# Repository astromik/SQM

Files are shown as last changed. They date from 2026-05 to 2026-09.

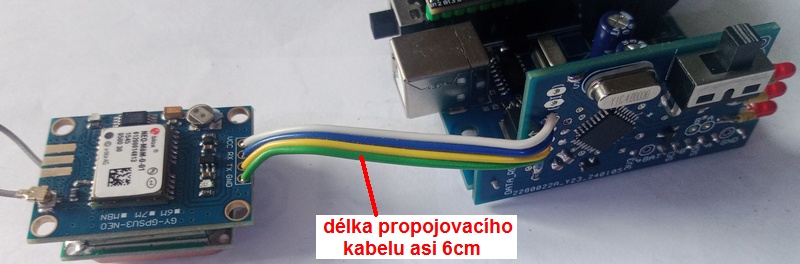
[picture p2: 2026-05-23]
SQM_verze411/webconfig/fot_gps_propoj.jpg

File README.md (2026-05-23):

<B>Amatérské SQM - Sky Quality Meter</B><br><br>Levnější a funkčně více vybavená náhrada za profesionální měřič kvality oblohy od Unihedronu postavená na procesoru STM32F411CEU s využitím modulu pro měření jasu TSL2591.

- Záznamy se ukládají na SD kartu (čitelný CSV formát) a do vnitřní EEPROM, ze které je možné záznamy exporovat.<br>
- Měření teploty, tlaku a vlhkosti.<br>
- K záznamům se přidávají GPS souřadnice a směr měření (azimut a  elevace).<br>
- Astronomické výpočty (poloha Slunce, Měsíce, planet, vybrané DSO).<br>
- Komunikace přes RS485 (modbus), nebo přes USB.<br>
- Možnost automatického měření v nastavených intervalech.<br>
- Další drobné funkce (stopky, budík, časová značka, červená lampička, GPX trasovací soubor).<br>
- Kalibrace pomocí porovnání s originálním (přesným) SQM přes editovatelné kalibrační tabulky.

Web: http://sqm.astromik.org/<br><br>

sqm411

sqm411-vnitrek

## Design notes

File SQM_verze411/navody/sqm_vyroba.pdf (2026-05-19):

# Měřič kvality oblohy

# (amatérské SQM)

# Popis HW a výroba

http://sqm.AstroMiK.org

## STM32F411CEU

SW: | STM32 | 2026-05-18 (STM32F4x1)
| ATmega328 | 2026-05-17..INT
PCB: | základní deska | SQM-BAS-7
| deska vnitřního GPS | SQM-GPS-6
| deska displeje | SQM-DIS-3
3D tisk: | krabička + podstavec | SQM-96

19.5.2026

Strana 1/61

## OBSAH

## Úvod

Tato část návodu popisuje výrobu SQM včetně mechaniky a nahrání programu, testování jednotlivých částí a případné opravy, když něco nebude fungovat.

## Rozšiřující bloky

V prvním plánu bylo vytvoření pouze dvou variant SQM:
- Ruční přístroj s displejem, tlačítky a možností osazení GPS, který bude používán v terénu.
- Pevně nainstalovaný přístroj s minimálním vybavením, který bude komunikovat dálkově přes RS485.

Později bylo toto rozdělení přepracováno tak, aby si uživatel mohl zvolit rozsah požadovaných funkcí. Zvolené funkce mají samozřejmě vliv na celkovou cenu, i když v některých případech jsou to spíše desetikorunové částky.

V té nejořezanější verzi je možné jen po stisknutí tlačítka (nebo v automatických intervalech) změřit jas, uložit hodnotu do paměti
a přes USB sériovou linku pak uložené záznamy z paměti stáhnout do počítače.
Není k dispozici ani displej, který by hodnotu ukazoval a jedinou signalizací je (nepovinná) RGB LED, která barvami signalizuje základní stavy (probíhající měření, chyby).

V maximální verzi se změřené záznamy zobrazují na displeji, ukládají se kromě paměti i na SD kartu a zároveň se měří teplota, tlak a vlhkost.
K záznamům se přidávají i GPS souřadnice, směr namíření čidla (azimut a elevace).
Data je možné stahovat dálkově přes průmyslovou sběrnici RS485 (protokol modbus RTU).
Přes modbus je možné nastavovat i některé systémové parametry (čas, úrovně ukládání hodnot, změnu časové zóny ...).
Když je osazený displej, je možné zobrazit i astronomické výpočty (polohy Slunce a Měsíce, časy soumraků pro zvolenou polohu, polohy a časy východů a západů planet), nebo listovat ve starších záznamech (záznamy se v tom případě zobrazují na displeji ve zjednodušeném formátu).
Osazená akustická signalizace může hned při měření upozornit na nestabilní měřené hodnoty nebo na vybitou baterii.
Rozšíření o alarmové funkce z SQM vytvoří budík, který se v nastavený čas spustí i při vypnutém hlavním vypínači.

Protože možných kombinací rozšíření je strašně moc (2^13 = 8192 různých kombinací), připravil jsem webovou stránku,
na které se pomocí zaškrtávacích políček zvolí požadovaná rozšíření a podle zvolené verze se automaticky připraví balík výkresové dokumentace pro osazení desek včetně seznamu součástek pro konkrétní zvolenou variantu.
Součástí balíku jsou také náčrtky připojení vnějších spojů (tlačítka, napájení, svorkovnice ...) a fotografie některých detailů osazení.

Dále jsou v balíku i podklady pro výrobu plošných spojů ve formátu pro Eagle a výstupní gerberovské soubory pro výrobu například tady: https://jlcpcb.com

Webový formulář pro konfiguraci rozšiřujících funkcí je zde: http://astromik.org/raspi/sqm/verze411/webconfig/

## Výroba

Webový konfigurátor

Výroba začíná volbou požadovaných funkcí na stránce:

http://astromik.org/raspi/sqm/verze411/webconfig/

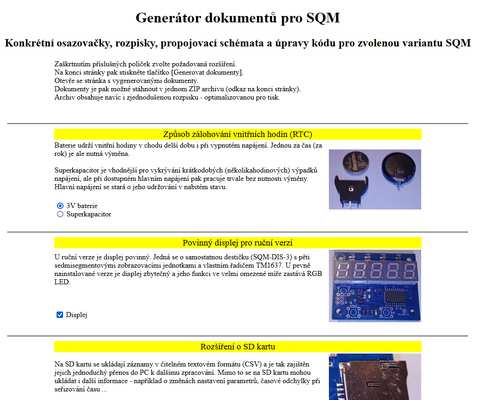
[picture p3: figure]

Po stisku tlačítka "Generovat dokumenty" na konci stránky se připraví rozpisky a osazovačky pro zvolenou variantu.

POZOR

Mechanika je v rozpiskách zpracována pouze pro ruční verzi.
V případě pevně nainstalovaného přístroje si musí uživatel s mechanikou poradit sám.

Tuto pevnou variantu jsem zatím mechanicky neřešil.

Pravděpodobně to bude nějaká vodotěsná krabička, do které budou přes průchodky přivedena čidla a napájení s komunikací. Samotná čidla také musí být nějakým způsobem ochráněna před počasím.

Protože se u pevně nainstalované varianty nepočítá s displejem, měla by být zvenku vidět alespoň signalizační RGB LED.

Tlačítka nejsou v této verzi důležitá, ale pro případný servis (testování čidel, spuštění zkušebního měření, test nastaveného času,...) by uvnitř krabičky mohla být nějaká miniaturní tlačítka (nebo alespoň rozumně zkratovatelné kontakty) umístěná.

Čidla světla a teploty komunikují na společné I²C sběrnici a mohly by být vyvedeny přes jednu průchodku (připojeno místo konektoru EXT). Délka kabelu k čidlům by neměla být moc dlouhá. I²C sběrnice se používá obvykle jen pro komunikaci uvnitř krabice, takže délka by neměla přesáhnout několik desítek centimetrů.

Komunikační (RS485) a napájecí kabel (například UTP kabel SXKD-5E-UTP-PE) by byl přiveden do krabičky přes druhou průchodku (připojeno ke svorkovnicím K1+K2).

schématické uspořádání v pevně nainstalované verzi (bez GPS)

## Osazení desek

Osazení desky SQM-BAS

Před osazením desek si projděte poznámky před osazením. Je tam upozornění na některé detaily, které by mohly být problematické.

Osadit desku SQM-BAS-7 podle požadovaných funkcí.
Přídavné moduly čidel ale zatím neosazovat.
Nepřipojovat ani další přídavné desky (SQM-GPS-6 ani SQM-DIS-3). Nevkládat do patice procesorovou desku BlackPill.
Nepřipojovat žádná tlačítka ani konektory (DC-JACK, 9V klip). Nevkládat SD kartu.
Pokud je osazena verze s 3V zálohovací baterií, tak ji také nevkádat do držáku.

V tomto stavu se později budou provádět základní testy zdrojové a komunikační části desky SQM-BAS-7.
Popsáno v odstavci "Samostatná deska SQM-BAS"

Osazení desky SQM-DIS

Pokud bude použita deska displeje, osadit ji podle dokumentace. Nepájet propojovací piny JP1-M a JP2-M.
Jejich délka se nastaví až na závěr při sestavení s deskou SQM-BAS-7 přes distanční sloupky.

Osazení desky SQM-GPS

Pokud bude použita deska zpracování GPS dat (SQM-GPS-6), osadit ji podle dokumentace. Pozor hlavně na propojovací lištu JPx-M a vdálenost LED od desky.
Detaily v poznámkách před osazením.

Naprogramovat procesor Atmega328 v desce SQM-GPS-6. Popsáno v kapitole "Nahrání programu do desky SQM-GPS"

Vypájet provizorní programovací piny.

Pomocí 4-žilového plochého kablíku (délka asi 6cm) propojit desku SQM-GPS-6 s modulem NEO6-M

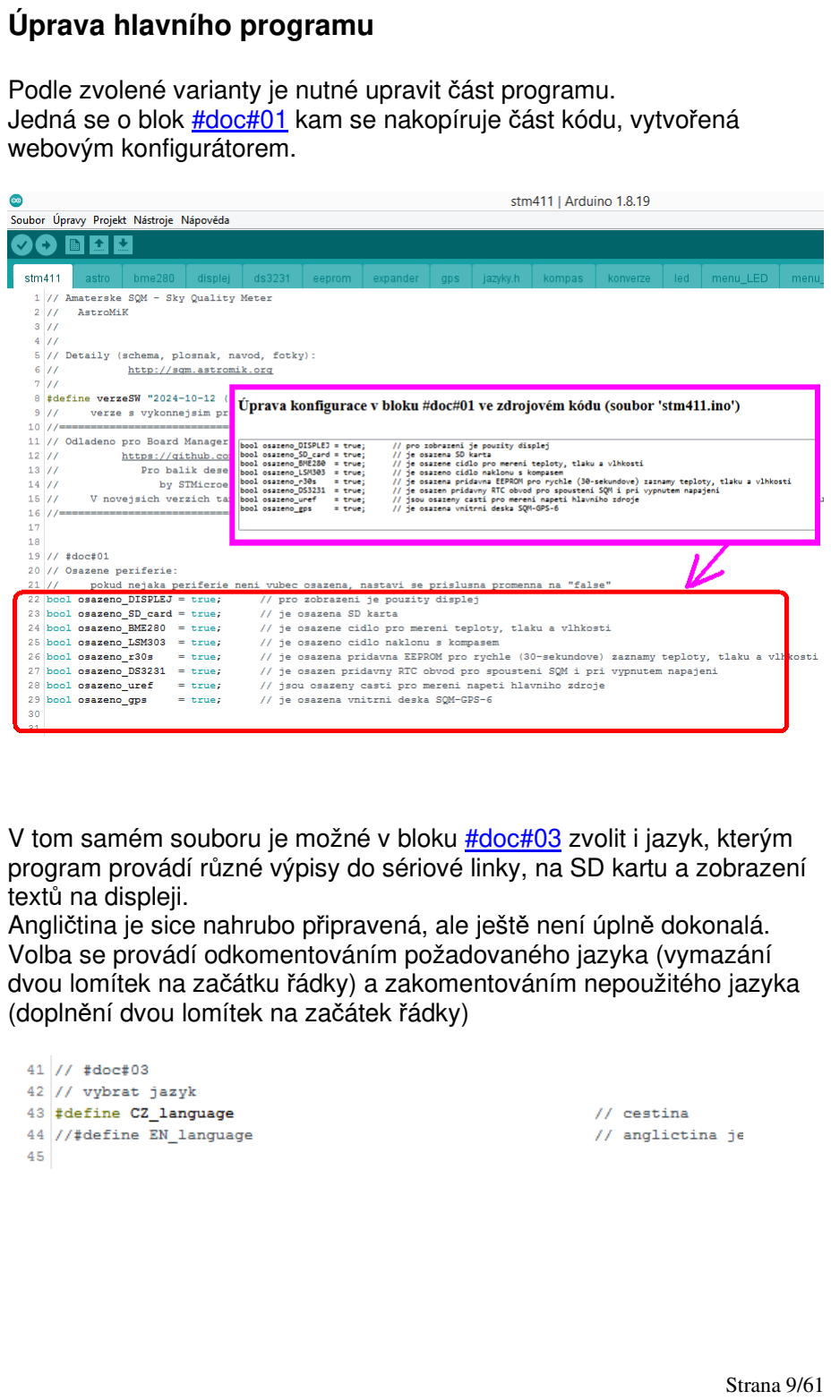
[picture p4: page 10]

Úprava hlavního programu

Podle zvolené varianty je nutné upravit část programu.
Jedná se o blok #doc#01 kam se nakopíruje část kódu, vytvořená webovým konfigurátorem.

V tom samém souboru je možné v bloku #doc#03 zvolit i jazyk, kterým program provádí různé výpisy do sériové linky, na SD kartu a zobrazení textů na displeji.
Angličtina je sice nahrubo připravená, ale ještě není úplně dokonalá. Volba se provádí odkomentováním požadovaného jazyka (vymazání dvou lomítek na začátku řádky) a zakomentováním nepoužitého jazyka (doplnění dvou lomítek na začátek řádky)

Program je přednastavený pro ukládání hodnot všech (i nepoužitých) čidel do EEPROM. V bloku #doc#05 je možné pro nepoužitá čidla ukládání omezit.

Detailní postupy pro úpravy konfigurace programu jsou uvedeny
v samostatném programovacím návodu
(soubor "sqm_program.doc").

Úprava desky BlackPill

Procesorová deska BlackPill musí mít boční piny (GND, SWSCK, SWDIO a 3V3) osazené směrem dolů (stejně jako ostatní piny).

Pro správné měření napětí 3V zálohovací baterie je nutné uříznout na desce BlackPill nohu na diodě D3 (na některých schématech označovaná jako D1) - BAT54C. Tato dioda slučuje napájení procesoru a 3V zálohovací baterii do měřícího vstupu. Bez této operace by se místo napětí baterie měřilo napájecí napětí procesoru.

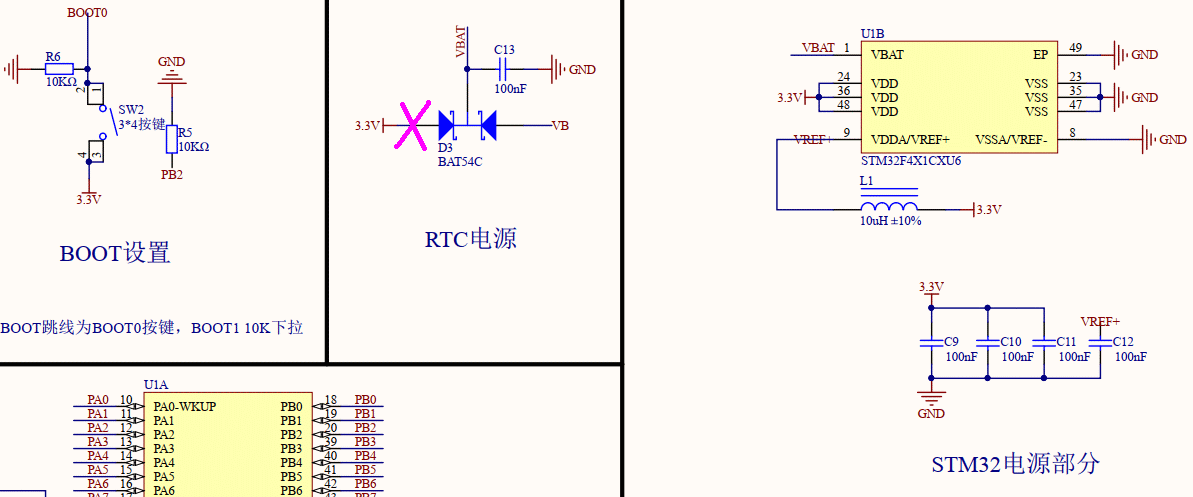
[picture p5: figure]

Část schématu s naznačeným přerušením napájecí sběrnice 3,3V a vstupem pro měření napětí baterie VBAT

Detail přerušení anody u dvojdiody D3 (někde označovaná jako D1)

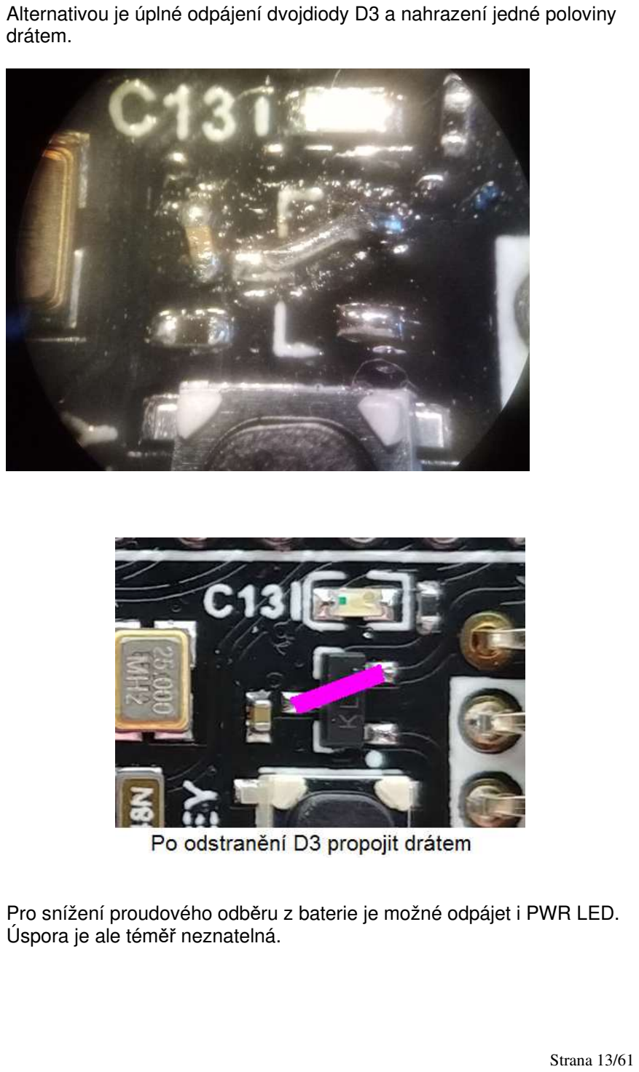
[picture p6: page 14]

Alternativou je úplné odpájení dvojdiody D3 a nahrazení jedné poloviny drátem.

Pro snížení proudového odběru z baterie je možné odpájet i PWR LED. Úspora je ale téměř neznatelná.

## Nahrání a případná aktualizace programů

Nahrání programu do desky BlackPill

V první řadě je nutné připravit Arduino IDE na práci s procesory STM. Na internetu je možné najít množství přesných návodů s různými verzemi knihoven na rozšíření IDE pro práci s procesory STM.
Já jsem jako základ použil tenhle: https://www.sgbotic.com/index.php?dispatch=pages.view&page_id=49

Je ale už trochu zastaralý, takže je třeba nastavit jinou URL správce desek.

Postup je následující (odzkoušeno na Arduino IDE verze 1.8.19; Windows 8.1 - 64-bit):

1) V menu "Soubor" -> "Vlastnosti" nastavit URL správce dalších desek:
https://github.com/stm32duino/BoardManagerFiles/raw/main/package_stmicroelectronics_index.json
2) v menu "Nástroje" -> "Vývojová deska" -> zvolit "Manažer desek" Do vyhledávacího políčka zadat: STM
Měla by se zobrazit knihovna STM32MCU based boards. Nainstalovat STARŠÍ verzi 2.6.0! V nových verzích pořád něco upravují a já už nemám sílu neustále program přizpůsobovat.)

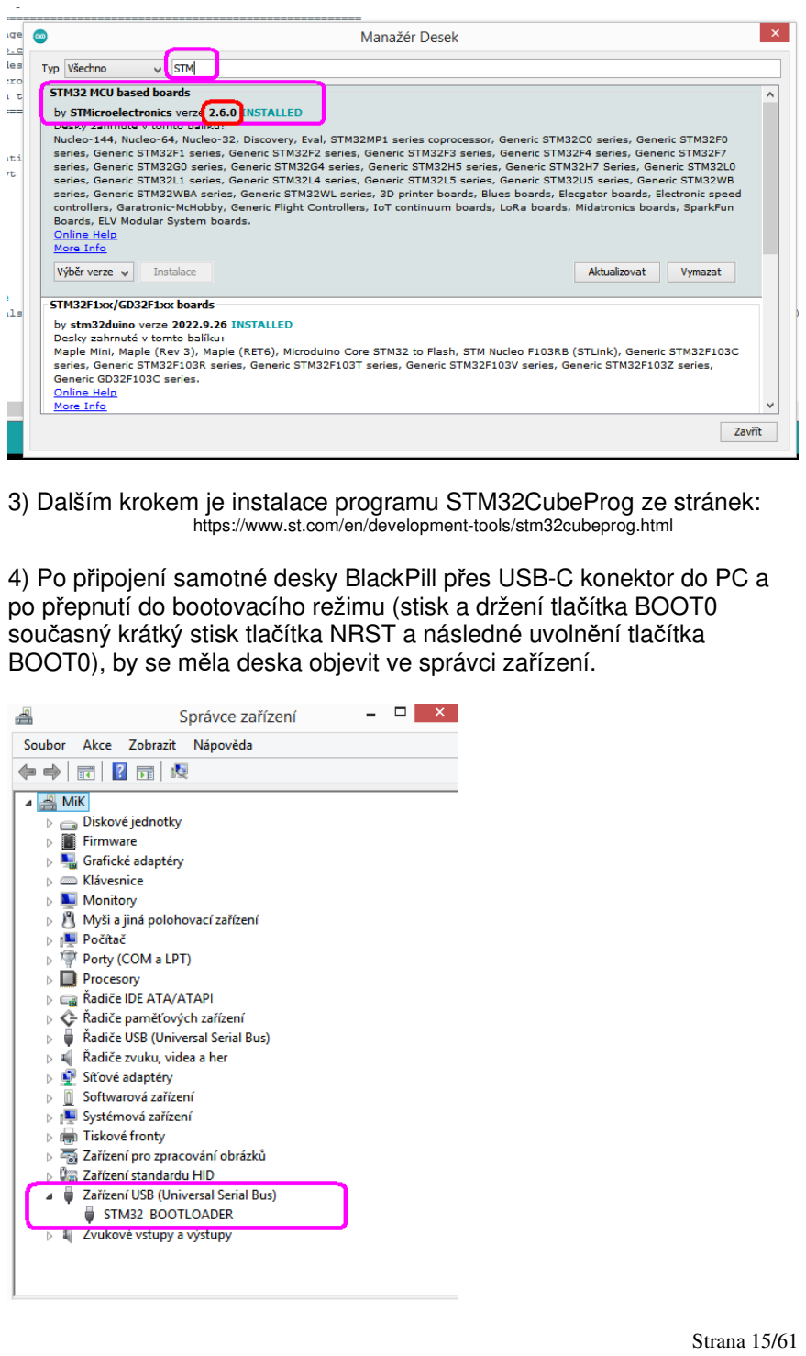
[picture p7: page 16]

3) Dalším krokem je instalace programu STM32CubeProg ze stránek:
https://www.st.com/en/development-tools/stm32cubeprog.html
4) Po připojení samotné desky BlackPill přes USB-C konektor do PC a po přepnutí do bootovacího režimu (stisk a držení tlačítka BOOT0 současný krátký stisk tlačítka NRST a následné uvolnění tlačítka BOOT0), by se měla deska objevit ve správci zařízení.

5) Do složky "Dokumenty\Arduino\Libraries\" nakopírovat potřebné knihovny:
6) Pak už stačí v menu Arduino IDE nastavit správný typ procesoru na desce BlackPill (STM32F411CEU, nebo STM32F401CEU) a parametry.
7) V menu "Projekt" zvolit položku "Nahrát". Proběhne kompilace následovaná nahráním programu do procesoru.

Takto by mělo vypadat hlášení po úspěšném nahrání programu
do procesoru STM32F401 (pro verzi "2024-10-12"):

Projekt zabírá 228920 bytů (43%) úložného místa pro program. Maximum je 524288 bytů.
Globální proměnné zabírají 8816 bytů (8%) dynamické paměti, 89488 bytů zůstává pro lokální proměnné. Maximum je 98304 bytů. -------------------------------------------------------------------STM32CubeProgrammer v2.14.0 -------------------------------------------------------------------
USB speed | : Full Speed (12MBit/s)
Manuf. ID | : STMicroelectronics
Product ID | : STM32 | BOOTLOADER
SN | : 3395364B3334
DFU protocol: 1.1
Board | : --
Device ID | : 0x0433
Device name : STM32F401xD/E Flash size : 8 MBytes (default) Device type : MCU
Revision ID : --
Device CPU : Cortex-M4

Memory Programming ...
Opening and parsing file: stm411.ino.bin
File | : stm411.ino.bin
Size | : 224.01 KB
Address | : 0x08000000

Erasing memory corresponding to segment 0: Erasing internal memory sectors [0 5] erasing sector 0000 @: 0x08000000 done erasing sector 0001 @: 0x08004000 done erasing sector 0002 @: 0x08008000 done erasing sector 0003 @: 0x0800c000 done erasing sector 0004 @: 0x08010000 done erasing sector 0005 @: 0x08020000 done Download in Progress:

File download complete
Time elapsed during download operation: 00:00:22.209

RUNNING Program ...
Address: | : 0x8000000
Start operation achieved successfully
Kdyby bylo nutné v budoucnu aktualizovat program v zasunuté procesorové desce BlackPill, je třeba vypnout vypínač na GPS desce. Zapnutá GPS blokuje nahrávání programu přes USB-C.

Vyzkoušel jsem také použití novějšího Arduino IDE (2.3.7) a instalace rozšíření o desky STM32F4xx probíhá podobně.

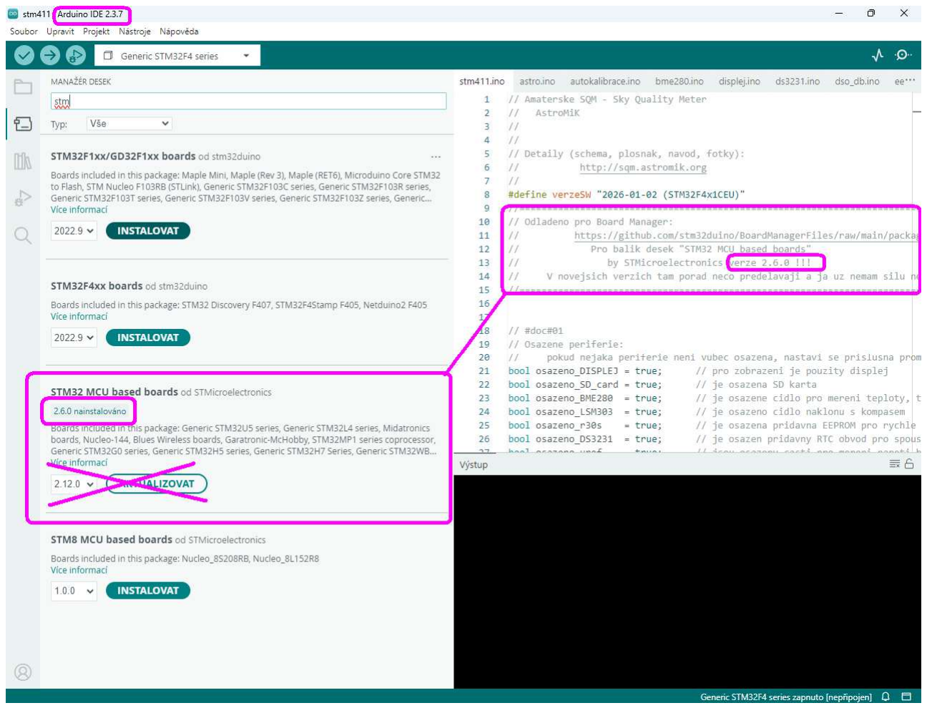
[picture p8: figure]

Osobně ale raději pracuji ve starém Arduino IDE 1.8.xx.

Nahrání programu do desky SQM-GPS

Dočasně přenastavit konfigurační soubor pro Arduino UNO tak, aby pracoval na 4MHz.
Ve Windows se to provede úpravou souboru:
C:\Program Files (x86)\Arduino\hardware\arduino\avr\boards.txt

V sekci "Arduino Uno" se upraví hodnota
"uno.build.f_cpu" z 16000000L na 4000000L

POZOR:
Umístění souboru boards.txt může být i jiné.
Po nějakém čase jsem chtěl aktualizovat program a umístění souboru se změnilo:
C:\Users\astromik\AppData\Local\Arduino15\packages\arduino\hardware\avr\1.8.4\boards.txt

Přes ISP piny (MISO,MOSI,SCK,RST) nahrát do ATmega328 program "gps_int.ino" (v nastavení desky zvolit "Arduino UNO")

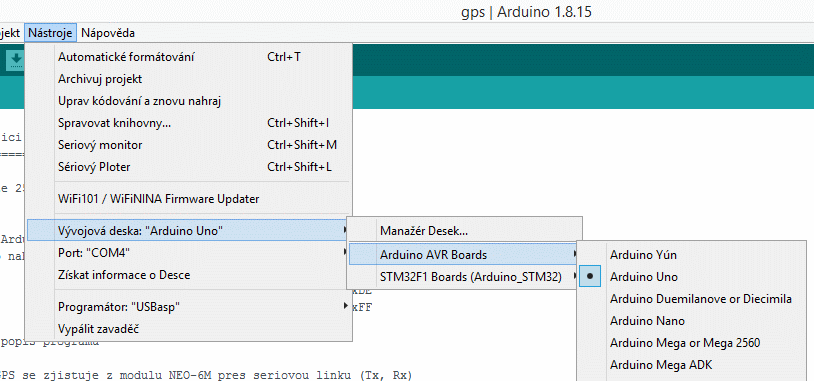
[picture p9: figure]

Vrátit zpět úpravu konfiguračního souboru "boards.txt".

Program pro ATmega328 je připraven ke stažení i v HEX formátu, který je možné nahrát do procesoru přes AVRDUDE. V tom případě není nutné používat Arduino IDE.

Potom přes AVRDUDESS změnit FUSE:
z původních -->> | na nové
L: 0xF7 | L: 0xDC
H: 0xD9 | H: 0xDE
E: 0xFC | E: 0xFF

Po nahrání programu do desky SQM-GPS a úpravě FUSE bajtů vypnout napájení programátoru.

POZOR:
Pokud by bylo třeba přeprogramovat desku SQM-GPS až po připájení k SQM-BAS, je nutné, aby byl vypínač na desce SQM-GPS v poloze VYPNUTO!
Programátory mohou používat napájecí napětí 5V. Procesoru ATmega328 na desce SQM-GPS toto napětí nevadí, ale při sepnutém vypínači by se těch 5V přeneslo i na ostatní čidla a procesor STM32F411, které jsou dimenzovány pouze na 3,3V. Tím by pravděpodobně došlo k jejich zničení.

Nastavení konfigurace GPS

Při vypnutém napájení propojit pinzetou servisní pin na horní straně desky SQM-GPS a následně napájení programátoru opět zapnout.

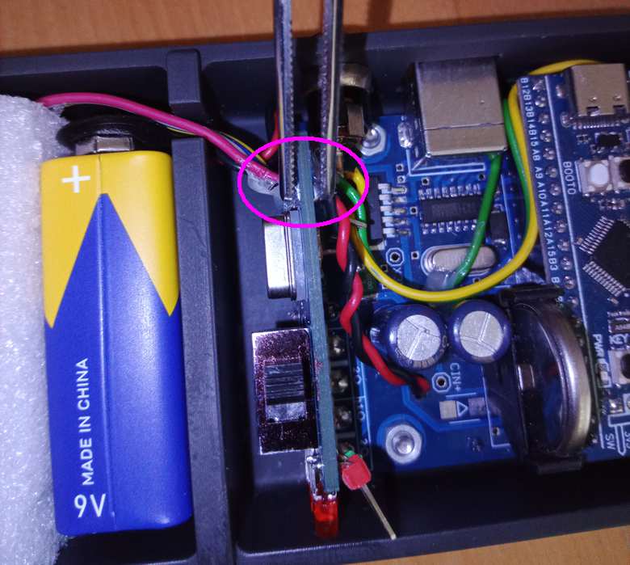
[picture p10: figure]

Operace se provádí na samotné desce GPS, která ještě není připojena do BAS. Tato fotografie byla pořízena až po propojení desek BAS a GPS.

Po zapnutí napájení se sepnutým servisním kontaktem by měly nejdřív 5x bliknout všechny LED frekvencí 1Hz (střída 50%).
Pak se začnou pomalu postupně rozsvěcet a zhasínat.
Při tom je možné propojovací pinzetu odstranit.
Asi po 30 sekundách se znovu rozblikají všechny LED (střída 10%).

Tím je provedena základní konfigurace GPS modulu (zablokování nechtěných NMEA zpráv a povolení zpráv GxGGA a GxRMC).

Vypnout napájení programátoru.

Odpojit ISP vodiče a případně i vypájet ISP piny.

Plochý kablík z modulu NEO-6 připájet k desce SQM-GPS-6

Při dalším zapnutí napájení bez zkratované servisní propojky už bude GPS deska pracovat normálně. První LED zdola bliká frekvencí 1Hz, ostatní LED nejdřív svítí a po zafixování družic postupně zhasnou. Zafixování může trvat i delší dobu v závislosti na počasí a výhledu na oblohu.

Kvůli novějším GPS modulům NEO, které nemají EEPROM, do které by se ukládala konfigurace, se v posledních verzích FW při každém zapnutí napájení nastavuje konfigurace znovu. Je to ale ve zrychleném režimu který je signalizován postupným rozsvěcením bočních LED.

Ukázkové video:
https://youtu.be/Dz852uCeeco

## Testy samostatných desek

Samostatná deska SQM-BAS

POZOR!
V této fázi:
- nevkládat modul s procesorem
- nevkládat SD kartu
- nepřipojovat čidlo světla ani čidlo teploty / vlhkosti / tlaku
- nepřipojovat čidlo náklonu / kompas
- nepřipojovat desku SQM-DIS
- nepřipojovat desku SQM-GPS

Na následujících fotografiích mohou být vidět některé z těchto věcí připojené, ale je to z toho důvodu, že návod vznikal dodatečně -
až s hotovým zařízením.
1) Kontrola zkratu na napájení. Stačí ohmmetrem vyzkoušet, že není zkrat mezi body "XG" a "X3V". Přesnou hodnotu odporu tu uvádět nebudu, asi se bude hýbat podle toho, jak se budou nabíjet napájecí kondenzátory. V žádném případě to ale nesmí být zkrat. Rizikové oblasti, kde se napájecí cesta přibližuje ke GND, jsou hlavně kolem držáku SD karty a RGB LED. Stalo se mi, že k nechtěnému zkratu došlo později, při pájení modulu s čidlem světla.

Tento test je proto vhodné provádět i po připojení každého dalšího čidla. Zkrat na napájení se hledá dost těžko a obvykle je nutné hledat ho pomocí odřezávání částí cestiček na DPS.

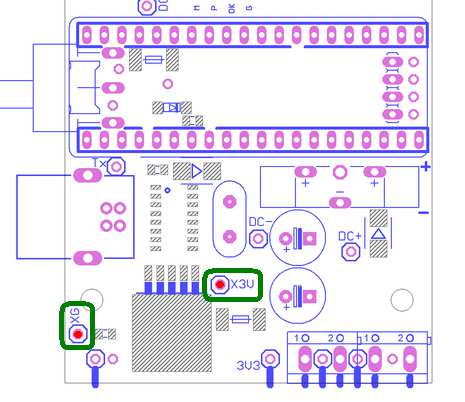
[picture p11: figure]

poloha měřících bodů XG a X3V

2) Kontrola DC-DC převodníku:
- Připojit voltmetr mezi body "XG" a "X3V".
- Připojit 9V baterii nebo zdroj do svorek "V" a "G" na svorkovnicích K1 a K2 (pokud svorky nejsou osazeny, připájet napájecí vodiče zdroje do dírek "V" a "G").
- Hlavní boční přepínač přepnout do polohy "zapnuto".
- Voltmetr musí ukazovat 3,3V s minimální tolerancí.
- Místo baterie připojit regulovatelný zdroj napětí 3 až 30V.
- Když vstupní napětí překročí 4,5V, musí být napětí
na voltmetru (v bodě "X3V") stále 3,3V.
Pod 4,5V může napětí na voltmetru začít klesat.
3) Kontrola reference a děliče R7/R8:

Od vstupního napětí alespoň 4V by mělo být na pinu PB0 proti GND vždycky 1,8V.
Na pinu PA0 by mělo být proti GND napětí, které je asi 8% ze vstupního napětí (teoreticky je dělící poměr: 8,2 / 108,2 ).
Ani při 30V na vstupu nesmí toto napětí překročit 3,3V.

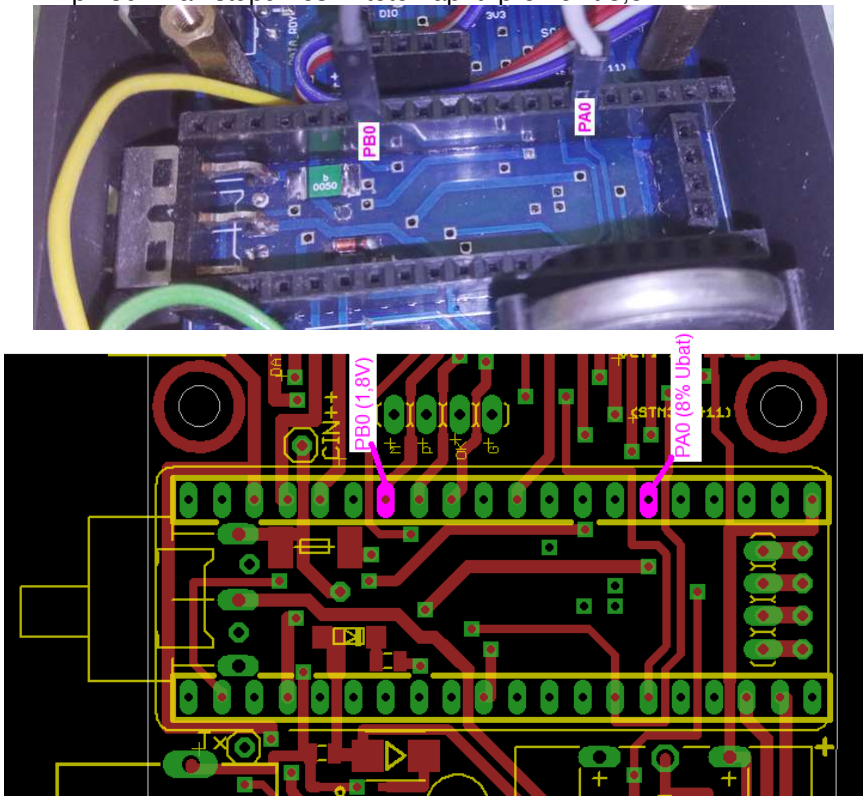
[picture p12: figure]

3) Kontrola ochrany přepólování:
Na svorky baterie připojit 30V v opačném směru.
Voltmetr nesmí mezi body "XG" a "X3V" ukazovat žádné napětí a odběr ze zdroje 30V musí být také nulový.
4) Kontrola USB komunikace:
Odpojit 9V baterii (nebo zdroj).
Stále bez zasunuté procesorové desky připojit USB konektor k počítači Měly by se nainstalovat ovladače pro převodník CH340.
Pokud se nenainstalují, postupovat podle:
https://havel.mojeservery.cz/ovladace-usb-serioveho-portu-s-cipsetem-ch340ch341-a-arduino-klony/

nebo:
https://blog.laskarduino.cz/instalace-ovladace-prevodniku-usb-na-uart-ch340/

Když instalace proběhne správně, propojit dírky v patici pro modul BlackPill na pozicích PA9 a PA10.

V počítači spustit sériový terminál, zvolit správné číslo právě vytvořeného sériového portu, nastavit rychlost na 9600.
Znaky, které se přes terminál odešlou do linky, se musí okamžitě vracet zpátky.

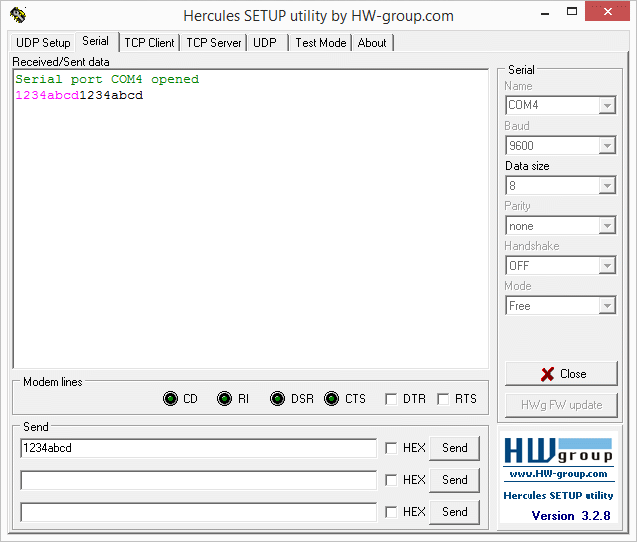
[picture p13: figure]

Vyzkoušet i vyšší rychlosti (až do 115200).

Zrušit propojku mezi PA9 a PA10.

Při připojeném USB kabelu ještě zkontrolovat voltmetrem napájecí napětí 5V pro procesorovou desku.

Na těchto pinech by mělo být po připojení USB kabelu napětí asi 5V

pohled opačným směrem (od čidla světla)

Samostatná deska SQM-DIS

V této fázi by neměly být ještě osazené kolíkové lišty.
Na samotné desce je možné zkontrolovat, že nemá zkratované napájecí cesty. Ostatní testy se provádí až později při spojení s SQM-BAS.

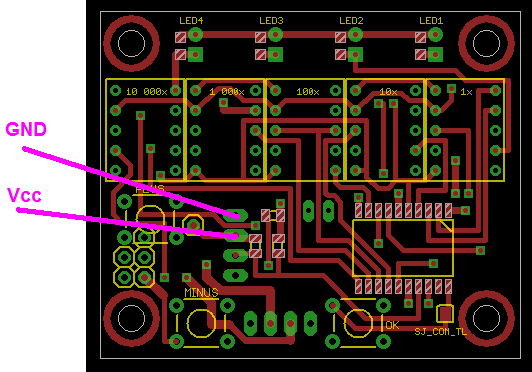
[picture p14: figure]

kontrola zkratu na napájecích pinech

Samostatná deska SQM-GPS

Deska SQM-GPS už by měla být otestována tím, že se podařilo nahrát program do procesoru ATmega328.
Okamžitě po zapnutí napájení mělo proběhnout postupné probliknutí všech LED.
Dalším testem je blikání spodní LED (pokud je připojený GPS modul NEO).

## Sestavení desek

V této kapitole předpokládám, že se jedná o plně vybavenou ruční verzi přístroje (displej, GPS, čidlo BME280, kompas + náklonoměr).
Pokud něco z toho není použito, tak není třeba se tím zabývat.

Pokud je použita deska displeje (SQM-DIS-3), provést sestavení desek SQM-BAS-7 + SQM-DIS-3 přes 15mm dlouhé sloupky.
Nepřipájené propojovací kolíky JP1-M a JP2-M, se při sešroubování desek vytlačí nad horní okraj desky SQM-DIS-3.
Přečnívající kolíky zastřihnout a připájet do SQM-DIS-3.
Tím je zajištěna správná délka propojovacích kolíků mezi deskami SQM-BAS a SQM-DIS

Displejovou desku s připájenými spojovacími piny odebrat aby byl prostor pro instalaci čidel.

K deskám začít připojovat použitá čidla
Pokud je k dispozici krabička, připájet čidlo světla (TSL2591) a v případě, že je použito, tak i čidlo teploty (BME 280).
U čidla světla věnovat zvýšenou pozornost správnému zamíření senzoru proti čočce, která je vlepená do krabičky.

Nejlepší postup je vlepit do krabičky čočku, přišroubovat základní desku bez čidel do krabičky, nastavit správný směr a vzdálenost čidla světla od čočky a připájet jeden vývod.

Podobně provést umístění i čidla teploty.
Když budou čidla správně umístěna, je možné vyndat základní desku z krabičky a dopájet zbylé vývody čidel.

Průběžně kontrolovat zkrat na napájecích vodičích mezi body "XG" a "X3V".

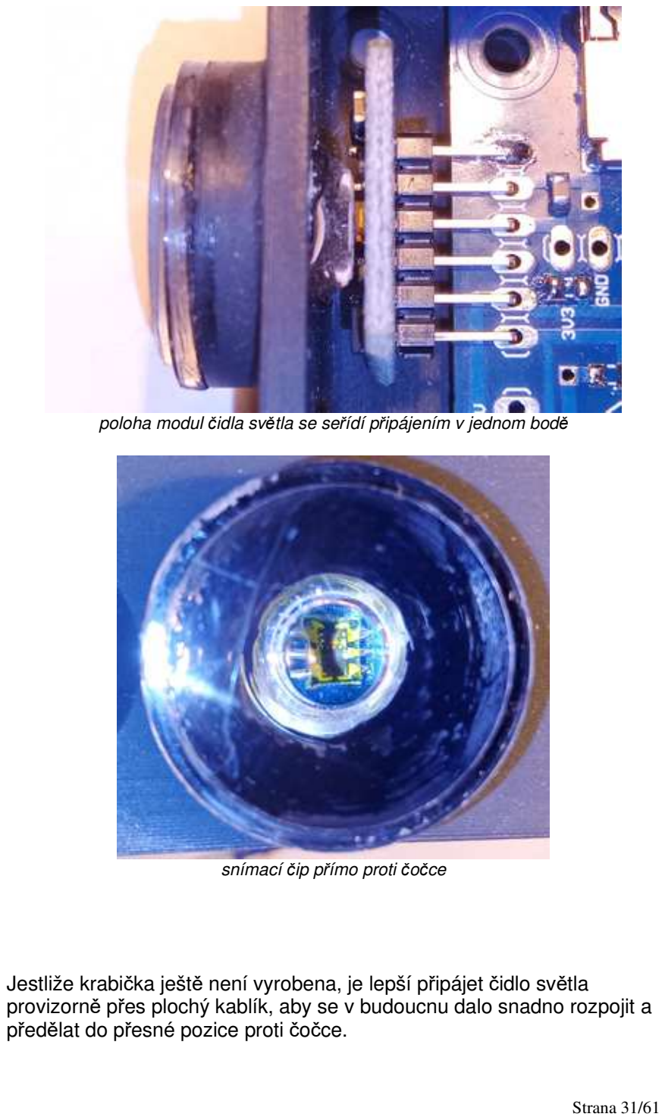
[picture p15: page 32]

poloha modul čidla světla se seřídí připájením v jednom bodě

snímací čip přímo proti čočce

Jestliže krabička ještě není vyrobena, je lepší připájet čidlo světla provizorně přes plochý kablík, aby se v budoucnu dalo snadno rozpojit a předělat do přesné pozice proti čočce.

Podobně postupovat i s čidlem BME - tam ale na přesnosti až tak moc nezáleží.

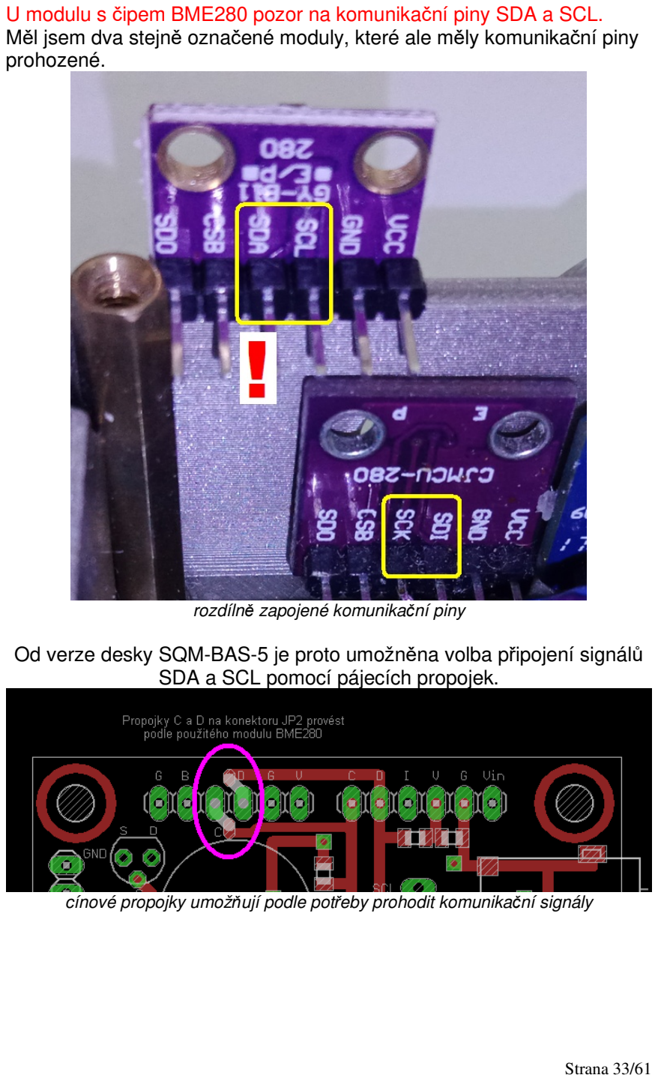
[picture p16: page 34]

U modulu s čipem BME280 pozor na komunikační piny SDA a SCL. Měl jsem dva stejně označené moduly, které ale měly komunikační piny prohozené.

rozdílně zapojené komunikační piny
Od verze desky SQM-BAS-5 je proto umožněna volba připojení signálů SDA a SCL pomocí pájecích propojek.

cínové propojky umožňují podle potřeby prohodit komunikační signály

pájecí propojky C a D propojené na správné piny

Když bude použit kompas s čidlem náklonu, připojit ho k desce SQM-BAS-7 přes 6cm dlouhý, 4-žilový plochý kablík.

Kablík nepájet skrz dírky do modulu, ale naplocho ze strany součástek, aby spodní strana zůstala rovná.

Modul LSM303 se ve finále přilepí (tavným lepidlem) na desku SQM-DIS (přímo na obvod pro řízení displeje TM1637).
Šroubek pro připevnění desky displeje pod modulem LSM303 nepoužívat. Mohl by ovlivňovat magnetické pole kompasu.

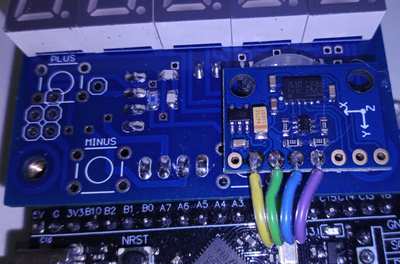
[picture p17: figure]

modul kompasu nalepený na displejové desce (na obvodu TM1637)

Sestavit všechny použité desky dohromady (SQM-BAS-7 + SQM-GPS-6 + SQM-DIS-3). Při sestavování SQM-GPS-6 a SQM-BAS-7 dbát na dokonalou kolmost obou desek, aby přepínač pasoval do otvoru v horním víku krabičky.

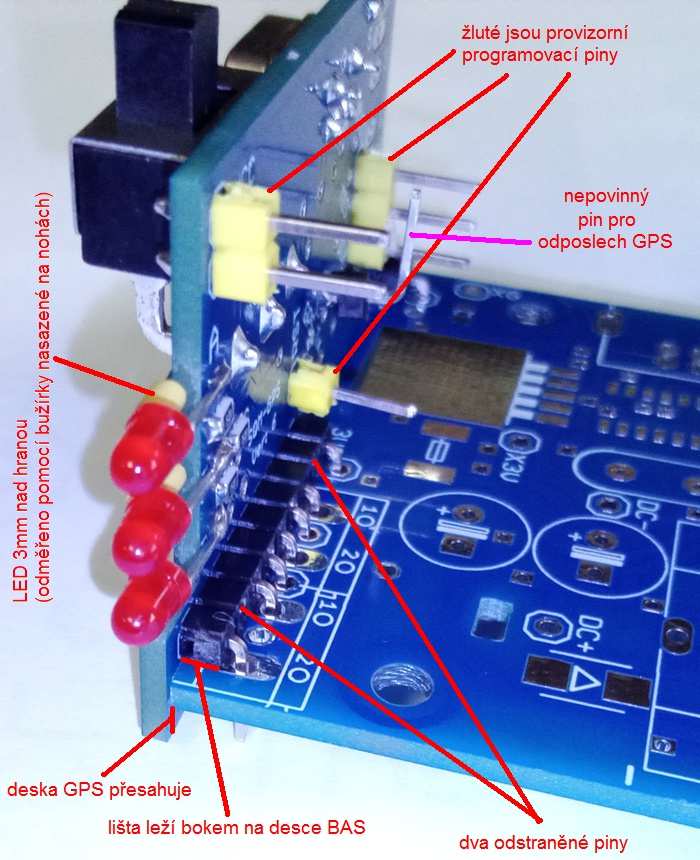
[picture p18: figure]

Zasunout naprogramovanou procesorovou desku BlackPill do patice. POZOR, ABY SE NEZASUNULA O PIN VEDLE!

Pro verzi s SD kartou si připravit zformátovanou kartu a nakopírovat na ni složku /HELP/, která obsahuje detailní popisy příkazů. Tyto popisy se pak mohou zobrazovat v sériovém terminálu.

Složka "HELP" je uložena na webu v adresáři s návody: http://astromik.org/raspi/sqm/verze411/download/navody/

Je tam i ZIP archiv celé složky pro jednodušší přenos. Tento ZIP je pak ale nutné na kartu ručně rozbalit.

Pak kartu zasunout do držáku na desce SQM-BAS.

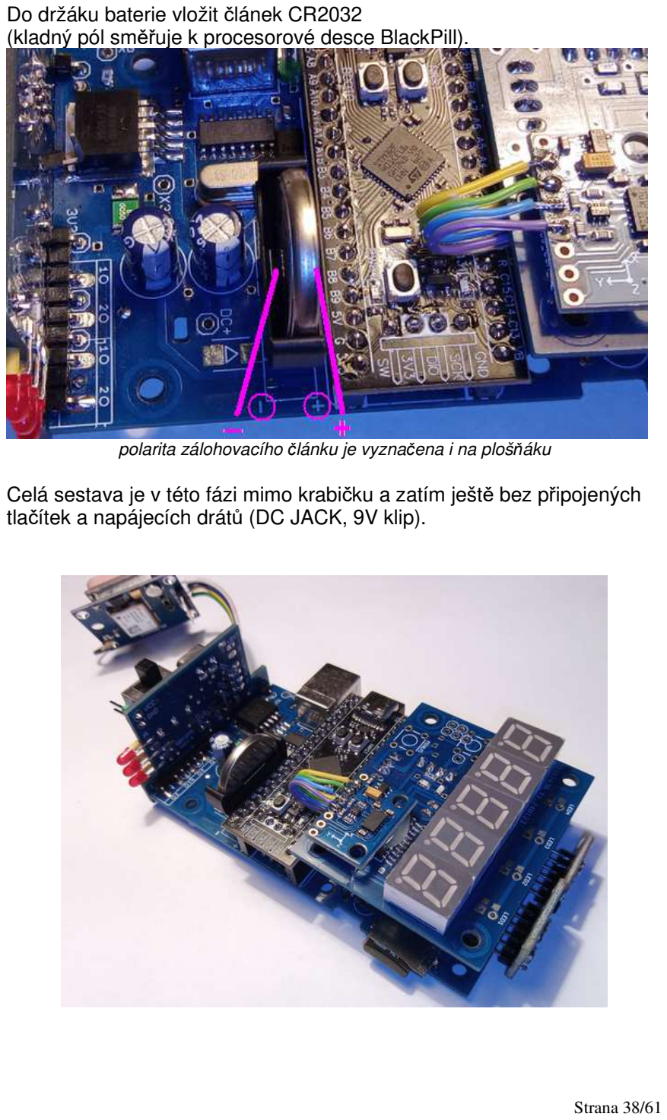
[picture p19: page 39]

Do držáku baterie vložit článek CR2032
(kladný pól směřuje k procesorové desce BlackPill).

polarita zálohovacího článku je vyznačena i na plošňáku
Celá sestava je v této fázi mimo krabičku a zatím ještě bez připojených tlačítek a napájecích drátů (DC JACK, 9V klip).

První spuštění

Provést první připojení sestavy desek a čidel přes USB konektor na desce SQM-BAS-7 do PC.

Při prvním zapnutí napájení se automaticky provede nastavení základních parametrů a kalibračních konstant. Při tomto nastavování, které trvá asi 30 sekund, se na prostřední segmentovce displeje (pokud je použitý) zobrazí rotující obdélník.
Zároveň s tím bliká RGB LED (pokud je osazena) a pípák (pokud je osazený) bzuká různě vysokými tóny.
Ukázkové video na YouTube
https://youtu.be/DSOx0NLRg6o

Když je něco špatně, zobrazí se na displeji chybové hlášení
- "noSd" = není zasunuta SD karta
(není to chyba, jen upozornění, program bude pokračovat dál)
- "Err-i" = chyba I²C komunikace
(zkrat na signálech SDA, SCL, vadná paměť, problém na čidlech)

Ve variantě bez displeje bliká při chybě I²C komunikace modrá LED a pískák v sekundových intervalech pípá vysokým tónem.

Pokud není vůbec žádná reakce (displej je zhasnutý, LED nebliká, pípák nepípá) odpojit USB kabel a hledat problém.
- zkrat na napájení
- vadná, nebo špatně naprogramovaná deska BlackPill
- deska BlackPill zasunutá o pin vedle
(v tom případě už je pravděpodobně na vyhození)

Když je všechno v pořádku, program se po nastavení defaultních parametrů restartuje a přejde automaticky do testovacího režimu (na displeji svítí nápis "tESt ", LED 5x rychle zeleně zabliká, pípák 5x bzukne hlubokým tónem).

Na PC spustit sériový terminál (číslo COM portu podle nově vytvořeného portu ve správci zařízení, rychlost 9600 ).

V terminálu by se mělo zobrazit menu s ovládacími znaky.
Pokud se nezobrazí (terminál nebyl v době výpisu textu ještě spuštěný), odeslat do sériového terminálu nějaký nepoužitý znak (například '0') a menu se zobrazí znova:

=============== M E N U =================== a .... sken I2C
b .... test A/D
c .... test EEPROM 128k
d .... test extra EEPROM (r30s) e .... test piskak
f .... test BME280
g .... test TSL2591
h .... test displej
i .... test EXT kontaktu a zasunute karty j .... test tlacitek
k .... test LED
l .... test SD karty
m .... test linky RS485
n .... test GPS
- .... test kompasu a naklonomeru LSM303
p .... odposlech GPS
r .... test RTC v STM32F411
s .... nastaveni nejakeho casu do RTC v STM32F411 t .... bocni vystup na LOW
T .... bocni vystup na HIGH
u .... test casu v RTC DS3231
U .... test probuzeni za 30s
- .... Automenu OFF/ON
x .... navrat z testu HW do normalniho rezimu ===========================================

Provést základní testy osazených periférií.

Detailní popisy testů jsou uvedeny v kapitole HW testovací funkce v návodu k obsluze (soubor "sqm_obsluha.doc").

Odesláním znaku 'x' se testovací režim ukončí.
Kdykoliv později je možné ho znova spustit příkazem @T odeslaným do USB sériové linky.

V této fázi už by měly být v SQM nastaveny defaultní parametry, jako je počet průměrování, domácí souřadnice (50°sš / 15°vd), časové zóny, ...)

Paměť pro data je ale stále zaplněna nesmyslnými hodnotami (pravděpodobně je zaplněna hodnotami 0xFF).

Je nutné paměť přeformátovat. Pro první formátování slouží příkaz #FH. Paměť se tím rozdělí na bloky, jejichž délka odpovídá počtu ukládaných parametrů.
Tato operace trvá asi 20 minut. Během činnosti běží na displeji odpočet a v sériovém terminálu je vidět postupně se zaplňující bargraf.

Další operací je formát přídavné EEPROM pro režim "R30s" (pokud je použita) příkazem %F.
Tento formát je - vzhledem k menší velikosti paměti - výrazně rychlejší. Dokud formát neproběhne, není možné režim "R30s" používat.

Dál se musí nastavit čas. Nejdřív se zvolí časová zóna (pokud se jedná o střední Evropu, tak stačí jen příkaz z0 pro "zimní" čas, nebo z1 pro letní čas.)

Pokud by se jednalo o jiné zóny, je nutné je nejdřív nadefinovat
(popsáno v návodu pro obsluhu (soubor "sqm_obsluha.doc",
kapitola "Popis komunikace přes USB").

Když je nastavena správná časová zóna, nastaví se alespoň nahrubo aktuální místní čas příkazem #Tyyyymmddhhnnss (detaily opět v návodu k použití).

Tím je provedeno základní nastavení a je možné připojit tlačítka a napájecí konektory (bateriový 9V klip a DC Jack).

Když není použita deska SQM-GPS, připájí se klip 9V baterie na desku SQM-BAS do místa svorkovnice (svorky "+BAT" a "GND").
Když je použita deska SQM-GPS, připájí se klip 9V baterie na ní (svorky "BAT" a "G" vedle servisního kontaktu).

Vývody od bateriového klipu se mohou pro zvýšení mechanické odolnosti protáhnout přes obdélníkovou díru v plošném spoji SQM-BAS, která tam byla pro tento účel připravena.

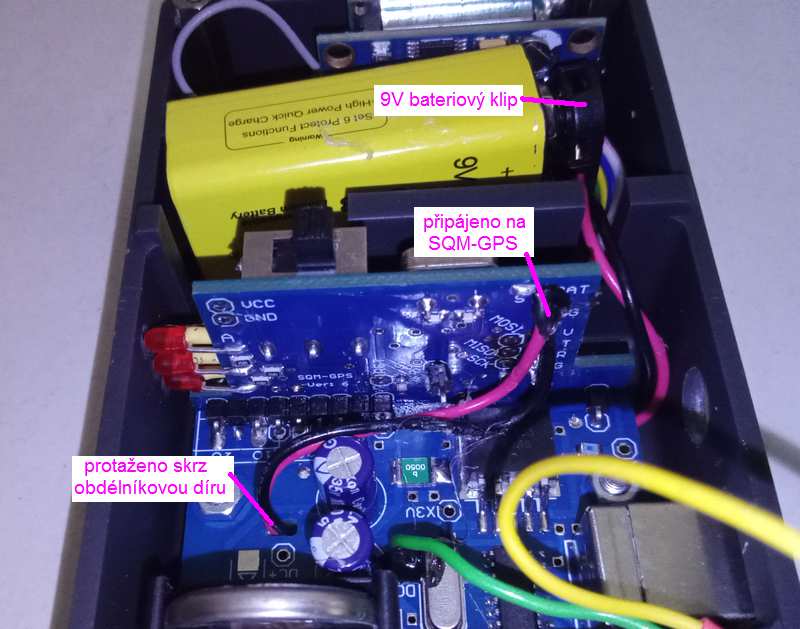
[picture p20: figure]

připojení bateriového klipu na desku SQM-GPS

Na plošném spoji SQM-BAS jsou připraveny i připojovací body pro volitelné externí napájení (5V až 30V).

Používám je pro připojení 12V akumulátoru od dalekohledu přes napájecí DC Jack.
Na plošném spoji jsou body pro připojení tohoto napětí označeny jako DC-, DC+ a DC++.

Na bod DC- se připojí záporný pól napájecího konektoru.
DC+ nebo DC++ slouží k připojení kladného pólu napájecího konektoru. Rozdíl v těchto bodech je v tom, že pin DC+ je vypínatelný bočním přepínačem. Pin DC++ je na poloze bočního přepínače nezávislý (SQM je zapnuté vždycky, když je na napájecím konektoru napětí).

připojení vodičů na DC JACK
V podkladech pro 3D tisk je otvor pro napájecí konektor jen naznačen a v případě, že se použije, se musí ručně dovrtat na průměr 8mm (obrázek níže v kapitole "Mechanika - krabička").

Před zašroubováním tlačítek do horní části krabičky je dobré provést vybarvení předlisovaných nápisů. S těmito věcmi nemám moc zkušeností, ale osvědčilo se mi zaplnit prolisy obyčejnou plastelínou a přeleštit pak celý povrch hadříkem.
Po čase plastelína vyschne a stane se odolnější proti otěru.

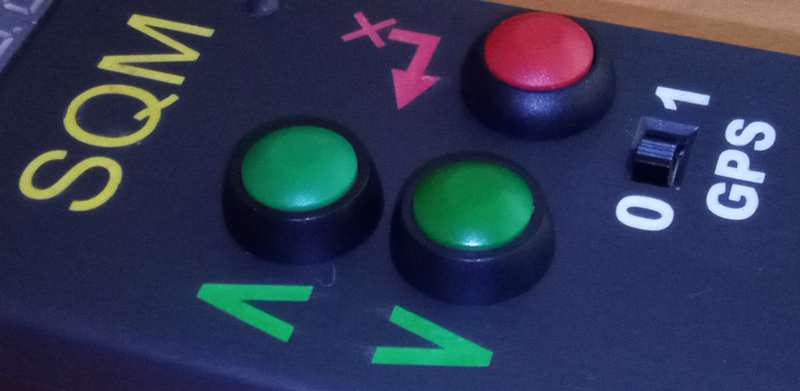
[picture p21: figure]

plastelína v prolisech víčka krabičky
Tlačítka se pak zašroubují do připravených otvorů. Propojení tlačítek s deskou SQM-DIS-3 může být provedeno pomocí 6-žilového, nebo 4-žilového plochého kablíku. Kablík by neměl být moc dlouhý, protože v krabičce není dostatek místa. Doporučuji asi tak 10cm.
V případě použití 4-žilového se musí společný pól (GND) propojit přímo na tlačítkách.
Při použití 6-žilového kablíku jsou na desce SQM-DIS-3 připraveny samostatné otvory pro každou žílu.

Schéma připojení tlačítek je obsažené v dokumentech z webového konfigurátoru

Připojení 4-žilovým plochým kablíkem. (Společné GND je propojené na tlačítkách - červený drát.)

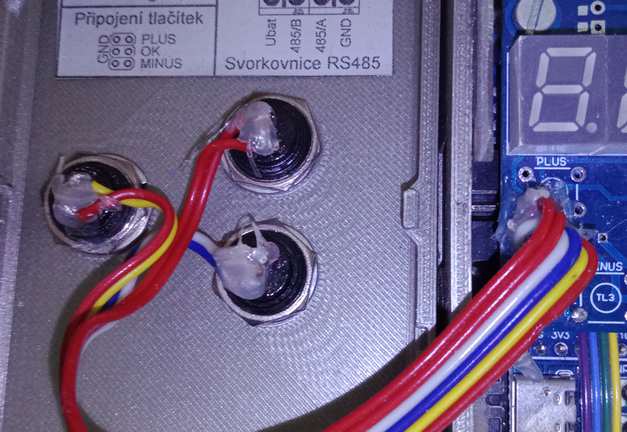
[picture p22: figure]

Propojeni 6-žilovým plochým kablíkem. Každé tlačítko má 2 samostatné dráty, spojení GND je až na desce DIS. (fotografie starší verze krabičky)

V této fázi by tedy sestava měla vypadat nějak takto:

připojená tlačítka, napájecí DC JACK, bateriový klip, GPS modul NEO s anténou, modul náklonoměru přilepený na SQM-DIS, boční dvojtlačítko
Kabely je vhodné mechanicky zafixovat (osobně používám tavné lepidlo do míst, kde jsou kabely připájeny k desce).

Nejnamáhanější bude asi připojení tlačítek na víku krabičky.
Při každém otevření krabičky (výměny baterií) bude docházet k ohýbání vodičů a namáhání spojů. Proto je nutné tyto spoje zafixovat pečlivěji na obou stranách.

## Mechanika - krabička

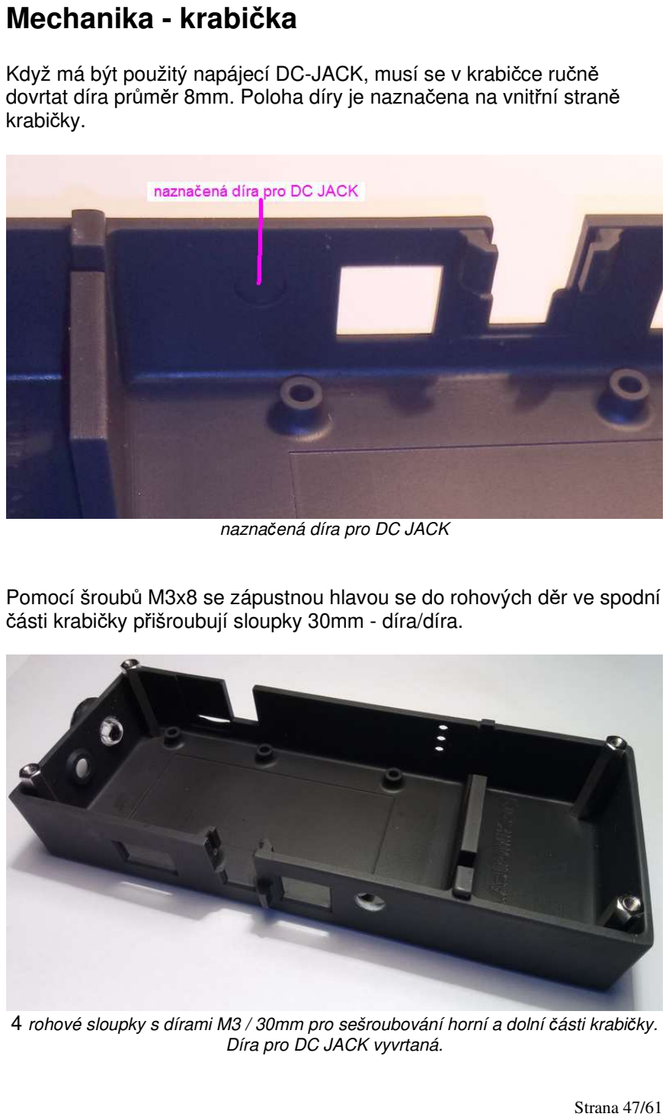
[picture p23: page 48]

Když má být použitý napájecí DC-JACK, musí se v krabičce ručně dovrtat díra průměr 8mm. Poloha díry je naznačena na vnitřní straně krabičky.

naznačená díra pro DC JACK

Pomocí šroubů M3x8 se zápustnou hlavou se do rohových děr ve spodní části krabičky přišroubují sloupky 30mm - díra/díra.

4 rohové sloupky s dírami M3 / 30mm pro sešroubování horní a dolní části krabičky. Díra pro DC JACK vyvrtaná.

Deska SQM-DIS je v této fázi rozpojená v konektorech a visí na kablíku s čidlem náklonu. Zároveň je deska SQM-DIS připojena k tlačítkům v horním dílu krabičky.

SD kartu před vložením desek do krabičky vyndat - je tam málo místa a mohla by se vzpříčit.

Sestava desek se pak vloží do krabičky.

Pomocí šroubů M3x12 se zápustnou hlavou se deska SQM-BAS přišroubuje ke spodnímu dílu krabičky. V místech, kde je displej se pro přišroubování použijí sloupky délky 15mm - díra/díra.

Přes zbylé 2 díry se deska SQM-BAS přišroubuje obyčejnými maticemi M3.

Deska SQM-DIS se zasune do konektorů a přišroubuje se třemi nebo čtyřmi šrouby M3x10 s válcovou hlavou.
Když je použitý modul kompasu, šroub se pod něj nedává, protože by mohl ovlivňovat měření magnetického pole.

Přepážka ve spodní části krabičky slouží k oddělení 9V baterie.
Vedle baterie je uložen GPS modul NEO-6M.
Baterie a GPS modul jsou pak proti pohybu zajištěny ještě kouskem nějakého pěnového materiálu. Tento materiál slouží zároveň jako izolace mezi kovovým pouzdrem baterie a součástkami na modulu NEO-6M

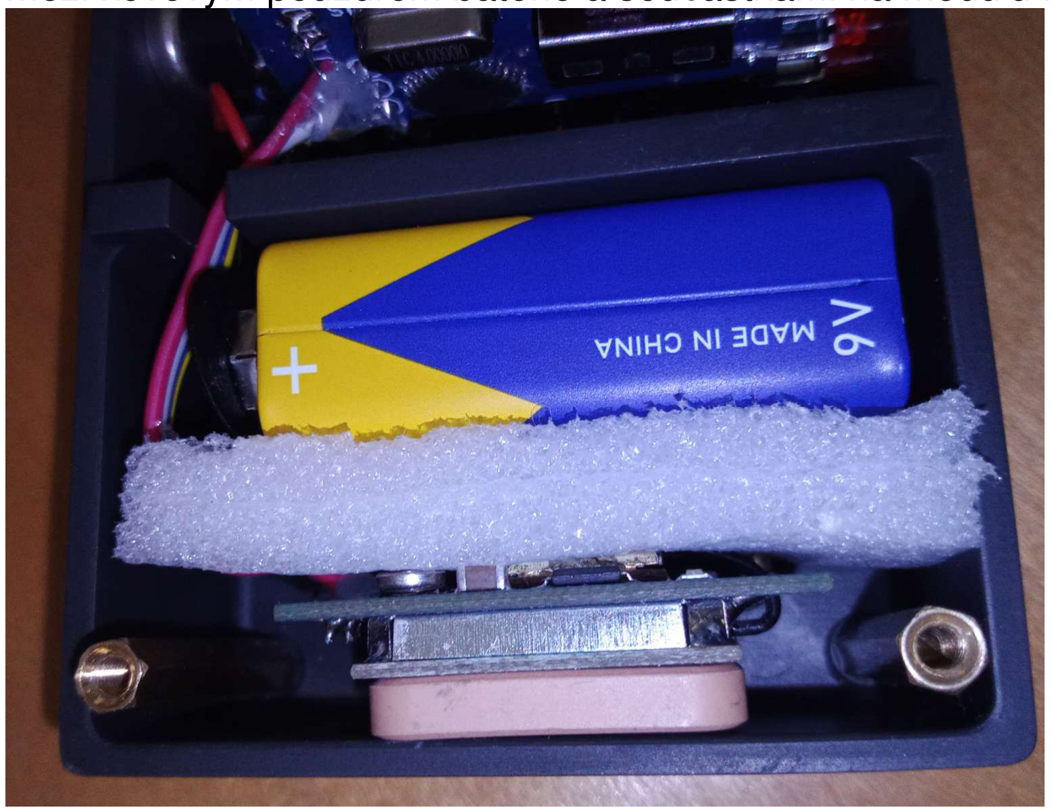
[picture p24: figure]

## Modul náklonoměru s kompasem LSM303DLHC

Měření magnetického pole je ovlivňováno kovovými objekty uvnitř krabičky (9V baterie, piezo pískák....).
Modul s čidlem je proto nutné umístit co nejdál od těchto předmětů.

Jako nejvýhodnější umístění se zdá být nalepení modulu přímo na obvod TM1637 na displejové desce. Zarovnání desky před nalepením podle hrany obvodu zlepšuje přesnost měření náklonu.
Šroub pro připevnění desky displeje, který by se nacházel pod modulem, v tomto případě raději nepoužívejte, protože by mohl ovlivňovat měření.

Připojení je provedeno pomocí plochého 4-žilového kablíku.

Modul LSM303 je nalepený na obvodu TM1637
Důležité upozornění:

Program je upraven pro konkrétní typ čipu: LSM303DLHC
Ostatní obvody LSM303... mohou mít jinak uspořádané registry, nebo se jim nastavuje jiná citlivost.
Případné úpravy pro jiný typ čidel je možné provést v souboru "kompas.ino" v následujících podprogramech:
naklon_setup()
kompas_setup()
nacti_3D_zrychleni()
nacti_3D_magnet()

Kalibrace náklonoměru:
Náklonoměr se kalibruje přes sériovou linku příkazem #Nk .

Po zadání příkazu #Nk se spustí průvodce, který má ale jen 2 kroky:
1) položit krabičku horizontálně a odeslat libovolný znak do sériové linky:
Poloz SQM horizontalne
>>
2) položit krabičku vertikálně a odeslat libovolný znak do sériové linky:
Postav SQM svisle
>>

Hodnoty zrychlení jsou po kalibraci uloženy do EEPROM na adresy 612 až 623 odkud jsou při každém zapnutí obnoveny.
Adresy jsou nadefinovány v programu na řádkách:
#define eeaddr_naklon_horiz | 612UL

#define eeaddr_naklon_vert | 618UL

Náklonoměr je možné kalibrovat i přes menu. Popsáno v kapitole "Menu - Úhel"
v dokumentu "sqm_obsluha.doc".

Kalibrace kompasu:
Kalibraci kompasu je také možné spustit dvěma způsoby:
1) přes sériovou linku příkazem #Mk
2) přes menu pomocí tlačítek na krabičce

Po zadání příkazu #Mk se začne měřit síla magnetického pole ve všech třech osách magnetometru. Zároveň se zaznamenávají minimální a maximální hodnoty magnetické síly v každé ose (extrémy).
Během této operace je nutné s krabičkou otáčet ve všech směrech (podobně, jako se kalibruje kompas v mobilním telefonu).

Pokud se při měření po dobu 10 sekund žádný extrém neobjeví, dojde k automatickému ukončení kalibrace a zápisu zjištěných extrémů do EEPROM.
Při každém zjištění nového extrému se odpočet nastavuje zpátky na 10 sekund.

Ve výpisu se zobrazují extrémy ve všech 3 osách a 10-sekundový odpočet (řádky s hvězdičkou).
Pořadí vypsaných hodnot je: minimum os x, y, z, maximum os x, y, z. Příklad výpisu do sériové linky:

231 ; -1276 ; -683 ; 957 ; -442 ; -183
231 ; -1276 ; -683 ; 1099 ; -442 ; -183 231 ; -1276 ; -683 ; 1099 ; -208 ; -183 231 ; -1276 ; -683 ; 1099 ; -173 ; -15 231 ; -1276 ; -683 ; 1099 ; -128 ; -15 114 ; -1276 ; -683 ; 1099 ; -128 ; -15 100 ; -1276 ; -683 ; 1099 ; -128 ; -15 100 ; -1276 ; -696 ; 1099 ; -128 ; -15 100 ; -1276 ; -698 ; 1099 ; -128 ; -15 *9
*8
*7
100 ; -1276 ; -724 ; 1099 ; -128 ; -15 *10
*9
*8
*7
52 ; -1276 ; -724 ; 1099 ; -128 ; -15 24 ; -1276 ; -724 ; 1099 ; -128 ; -15 *10
*9
*8
*7
*6

Účelem je najít polohu pro co největší rozdíly v každé ose. Čím větší rozdíly se naleznou, tím je následný výpočet azimutu přesnější.

Druhou možností provedení kalibrace kompasu je vstup do menu (dlouhý stisk tlačítka [OK]), nalistovaní položky kompas ("CoMPA"), Potvrzení položky dlouhým stiskem [OK].
Na displeji se začne zobrazovat azimut spočítaný ze starých kalibračních hodnot. Při tomto zobrazení se stiskne a na několik sekund přidrží tlačítko [nahoru]. Aby nedošlo k náhodnému nechtěnému spuštění kalibrace, zobrazují se před spuštěním výstražné pomlčky na displeji. Na displeji problikne nápis "C-CAL" (kompas - kalibrace).

Pak se začne zobrazovat 10-sekundový odpočet.
Při tomto odpočtu je nutné opět otáčet krabičkou ve všech směrech a hledat extrémy magnetického pole ve všech osách.
Když extrém není nalezen, probíhá odpočet. Při nalezení extrému se odpočet vrací zpátky na 10 sekund.

Po doběhnutí odpočtu do 0 se vyhodnotí, jestli jsou zjištěné extrémy dostatečné pro kvalitní výpočet azimutu.
Pokud ne, zahlásí SQM chybu "Err-C" (chyba kompasu) a nastaví se defaultní kalibrační hodnoty. V tom případě se na kompas nedá spolehnout.

## Expanzní deska s více čidly světla

NEOVĚŘENO

Pevně nainstalované SQM by mělo být připraveno pro obsluhu až 7 různě nasměrovaných čidel světla TSL2591.

Tato čidla jsou připojena přes expander MCP23017 k I²C sběrnici.

Protože u čidel světla není možné měnit adresu, zkusil jsem komunikační piny (SDA a SCL) všech čidel paralelně spojit. Napájení každého čidla je ale řešeno přes I²C expander MCP23017.

Pro vypnutí všech čidel se všechny piny expanderu
(PORT_A i PORT_B) přepnou na vstup bez vnitřních Pull-Up odporů. Žádné z čidel tedy nemá napájení.

Pro zapnutí jednoho konkrétního čidla se jeden pin z PORT_A nastaví na výstup a přepne se do LOW. Stejný pin, ale na PORT_B se také přepne na výstup a nastaví se do HIGH.
Jedno z čidel tím získá napájení a začne komunikovat.

Odběr čidla světla je tak malý, že to výstupy MCP23017 utáhnou.

Testování funkce proběhlo jen na 3 čidlech na nepájivém poli. Předpokládám ale, že by neměl být problém s připojením více čidel.

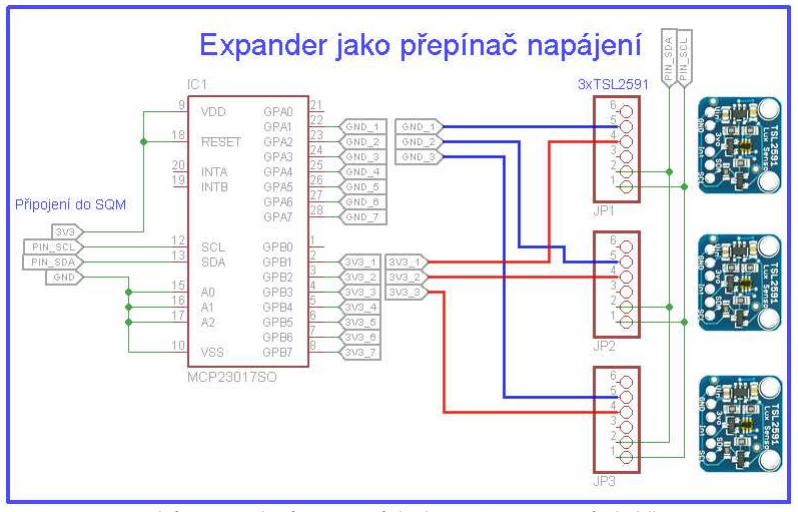
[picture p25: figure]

schéma zapojení expanzní desky se 3 naznačenými čidly

Záměrně jsem piny GPA0 a GPB0 nepoužil, takže index čidla světla odpovídá číslování pinů (například čidlo s indexem 4 je napájeno z pinů GPA4 a GPB4).

Při použití expanzní desky s více čidly světla není možné použít čidlo světla na desce SQM-BAS. Takové čidlo by bylo trvale napájené a pak by se na I²C sběrnici nacházely dvě čidla se stejnou adresou, což je zakázané.

Na nastavení počtu čidel se používá příkaz "@X n", kde n je počet čidel od 1 do 7. Při pokusu o nastavení počtu čidel na 0, nebo při odeslání příkazu "@X" bez parametru, se automaticky vloží 1 čidlo.
Detailnější popis v návodu pro obsluhu (soubor "sqm_obsluha.doc", kapitola "Popis komunikace přes USB").

Pro přepínání čidel na expanzní desce se používají příkazy "e", nebo "@E".
Detaily opět v návodu pro obsluhu (soubor "sqm_obsluha.doc", kapitola "Popis komunikace přes USB").

Při použití pouze jednoho čidla se vypínají expanzní funkce a předpokládá se, že se jedná o jedno čidlo na základní desce SQM-BAS.

## Popis elektroniky

O napájení se stará blok se Step-Down měničem napětí AP1501.
Na vstupu je tento měnič chráněn transilem proti překročení napětí 40V. Na výstupu dodává napětí 3,3V, které slouží jako základní napětí pro celé SQM.
Po připojení USB kabelu se na pin SD (ShutDown) tohoto měniče přivede napětí, které měnič vypne. V takovém případě je pak hlavní napájecí napětí 3,3V vytvářeno pomocí stabilizátoru přímo na procesorové desce BlackPill.

Měření stavu baterie je řešeno přes napěťový dělič, který je tvořený odpory R7 a R8. Podle úrovně napětí na tomto děliči se signalizuje stav baterie.
Protože je ale měření napětí na analogových vstupech závislé na napájecím napětí, bylo nutné do systému přidat ještě referenční napětí. Referenční napětí se získává pomocí Zenerovy diody DZ1 a odporu R9. V okamžiku, kdy je napětí baterie tak malé, že už měnič není schopný dodávat 3,3V, dojde k tomu, že procesor začne toto referenční napětí vyhodnocovat vůči napájení tak, jakoby se zvyšovalo.
V tom okamžiku je to signál pro program, že má nezávisle na napětí na děliči zahlásit velice špatný stav baterie.

Dále bylo nutné zajistit, aby při připojení USB kabelu byl stav baterie hlášen jako "Velmi dobrý". To jsem nakonec vyřešil tak, že se část USB napětí přenese na výstup děliče R7/R8 a tím bez problémů "přebije" napětí na výstupu vypnutého měniče.

Při výrobě vzniknul problém s tím, že se napájecí napětí pro procesor (3,3V) dostávalo přes nějaké vnitřní obvody v procesoru až na USB konektor, to způsobovalo vypínání měniče. Diody D4, D5 a D1 byly proto použity, aby tomuto zpětnému napájení zabránily. Signál "VBUS-FUSE" je tedy jednosměrně oddělený a žádné napětí z procesoru se na něj už dostat nemůže.

Vnitřní hodiny vyžadují zvláštní zdroj napájení. V případě bateriově napájené verze SQM toto napájení zajišťuje knoflíková baterie CR2032. v tom případě se neosazují R11, D6 a D7.
Pokud se ale jedná o trvale napájenou variantu SQM, je plošný spoj připraven na osazení superkapacitoru, který baterii nahrazuje.
V tom případě se R11, D6 a D7 osadí.
Superkapacitor je udržovaný v nabitém stavu z napájecího napětí přes D6 a R11. Když dojde k výpadku napájení, začne dodávat napětí pro hodiny přes diodu D7.

Základ celého zařízení tvoří procesor STM32F411CEU, který je součástí desky BlackPill. Alternativně je možné použít i desku s procesorem STM32F401CEU. V programu se používají jen funkce, které zvládají oba procesory.

Jako čidlo světla je použitý obvod TSL2591. Obvod je osazený na samostatné destičce, která se kupuje jako funkční celek.
S procesorem komunikuje přes I²C.

Jako nepovinné čidlo teploty, vlhkosti a tlaku je použitý obvod BME280. I ten je dodáván na samostatné destičce a komunikuje s procesorem přes I²C.

Záznamy se ukládají do I²C EEPROM s kapacitou 128kB.

Pokud je zasunutá mikro SD karta, ukládají se na ní data v čitelném textovém formátu (CSV soubor).
Držák karty má vyvedený pin pro testování zasunuté karty. Když není karta při zapnutí napájení zasunutá, zobrazí se na displeji varování.

USB komunikaci zajišťuje převodník CH340G v katalogovém zapojení. Na TTL straně jsou využity jsou jen piny Tx a Rx. Ostatní řídící signály nejsou použity.

Případnou komunikaci RS485 zajišťuje obvod MAX3485 (3V úroveň signálů).
I tento převodník je v katalogovém zapojení. Doplněny byly pouze ochranné transily na vstupech. Osazením odporu R3 (100R) je možné zakončit sběrnici. Společně s ochrannými odpory R1 a R2 je pak výsledná hodnota zakončovacího odporu 120R.

## Když něco nebude fungovat:

1) Na desce SQM-BAS není napájení 3,3V:
- Zkontrolovat zapnutí hlavního vypínače.
- Zkontrolovat správně osazenou diodu D8.
- Zkontrolovat připájení obvodu AP1501.
- Zkontrolovat zkrat na napájení na desce.
- Pro spuštění zdroje musí být noha SD na AP1501 přizemněna přes R13.
2) Nefunguje komunikace USB (s propojenými piny PA9 a PA10):
- Je vidět nový sériový port v PC? Když ne, zkusit přeinstalovat ovladače.
- Zkontrolovat osazení diody D5.
- Nemá krystal Q1 nějaký zkrat?
3) Nefunguje RS485
(s osazenou a naprogramovanou procesorovou deskou):
- Běží program v normálním režimu?
(například při spuštěných stopkách je komunikace vypnutá)
- Zkontrolovat osazení R1 a R2.
4) Na displeji nic nesvítí:
- Nemá obvod TM1632 nějaký zkrat mezi nohama?
- Jsou sedmisegmentovky opravdu se společnou ANODOU?
- Je v pořádku napájení desky SQM-DIS?
- Není deska zasunutá o pin mimo?
- Fungují alespoň tlačítka?
5) Defaultní parametry je možné do EEPROM zapsat i bez připojení k sériovému terminálu. Stačí při zapnutí napájení držet alespoň 5 sekund společně stisknutá všechna 3 tlačítka ([nahoru], [dolu] a [OK]).
6) Do desky GPS nejde nahrát program:
- Zkontrolovat připojení ISP programátoru, nastavení Arduino IDE.
- Byla provedena změna v konfiguračním souboru boards.txt? Možná bude nutné Arduino IDE restartovat.

7) Po nahrání programu nefunguje servisní reset desky GPS:
- když LED vůbec neblikají, asi neběží procesor
odpojit GPS modul a zkontrolovat napájení procesoru a jeho krystal.
8) V desce GPS nebliká první LED (servisní reset ale proběhnul):
- Připojit samotný GPS modul NEO-6M k převodníku USB/TTL a nechat v terminálu vypisovat data z modulu
Měly by se střídat věty GxGGA a GxRMC.
- Problém může být i ve špatně nastavené rychlosti krystalu (úpravy v souboru "boards.txt").

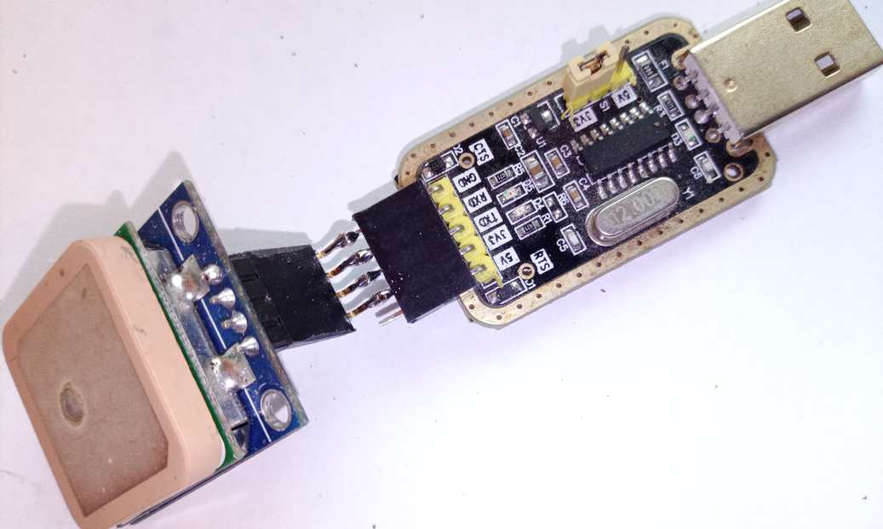
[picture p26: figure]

Podle stavu zafixování družic se mohou v terminálu zobrazovat i informace o čase a souřadnicích.

9) Na desce GPS sice bliká první LED, ale ostatní stále svítí.
- je to problém s příjmem GPS signálu.
- první zafixování po delší době nečinnosti trvá obvykle déle.
- většinou pomáhá vynést přístroj pod jasnou oblohu
- když se zafixování nepodaří ani po 15 minutách, zkontrolovat anténu, nebo zkusit připojit
nějakou výkonnější
- problém může být i v samotném modulu NEO-6M.
V tom případě ho připojit jako v předchozím bodě 7) přes USB/TTL převodník přímo do počítače
a zkusit ho samostatně. Po nějaké době by se měly v přijímaných větách objevit informace o čase a souřadnicích.
10) Při propojení servisní propojky na GPS desce by měly při zapnutí napájení desky GPS LED 5x bliknout frekvencí 1Hz - nezávisle na všem ostatním. Pokud blikají rychleji nebo pomaleji, je špatně nastavená frekvence krystalu.

## Změny v návodu

19.5.2026
- Další opravy překlepů, aktualizace verzí programu.

21.3.2026
- Opravy překlepů, aktualizace verzí programu.
- Doplnění screenu s instalací rozšíření pro STM32F4xx na novém Arduino IDE.

6.9.2025
- Oprava v testu referenčního napětí 1,8V na straně 23.
Původní text "... alespoň 3,5V ..." nahrazen za "... alespoň 4V ...". (Při 3,5V ještě nemusí DC-DC převodník správně fungovat.)
- Alternativní náhrada D3 drátem na desce BlackPill.
- Doplnění kopírování složky "HELP" na SD kartu.
- Vymazání informací o zakončovací propojce pro komunikaci RS485 (propojka už tam není od verze plošňáku SQM-BAS-4).

20.1.2025
- upřesnění označení diody D3 (někde značená jako D1),
které se řeže noha pro správné měření napětí zálohovací baterie.
- nevýznamné úpravy textů

5.1.2025
- změna adresy konfigurátoru
- opravy překlepů

18.12.2024
- První zveřejněná verze návodu pro výrobu

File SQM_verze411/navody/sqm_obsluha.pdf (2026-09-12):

# Měřič kvality oblohy

# (amatérské SQM)

http://sqm.AstroMiK.org


## Návod k obsluze

SW: | STM32 | 2026-09-12 (STM32F4x1)
| ATmega328 | 2026-09-12..INT

12.9.2026

Strana 1/172

## OBSAH

Výpisy souborů z SD karty do sériové linky | 136
Vnitřní hodiny (RTC) | 140
Komunikace s "Unihedron Device Manager" | 141
Přídavná GPS deska | 143
Kalibrace jasu a teploty | 145
Chybová a varovná hlášení na displeji | 147
HW testovací funkce | 149
a Sken I²C | 150
b Test A/D | 151
c Test hlavní EEPROM 128k | 151
d Test EEPROM pro režim "30s" | 152
e Test pískáku | 153
f Test BME280 | 153
g Test čidla jasu TSL2591 | 154
h Test displeje | 154
i | Test digitálních vstupů | 155
j | Test tlačítek | 156
k Test LED | 157
l Test SD karty | 157
m Test komunikační linky RS485 | 158
n Test GPS | 160
o Test kompasu a náklonoměru | 160
p Odposlech GPS | 161
r Test vnitřního RTC v STM32 | 163
s Test nastavení hodin v STM32 | 163
t Boční výstupní pin na LOW | 164
T Boční výstupní pin na HIGH | 164
u Test času v DS3231 | 165
U Test časovaného alarmu | 166
- Zrušení automatického výpisu menu | 166
x Ukončení testovacího režimu | 167
Rozšíření funkcí o kalibraci | 168
Změny v návodu | 171

## Úvod

Levnější a více vybavená náhrada za SQM od Unihedronu.

Připraveno pro variantu ručního přenosného přístroje s displejem, tlačítky a možností osazení GPS.
Druhá varianta je pevně nainstalovaný přístroj ovládaný komunikací RS485 (modbus). V této variantě je displej a GPS zbytečná.

Základem je procesorová deska BlackPill s procesorem STM32F411CEU (128kB). Program funguje i s deskou BlackPill
s procesorem STM32F401CEU.

Pro měření světla je použitý modul s čidlem TSL2591.
5-místný sedmisegmentový displej je řízený pomocí ovladače TM1637.

V předchozích verzích (do 5/2023) bylo možné připojit externí GPS. Ukázalo se, že přídavná krabička je v terénu nešikovná, a proto byla GPS nově zabudovaná dovnitř. Kvůli tomu bylo ale nutné o 2 cm prodloužit krabičku.

Seznam funkcí:

- Záznam naměřených hodnot do vnitřní EEPROM (128k ×8b). Podle počtu volitelných měřených dat je do ní možné zaznamenat asi 3500 až 16000 záznamů
(pak se začne vnitřní EEPROM přepisovat od začátku).
- Záznam je možné provádět i na mikro SD kartu v textovém formátu (*.csv). Každou noc do jednoho souboru.
- Volitelně je možné zaznamenávat i teplotu, vlhkost a tlak (modul BME280)
- Data je možné stáhnout přes USB nebo dálkovou komunikací RS485.
- Využívají se vnitřní hodiny reálného času přímo v procesoru STM32F411CEU.
- Při použití rozšiřující desky GPS se mohou zaznamenávat
i zeměpisné souřadnice a nadmořská výška.
- Rozšiřující GPS deska průběžně seřizuje vnitřní hodiny podle signálu GPS (pokud je čas v signálu dostupný).
- Spuštění měření se provádí buď jedním ze 3 tlačítek, přes USB, přes dálkovou komunikaci RS485, nebo se může měření spouštět automaticky po zadaném počtu minut.
- Napájení je v podstatě libovolné mezi 5V až 30V. Typicky se počítá s 9V baterií, nebo s napájením přes USB. Na desce jsou připraveny i kontakty pro napájení přes souosý napájecí DC konektor (JACK). Odběr při 9V, zhasnutém displeji a bez GPS je 23mA.
Při zhasnutém displeji a se zapnutým GPS modulem je odběr 56mA. SQM s plně rozsvíceným displejem bez GPS odebírá 48mA.
Při 24V je odběr zhruba poloviční. Při 5V zhruba dvojnásobný.
V příloze je tabulka odběrů při různých napájecích napětích.
Pro dálkovou komunikaci RS485 jsou na desce připraveny svorky pro napájení 24V po komunikačním kabelu.

- Přímo v terénu je možné listovat ve starších záznamech
(až 99 záznamů zpátky). Zobrazování na displeji je ale velmi zredukované.
- V terénu je také možné přes menu měnit nastavení datumu, času a časové zóny (SEČ/SELČ).
- Přes menu se dá nastavit počet vzorků světla k průměrování (1 až 20).
- Také je možné zvolit automatické spouštění měření (v rozsahu každou minutu až každých 255 minut).
- Kalibrace měření světla se provádí (až) v 15 bodech.
K tomu je třeba nasnímat nezkorigovanou hodnotu z čidla (v menu je to položka "CALIB") a porovnat ji s hodnotou z nějakého přesného kalibrovaného SQM.
Obě hodnoty (změřená a správná) se pak uloží pomocí USB sériové linky do vnitřní kalibrační tabulky.
- Kalibrace teplotního čidla probíhá podobně (kalibrační tabulka pro teplotu má ale pouze 7 bodů).
- Při použití rozšiřující GPS desky je možné na displeji zobrazit i zeměpisné souřadnice
(dlouhé číslo se postupně odroluje přes celý 5-místný displej). Souřadnice se mohou ukládat i do paměti a případně i na SD kartu.
- Když není GPS modul zapnutý, je možné přes menu zvolit jedno z 5 předdefinovaných pozorovacích stanovišť. Název zvoleného stanoviště se pak zapisuje k záznamu o měření.
- V době mezi měřeními blikají na jinak zhasnutém displeji desetinné tečky. Počet teček signalizuje stav baterie (víc teček = horší baterie). Při každém poklesu napětí na nižší stupeň proběhne zvuková výstražná signalizace. Přes menu lze měřit i skutečné napětí zdroje.

- SQM je možné použít i jako stopky s rozlišením na tisíciny sekundy. Protože je ale tato funkce výkonově náročná, jsou ostatní měřící a komunikační funkce po dobu běhu stopek zablokovány.
Přesnost záleží na použitém krystalu u procesoru a na okolní teplotě. Vzhledem k tomu, že spouštění a zastavování probíhá ručně pomocí tlačítek, myslím, že není nutné přesnost nějak zvlášť řešit.
- Do paměti je možné bočním tlačítkem uložit rychlou časovou značku. A to i v případě, že je SQM vypnuté (tlačítko přemostí hlavní vypínač).
- Při použití přídavného modulu náklonoměru (LSM303DLHC) je možné k záznamům přidávat i úhel naklonění. Přístroj je pak možné použít i jako dvouosou vodováhu k ustavení dalekohledu.
- Použitím modulu s čipem LSM303DLHC se zapne i funkce měření směru namíření krabičky (azimut).
- Přístroj provádí i základní astronomické výpočty – elevace Slunce a Měsíce a stav osvětlení Měsíce. Při použití kompasu LSM303 umí přepočítávat rovníkové souřadnice (Ra / Dec) na místní azimut a elevaci.
- K novým funkcím patří i odpočet do stanoveného času (budík / alarm). Při osazeném obvodu DS3231 je možné probouzet přístroj v nastavený čas i při vypnutém hlavním vypínači.
- Přístroj dokáže počítat některé informace o planetách (Ra / Dec / vzdálenost / magnituda / východ / západ...).
Také je možné pro aktuální den zjišťovat čas začátku a konce astronomické noci a volitelného soumraku.
- Při použití GPS je možné zaznamenávat trasu do GPX souboru ve 20-sekundových intervalech a pak ji vynést do mapy. Tato funkce byla plánována pro záznam cesty na pozorovací stanoviště, nebo pro dlouhodobější průměrování souřadnic pozorovacího stanoviště.
- K dispozici je databáze s 662 DSO objekty, pro které se počítá
poloha a viditelnost.
- Poslední funkcí je nouzová červená lampička (na displeji se rozsvítí zvolený počet sedmisegmentovek a pomocí jednoho tlačítka je možné je zhasínat a znovu rozsvěcovat).

## Základní zobrazení a ovládání

Toto SQM je navrženo tak, aby co nejméně rušilo svým svitem. V základním stavu jsou tedy úplně zhasnuté všechny zobrazovací jednotky, kromě desetinné tečky, která svým blikáním signalizuje zapnutý stav.
Tečky na displeji v tomto základním stavu mají i jiné funkce.
Pokud zprava bliká více teček zároveň, je to upozornění na horšící se stav baterie (1 tečka - baterie v pořádku, 2 tečky - baterie slábne ..... 5 teček - baterie těsně před smrtí).

Pokud bliká první LED zleva je to signalizace právě probíhajícího automatického měření.

Blikání druhé LED zleva signalizuje, že došlo ke spuštění měření pomocí příkazu přes sériovou linku (USB nebo RS485).

Krátkým stiskem jednoho ze tří tlačítek se spustí měření jasu.
Měření probíhá v několika fázích, které jsou signalizovány různě vysokým pípáním a problikáváním čísla na displeji.

V první fázi probíhá až 5 měření, při kterých se testuje stabilní hodnota. Každý vzorek je signalizován hlubokým pípnutím a na displeji problikává odpočet po desítkách ("-60-", "-50-", "-40-"...).

Tato měření se ještě nepoužívají k průměrování. Když je rozdíl v hodnotách dvou po sobě jdoucích měření menší než nastavená hodnota, přejde se okamžitě do druhé fáze.
Pokud ani po 5 testovacích měřeních nebylo dosaženo stabilní úrovně, také se přejde do druhé fáze, ale do záznamu přibyde značka, že měření bylo nestabilní.

Ve druhé fázi se provede několik měření jasu, které se průměrují. Počet měření je nastavitelný v rozsahu 1 až 20.
Větší počet měření vrací stabilnější hodnotu, ale měření také trvá déle (1 vzorek se zpracuje asi za sekundu). Při nastaveném počtu 20 průměrovaných hodnot může celé měření trvat i přes půl minuty. Druhá fáze měření je signalizována vyšším pípáním a na displeji problikává odpočet kolik vzorků ještě schází.

V poslední fázi se už jen zobrazí zprůměrovaná hodnota jasu na displeji. Zároveň se pípne buď nejvyšším tónem (když je měření stabilní), nebo se výstražně zavrčí (když před měřením nedošlo ke stabilizaci hodnot, nebo když během měření jas kolísal).
Při tom dojde k uložení hodnoty do vnitřní paměti a případně i na SD kartu.

Hodnota zůstane na displeji zobrazena několik sekund. Pak displej přejde zpátky do základního zhasnutého stavu (blikají jen desetinné tečky jako test stavu baterie, nebo signalizace automatického měření).

Pomocí bočního tlačítka je možné kdykoliv okamžitě zaznamenat aktuální datum a čas do paměti. To se hodí například v případě, že je třeba rychle zaznamenat čas nějakého úkazu
(meteor, záblesk družice, ...)
Tlačítko se stará i o zapnutí napájení do SQM, takže je možné provést rychlý záznam i když je SQM vypnuté.

Na displeji se na chvíli zobrazí pořadové číslo záznamu a SQM pípne. Číslování časových záznamů se nuluje vždycky v poledne.
(Pro celou noc platí jedna číselná řada.)

Aby se provedl záznam (do paměti a případně i na kartu), musí se tlačítko držet tak dlouho, než se ozve pípnutí (několik desetin sekundy). Když se tlačítko stiskne jen krátce, může dojít k odpojení napájení ještě před dokončením záznamu a záznam tak může být neúplný.

Ve verzi z 2021-09-05 byla doplněna funkce, která umožňuje toto tlačítko dočasně zablokovat (například při převážení v batohu, kde by hrozilo jeho nechtěné stisknutí).
Blokování se provádí držením tlačítka [dolu] při vypnutém napájení a následným zapnutím napájení. Na displeji se objeví nápis "-Loc-".

Od tohoto okamžiku se při stisku tlačítka časová značka nezaznamená. Odblokování tlačítka se provádí automaticky při dalším normálním zapnutí napájení.

Ve verzi 2021-11-12 byla doplněna funkce, kdy se po dlouhém držení bočního tlačítka (po 3 sek.) zobrazí na displeji ještě aktuální čas "HH-MM".

Dlouhý stisk tlačítka [OK] umožní vstup do menu.

## Menu

Do menu se vstoupí dlouhým stiskem tlačítka [OK].

Listování mezi položkami a případná změna hodnot se provádí tlačítky [nahoru] a [dolu].
Od verze 2023-03-11 byla zavedena trojrychlostní změna hodnot
v závislosti na délce stisku tlačítka [nahoru] nebo [dolu].
- Krátký stisk tlačítka listuje v menu nebo mění hodnotu po jednotkách.
- Delší stisk tlačítka mění hodnotu nebo listuje pomalu automaticky.
- Stisk delší než 5 sekund mění hodnotu automaticky a rychle.

Tlačítko [OK] má v menu dvě funkce:

Krátký stisk obvykle znamená opuštění položky bez uložení, nebo návrat v menu o úroveň výše. Případně návrat z menu do základního vyčkávacího režimu (zhasnutý displej, blikající tečky).

Dlouhý stisk je pro vstup do zvolené položky (vstup do hlubší úrovně menu), nebo pro potvrzení a uložení nastavené hodnoty.

V programu od verze 2022-12-17 přibyla funkce, která umožňuje nepoužívané položky v menu vypnout.

Tato funkce se spouští "speciálním hmatem" při zapnutí přístroje. Při vypnutém přístroji, který nemá zablokované boční tlačítko se:
- stiskne a drží tlačítko [nahoru]
- po něm se stiskne a drží boční tlačítko
- na displeji se objeví nápis "MEnu".
- se stále drženými oběma tlačítky se zapne napájení
- pak se mohou obě tlačítka uvolnit a na displeji se zobrazí první položka z menu.

Pomocí tlačítek [nahoru] a [dolu] se mezi položkami listuje.
Krátký stisk tlačítka [OK] přepíná vybranou položku jako viditelnou nebo zablokovanou (viditelná má vysoký jas, zablokovaná má nízký jas). Dlouhý stisk tlačítka [OK] ukončí nastavení a vrátí přístroj do normálního režimu.
V menu se pak položky, které byly nastaveny jako zablokované, neobjeví.

Výběr viditelných a zablokovaných položek se ukládá do vnitřní paměti, takže i při dalším zapnutí zůstane menu v nastaveném stavu.

## Menu - LIST

Funkce pro výpis uložených hodnot ve vnitřní paměti.
Po vstupu do této položky se pomocí tlačítek [nahoru] / [dolu] zvolí, jak starý záznam se má zobrazit.
Číslo 0 je nejnovější (poslední) uložený záznam, číslo -1 je předposlední záznam a tak dále.
Maximální možná zadaná hodnota je -99.

Po potvrzení čísla záznamu dlouhým stiskem tlačítka [OK] se na displeji vypíše záznam ve zjednodušeném formátu.
Formát výpisu závisí na tom, o jaký typ záznamu se jedná.
(Výpis záznamu světla bude jiný, než záznam časové značky, nebo zaznamenaný mezičas ve funkci stopky.)

Výpis zaznamenaného jasu bude vypadat například takto:
d 13.04. 19-22 9.567
První znak udává, jak byl záznam pořízen (d = tlačítko [dolu]). Následuje datum bez roku (13. dubna).
Pak je čas (hodiny a minuty 19:22)
A jako poslední je zaznamenaná hodnota jasu
(9,576 mag/arcsec²
)

Tento řetězec postupně proběhne přes celý 5-místný displej.

Tlačítkem [nahoru] a [dolu] je možné rychle přejít na následující, nebo předchozí záznam.
Tímto způsobem je možné vypsat i záznamy starší než -99.
V případě, že je zobrazen nejnovější záznam, není možné přepnout tlačítkem [nahoru] na ještě novější (protože ještě neexistuje). Proto se jen výstražně pípne a znovu se zarotuje nejnovější záznam.

Dlouhý stisk tlačítka [OK] znovu zarotuje právě zobrazený záznam.

Krátkým stiskem [OK] se vrátí zobrazení o úroveň výše (na volbu záznamu 0 až -99)

V případě záznamu jasu mohou být na prvním místě následující znaky: d = tlačítko [dolu] (Down)
u = tlačítko [nahoru] (Up)
o = tlačítko [OK]
c = jedno z 10 kalibračních měření světla C = průměr všech 10 kalibračních vzorků A = spuštěno automatem
M= spuštěno příkazem přes sériovou linku

Pokud je v paměti uložen záznam časové značky, vypadá výpis následovně:

### tiME 001 13.04. 20-33-58

001 je pořadové číslo značky v rámci jednoho dne (resp. noci)
13.04. je datum (den a měsíc bez roku)
20-33-58 je čas (20 hod. 33 min. 58 sek.)

Pro záznamy pořízené funkcí stopky je to trochu složitější:

Záznam spuštění stopek vypadá takto:

### StArt 13.04. 20-39

Čísla udávají datum (den a měsíc) a čas (hodina a minuta) spuštění stopek.

Mezičas je zobrazen takto:

### LAP 01 00-00-07.956

První číslo je pořadové číslo mezičasu. Nuluje se při nulování stopek. Pak následuje zaznamenaný čas (hodiny, minuty, sekundy a tisíciny sekund od spuštění stopek).

Zastavení stopek je podobné jako mezičas:

### StoP 00-00-13.572

Nezobrazuje se zde pořadové číslo, ale pouze čas zastavení stopek.

Pokud nedojde k vynulování, ale stopky se znovu spustí, zobrazí se následující záznam:

### Cont 13.04. 20-40

Význam čísel je stejný jako při startu, akorát je zdůrazněno, že se jedná o pokračování měření času bez vynulování stopek.

Při nulování stopek se žádný záznam do vnitřní paměti neprovádí.

Detailní výpisy záznamů je možné získat z SD karty, nebo výpisem do sériové linky.

## Menu - Auto

Pomocí této položky je možné nastavit automatické měření. Tlačítky [nahoru] / [dolu] se zvolí, po kolika minutách (1 až 255) se má automaticky spouštět měření.
Při zadání čísla 0 se automatické spouštění zruší.

Číslo se potvrdí a uloží dlouhým stiskem [OK] (na displeji problikne nápis SAVE), nebo se krátkým stiskem [OK] nastavení opustí bez uložení změn.

První automatické měření se provede okamžitě po uložení nenulové hodnoty. Další měření budou následovat v nastavených intervalech.

Pokud je nastavené automatické měření, NEPROVÁDÍ se první měření hned po zapnutí napájení. Je to z toho důvodu, aby se dal automat okamžitě po zapnutí napájení zrušit a nemuselo se čekat až měření proběhne.

Poznámka
Když je spuštěná funkce automatického měření a zároveň je použita expanzní deska s více čidly světla, proběhne měření postupně na všech čidlech. Je to jediný případ, kdy se čidla přepínají automaticky.

V ostatních měřeních (spuštění tlačítkem nebo komunikací) se používá vždycky jen jedno aktivní čidlo a přepínání se musí provádět ručně.

## Menu - Časová zóna

Přímo v terénu je možné přepínat časovou zónu LEto / ZiMA.

Ovládání je stejné, jako v předchozím případě:

Tlačítky [nahoru] a [dolu] se přepíná.
Dlouhý stisk [OK] nastavení potvrdí a uloží, nebo krátký stisk [OK] nastavení nezmění a vrátí se do hlavního menu.

Pomocí příkazů odeslaných přes sériovou linku je možné nastavit i jiné časové zóny než SEČ / SELČ (například americký EST / EDT).

Příkazy jsou popsané níže v kapitole o sériové komunikaci přes USB (@Gz nn, @Gl nn a @Gp).

Pokud je v menu "Astro" zapnuta simulace astronomických výpočtů pro zvolené datum a čas, problikává v položkách "datum", "čas" a "zóna" nápis "Si. on" (simulace zapnuta). V tom případě se nastavené časové údaje nezapisují do vnitřního RTC obvodu, ale slouží pouze k určení času astronomických výpočtů v menu "Astro" a "DSO"

## Menu - Kalibrace

Funkce kalibrace slouží k zobrazení hodnot, které se získávají přímo z čidel světla a teploty.

Takto získaná čísla se pak porovnávají s hodnotou, která byla změřena přesným (profesionálním) SQM.

V programu je pak funkce, která čísla získaná přímo z čidel matematicky přepočte na správné (přesné) hodnoty které se mají zobrazit a uložit.

Přesný postup kalibrace je popsaný v kapitole "Kalibrace jasu a teploty".

Při volbě položky menu "Calib" dojde k měření 10 hodnot světla (nezávisle na nastaveném počtu průměrování).
Každé z těchto 10 měření se zaznamenává jako samostatný záznam. Při měření se neprovádí žádné matematické korekce.
Ukládají se hodnoty, které se získávají přímo z čidel.
Na závěr se na displeji zobrazí zprůměrovaná hodnota nekorigovaného světla.

Tlačítky [nahoru] / [dolu] se pak přepíná mezi hodnotou světla a teploty. I hodnoty teplot jsou v tomto případě bez korekcí (přímo z čidla). Teplota je signalizována apostrofem na levé sedmisegmentovce (mělo to vyjadřovat něco jako °).
Při záporné teplotě je znaménko '-' také na levé sedmisegmentovce (Záporná hodnota teploty pak vypadá jako miniaturní horní "L", ale mělo to být "°-")

Stiskem [OK] se provede návrat do hlavního menu.

## Menu - Datum

Nastavení aktuálního datumu je možné i pomocí tlačítek.
Je to pro případ, že by se vybila vnitřní knoflíková baterie pro RTC.

Před nastavením času je nutné mít správně zvolenou časovou zónu (Léto / Zima).

Při vstupu do této položky se objeví postupně 3 parametry, které se pomocí tlačítek [nahoru] a [dolu] nastaví (rok, měsíc a den).

Krátký stisk [OK] ponechá původní hodnotu parametru bez uložení, dlouhý stisk ji uloží.

Dny se volí v rozsahu 1 až 31, měsíce v rozsahu 1 až 12.
Rok se zadává jen jako poslední dvojčíslí. Minimální hodnota je 20 (rok 2020). a maximální 99 (rok 2099)

U každé položky je na displeji zobrazeno písmeno, aby bylo zřejmé, jaký parametr se právě edituje ("d" pro nastavení dne, "M" pro nastavení měsíce a "r" pro nastavení roku)

Program nemá ochranu proti zadání nesmyslného datumu
(například 31. únor).

## Menu - Čas

Stejně jako nastavení datumu je i čas možné nastavit pomocí tlačítek.

Před nastavením času je nutné mít správně zvolenou časovou zónu (léto / zima).

Pak už se jen tlačítky nastaví hodiny a minuty.

Předpokládám, že při nastavení v terénu nebude k dispozici úplně přesný čas, a proto se sekundy nenastavují.
Nastaví se automaticky na 0

A jak už je obvyklé, tlačítka [nahoru] a [dolu] mění hodnoty, dlouhý stisk [OK] nastavenou hodnotu potvrdí a zapíše. Krátký stisk [OK] ponechá hodnotu beze změny.

Při zadávání hodin je na displeji zobrazeno písmeno "H". zadává se ve 24-hodinovém formátu.
Při zadávání minut svítí na displeji písmeno "M" a povolený rozsah je 0 až 59.

V případě použití přídavné GPS desky se datum a čas nastavuje podle GPS signálu (pokud je dostupný).
Podrobně je popsáno v kapitole "Přídavná GPS deska".

## Menu - Teplota

Tato položka slouží k průběžnému zobrazovaní aktuální teploty. Změřená hodnota se nikam nezapisuje. Aktualizace měření probíhá zhruba 1× za sekundu.

Na první segmentovce svítí znak apostrof, který má signalizovat stupeň (°). Na stejné segmentovce může zároveň svítit i znaménko pro zápornou teplotu.

Při vstupu do této položky menu se vždycky zobrazuje teplota, která je zkorigovaná pomocí teplotní kalibrační tabulky.

Pokud by bylo třeba zobrazit neupravenou hodnotu přímo z čidla, provede se přepnutí pomocí současného stisku tlačítek [nahoru] a [dolu]. Na displeji problikne nápis "noCor" (bez korekce).

Přepnutí zpátky na zobrazení korigované hodnoty se provede stejným způsobem - současný stisk tlačítek [nahoru] a [dolu].
Na displeji pak problikne nápis "Corr" (korigovaná hodnota).

Více informací o kalibraci teploty v kapitole "Kalibrace jasu a teploty".

Návrat do menu se provede stiskem tlačítka [OK] (v tomto případě libovolně dlouhým).

## Menu - Vlhkost

Zobrazení aktuální vlhkosti na displeji. Hodnota se nikam neukládá a aktualizace probíhá zhruba 1× za sekundu.

Na displeji je před hodnotou zobrazeno písmeno "V" (přesněji řečeno byla snaha o zobrazení "V", ale vyšlo z toho "U" - na sedmisegmentovce se některé znaky tvoří dost obtížně).

Protože pro měření vlhkosti neexistuje kalibrační korekční tabulka, zobrazuje se na displeji vždycky jen číslo přímo z čidla - bez korekce.

Není tedy možné ani přepínání korigovaných a nekorigovaných dat jako u teplot.

Návrat do menu se provede stejně jako při zobrazení teploty - stiskem tlačítka [OK].

## Menu - Jas

Průběžné zobrazení hodnoty měřeného jasu.
Protože je nutné při měření jasu oblohy zhasínat displej, hodnota na displeji bliká.

Jeden měřící cyklus trvá asi 2 sekundy.
Data se nikam neukládají. Neprovádí se ani žádné průměrování.

Tak jako při průběžném měření teplot, i tady je možné přepínat mezi nezkorigovanými hodnotami přímo z čidla a hodnotami, které prošly matematickou korekcí přes kalibrační tabulku.
(společný stisk tlačítek [nahoru] a [dolu] - bliknutí nápisu "noCor", nebo "Corr").

Stisk [OK] provede návrat do menu.
Vzhledem k delšímu nepřerušitelnému času, který je potřeba pro měření světla (asi 1 sekunda), bude někdy nutné k návratu přidržet tlačítko [OK] trochu déle.

Při stisku tlačítka [nahoru] je možné přepnout na funkci rychlého luxmetru.
Tlačítko se testuje až po dokončení měření plošného jasu a proto se může stát, že bude nutné držet tlačítko delší dobu.
Na displeji problikne nápis "LuHM" (pokus o zobrazení "LuXM" na sedmisegmentovkách)
Výsledkem funkce není úplně přesná hodnota, ale dá se použít alespoň na hrubé porovnání dvou osvětlených míst. Při měření se používá klouzavé průměrování tří hodnot.

Pro částečné zpřesnění je možné tento luxmetr kalibrovat pomocí tří konstant. Pro kalibraci je ale nutné použít nějaký opravdový luxmetr. Kalibrace je popsána v odstavci o sériové komunikaci (funkce #Xa, #Xb, #Xc).

I tady je možné zobrazovat neupravené hodnoty přímo z čidla současným stiskem tlačítek [nahoru] a [dolu] (přepínání "noCor" a "Corr").

Při měření jasu v režimu SQM bez korekce se na SD kartu ukládá logovací soubor "\LOGS\logjas.txt", který obsahuje i neupravené hodnoty registrů z čidla TSL2591. Tento logovací soubor sloužil pro analýzu matematických přepočtů jasu a je možné ho vypsat příkazem @>G.

Příklad výpisu souboru:
LOGS/logjas.txt (pocet radek: 34) -------------
2026/04/25;08:27:02;09522;29141;11604;037 2026/04/25;08:27:12;09546;28879;11607;037 2026/04/25;08:27:18;09564;28390;11408;037 2026/04/25;08:27:22;10457;13376;05651;037 2026/04/25;08:27:25;10737;10912;04777;037 2026/04/25;08:27:28;10727;11008;04819;037 2026/04/25;08:27:32;10725;11039;04835;037 2026/04/25;08:27:35;10722;11078;04855;037 2026/04/25;08:27:39;10720;11112;04874;037 2026/04/25;08:27:42;10742;10931;04805;037

Na začátku řádky je datum a čas v lokální časové zóně. Následuje přepočtená hodnota jasu v mmag/arcsec²
Další je hodnota FULL registru.
Pak následuje INFRA registr.
Na konci řádky je hodnota CONFIG registru, ze které jsou ale zajímavé jen bity 5 a 4, které určují zesílení AGAIN. Ostatní hodnoty se nemění, ATIME je napevno nastaveno na 600ms.


V pozdějších verzích programu byla do této položky menu doplněna i informace o změřené hodnotě v "infra" kanálu čidla osvětlení. Přepnutí na tento typ zobrazení se provede dalším stiskem tlačítka [nahoru] po zobrazení luxmetru. Na displeji problikne nápis "inFrA".

Pak se bude zobrazovat jen surová hodnota z infra registru čidla TSL2591 v rozsahu 0 až 65535. Nic se neprůměruje.

Vzhledem k tomu, že je tato hodnota závislá na nastaveném zesílení (AGAIN), bylo nutné aktuální zesílení také nějak okamžitě signalizovat. Vyřešil jsem počtem blikajících desetinných teček na displeji.
Při nejnižším zesílení (AGAIN=1x) bliká 1 tečka zleva.
Při nejvyšším zesílení (AGAIN=9876x) blikají 4 tečky zleva.

Od verze 2025-11-22 byla doplněna ještě funkce, která změřené MSA převede na Bortleho stupeň.
POZOR: Není to žádný spolehlivý přepočet. Pouze MSA v mag/arcsec² roztřídí do jednoho z devíti stupňů. Skutečný Bortleho stupeň se určuje podle subjektivní viditelnosti některých nebeských objektů (Mléčná dráha, M33, zvířetníkové světlo ...). Dva lidé mohou tedy ve stejnou dobu vyhodnotit stejné pozorovací stanoviště odlišným Bortleho stupněm.

Funkce je defaultně vypnutá. Pokud vezmete na vědomí, že se jedná jen o odhad, můžete si ji zapnout zadáním příkazu "@W483,1" do sériové linky.

Přepnutí na zobrazení Bortleho stupně se pak provede v menu "Jas" stiskem tlačítka [nahoru] po položce "inFra".

Hranice stupňů jsem volil podle doporučení na diskusním fóru:
https://www.astro-forum.cz/viewtopic.php?p=551407#p55140
Změna mezí je možná v programu v části označené jako #doc#20.

## Menu - Hodiny - Minuty

Funkce pro průběžné zobrazení aktuálního času (Hodiny-Minuty)

Při stisku tlačítka [dolu] je možné přepnout na zobrazení času ve stylu Minuty-Sekundy. Na displeji problikne nápis "Mi-SE".

Při stisku tlačítka [nahoru] se vrátí původní styl zobrazení Hodiny-Minuty. Signalizováno nápisem "Ho-Mi".

Návrat do menu - stisk [OK].

Při vstupu do této položky menu se vždycky zobrazí jako první
styl "Ho-Mi".

## Menu - Průměrování

Nastavení počtu vzorků při měření světla, ze kterých se následně vypočítá průměrná hodnota.

Čím větší číslo se zadá, tím bude údaj stabilnější, ale také bude měření déle trvat.

Při zadaném čísle 1 se průměrování neprovádí.
Maximální možný počet vzorků k průměrování je 20.

Vzhledem k tomu, že měření jednoho vzorku může trvat i déle než sekundu, může celé měření při maximálním počtu vzorků k průměrování trvat i přes půl minuty.

## Menu - LED

Jednoduchá nouzová lampička s regulovatelným jasem červeného světla.

Při této funkci je možné na displeji rozsvítit všechny segmenty na jedné až 5 sedmisegmentovkách plným jasem.

Zvyšování a snižování jasu se provádí stiskem tlačítek [nahoru] a [dolu].

Tlačítko [OK] má v tomto případě trochu jinou funkci, než je obvyklé:

Krátký stisk [OK] displej zhasíná nebo rozsvěcuje s přednastaveným počtem svítících sedmisegmentovek.

Dlouhým stiskem [OK] se provádí návrat do menu.

## Menu - Stopky

Speciální režim stopky pro záznam časového intervalu.

Protože je tento režim hodně náročný na výkon procesoru, blokují se při něm ostatní funkce SQM (automatické měření, USB a RS485 komunikace, testování stavu baterie, tlačítko rychlého záznamu času).

Tlačítka mají v tomto režimu speciální funkce:

[OK] - startuje stopky (pokud jsou vynulované), nebo pokračuje v měření času (pokud stopky vynulované nebyly).

Držení tlačítka [nahoru] při běžících stopkách zobrazí a uloží mezičas (stopky běží pořád dál). Zobrazení mezičasu na displeji trvá tak dlouho, dokud je tlačítko stisknuté.

Tlačítko [dolu] stopky zastavuje.

Stisk tlačítka [nahoru] při zastavených stopkách vynuluje stopky i počítadlo mezičasů.

Režim stopky se ukončí současným stiskem tlačítek [nahoru] a [dolu], nebo vypnutím napájení.

## Menu - GPS

Tato položka je dostupná pouze v případě, že je zapnutá přídavná GPS deska.

Pomocí této položky je možné na displeji zobrazit aktuální zeměpisné souřadnice.

Když ještě není k dispozici stabilní GPS signál, zobrazují se na displeji místo souřadnic pomlčky.

Po zafixování signálu se souřadnice zobrazují ve stupních (bez převodu na minuty a vteřiny).

Vzhledem k velkému počtu cifer takového čísla se nezobrazují souřadnice najednou, ale prorotují se na displeji zprava doleva.
Na displeji pak zůstanou zobrazené nejnižší řády souřadnic u kterých dochází k jejich průběžné aktualizaci.

Tlačítky [nahoru] a [dolu] se volí typ souřadnic (zeměpisná šířka, nadmořská výška a zeměpisná délka).
Nadmořská výška v metrech se zobrazuje přímo - bez rotace.

Krátkým stiskem [OK] se vrátí zpátky do menu.

Znak na první sedmisegmentovce určuje polokouli pro zobrazené souřadnice:


Jižní šířka a západní délka je ještě doplněna záporným znaménkem.

Poslední položkou v menu GPS je ovládání trasování.

Po vstupu do této položky je možné zapnout nebo vypnout průběžný zápis GPS souřadnic do GPX souboru na SD kartě.

Aktuální nastavení je signalizováno jako "tr.oFF" při vypnutém trasování, nebo "tr. on" při zapnutém trasování.

Dlouhým stiskem tlačítka [OK] se provede změna stavu. Po uvolnění tlačítka [OK] se nový stav uloží - na displeji problikne "SAVE". Krátký stisk [OK] ponechává nastavení původní.

Zvolený stav se ukládá do EEPROM, takže po vypnutí a následném zapnutí napájení se může v trasování do souboru pokračovat.
V tom případě při zapnutí napájení blikne na displeji nápis "tr. on".

Při zapnutí trasování se vždycky vytváří nový soubor: "TRACK/trck####.gpx". Místo znaků #### se vkládá 4-místné pořadové číslo. Maximum je 9999.
Pak se začne počítat od nuly a staré soubory se začnou přepisovat. Stará data se nemažou, ale nová se přidávají na konec starého souboru, takže pro jejich použití by pak bylo nutné ručně soubory rozdělit.
Proto je lepší staré soubory z karty průběžně odstraňovat.

Funkce trasování nebyla zamýšlena jako nějaká turistická navigace. Šlo spíš o to, zaznamenat si cestu na pozorovací stanoviště, včetně doby trvání přesunu.

Trasovací GPX soubor obsahuje kromě bloku souřadnic aktuální polohy a času jejich záznamu (v UT) ještě dva vypočtené waypointy:
AvgPoint je matematický průměr souřadnic z celého záznamu trasy MidPoint je střední hodnota mezi maximální a minimální souřadnicí. V poznámkách jsou uloženy i časy založení GPX souboru a jeho ukončení (v lokálním čase).
Jen pro doplnění je v GPX souboru i značka <bounds ...>, která udává minima a maxima šířky a délky (možno použít například pro obdélníkový výřez z mapy).

Když je zapnuto filtrování souřadnic příkazem @Gf 1, jsou souřadnice , které projdou přes filtry s výsledkem "BAD", zakomentované, takže se nezobrazují v mapových podkladech ani se nezapočítávají do statistik (AvgPoint a MidPoint).
Souřadnice, které projdou filtry s výsledkem "WAR" (výstraha), se v mapových podkladech objeví, ale stejně jako u "BAD" souřadnic se nezapočítávají do statistik (AvgPoint a MidPoint).

Do GPX souboru bylo doplněno několik dalších parametrů do bloku <extensions>:

<satellites> | aktuální počet zafixovaných satelitů
<hdop> | aktuální horizontal dilution of precision 10x zvětšené číslo, než se získává z NMEA zpráv.
<kmh> | rychlost v km/h převedená z uzlů. (poznámka*1)
<filter> | výsledek po aplikaci filtrů na souřadnice " OK " - souřadnice se zdají být v pořádku "WAR" - výstraha - souřadnice vybočují z obvyklé řady "BAD" - chyba - parametry signálu jsou značně zhoršené "OFF" - filtrování je vypnuté (příkaz @Gf 0)
<debug> | další informace o aktuálním stavu signálu zahuštěná do hexadecimálního řetězce

poznámka *1:
Pro přenos rychlosti je k dispozici jen 1 bajt. Aby byla pro nízké rychlosti (chůzi) zvýšená rozlišovací schopnost, přenáší se rychlost v logaritmizovaném tvaru. Nízké rychlosti (chůze) pak mají rozlišení zhruba v desetinách km/h. Střední rychlosti (kolo) mají rozlišení asi 0,5 km/h. A rychlosti nad 70 km/h mají rozlišení asi 2 až 3 km/h.

V GPX souboru se pak zobrazuje zpátky přepočtená rychlost do reálných km/h. Je ale nutné počítat s tím, že vysoké rychlosti už nemusí být zaznamenány tak přesně.

Příklad zaznamenaného trasového bodu v GPX souboru:
<trkpt lat="+49.445991" lon="+014.366230"><ele>+0548</ele> <time>2026-09-11T13:18:53Z</time><extensions> <satellites>004</satellites><hdop>034</hdop><kmh>016.32</kmh> <filter> OK </filter><debug>0301C501AD0200BFBC</debug> </extensions></trkpt>

Značka <debug> byla zavedena pro ladění filtrů pro určování rozpadu souřadnic. Obsahuje následující informace:
První bajt (dva znaky) je typ fixu (01=žádný fix, 02 =2D fix, 03=3D fix).

Následují dva bajty (4 znaky) s rychlostí v setinách [m/s]
převedené z uzlů. V tomto případě se nic nelogaritmizuje.
Jen se převádí údaj ze SoG ze zprávy GxRMC z uzlů na [m/s].

Další dva bajty (4 znaky) udávají vypočtenou rychlost skoku mezi dvěma posledními přijatými souřadnicemi v setinách [m/s].

Následují jednobajtové (2-znakové) hodnoty:
Rozdíl nadmořských výšek mezi posledními dvěma zprávami

Bitová informace o aktivovaných filtrech
bit2 = některý z xDoP překročil hodnotu 10.0 | .... | BAD
bit3 = málo satelitů a zároveň vysoké HDoP | .... | BAD
bit4 = velký rozdíl sousedních nadmořských výšek | .... | WAR
bit5 = ztráta fixu | .... | BAD
bit6 = zhoršený fix (2D) | .... | WAR
bit7 = velký rozdíl rychlostí SoG a skokem souřadnic .... | BAD

Předposlední bajt je 10x vynásobené zaokrouhlené PDoP.

Poslední bajt je 10x vynásobené zaokrouhlené VDoP.

Příklad: | <debug> 03000B002D01084833</debug>
0x03 | = 3D fix
0x000B= Speed over Ground je po přepočtu 0,11 m/s
0x002D = Rychlost skoku mezi posledními souřadnicemi byla 0,45 m/s
0x01 | = Výškový rozdíl mezi posledními zprávami je 1m
0x08 | = 0b00001000 = málo satelitů, vysoké HDoP = "BAD"
0x48 | = PDoP = 7,2
0x33 | = VDoP = 5,1

Tyto informace jsou dostupné i v případě, že je filtrování vypnuté.

Vzniklý GPX soubor je pak možné přímo importovat do nějakých mapových aplikací


trasa naimportovaná na https://mapy.cz


trasa naimportovaná na https://gpx.studio
Interval zápisu do souboru je nastaven na 20 sekund.
(je možné ho servisně upravit - viz EEPROM adresa 479).

Pokud je povolené blikání LED pro funkci trasování, blikne LED při zápisu dat na kartu.

Souřadnice se ale zapisují jen v případě, že jsou v GPS signálu dostupné.

## Menu - Stanoviště

Tato položka se zobrazuje místo položky GPS - když není modul GPS zapnutý.
Po vstupu do této položky je možné zvolit jedno z 5 předdefinovaných pozorovacích stanovišť. Název zvoleného stanoviště se pak vkládá k záznamu z měření místo GPS souřadnic.

Při zapnutí modulu GPS nebo po poledni se zvolené stanoviště automaticky zruší a je nutné ho zvolit znovu. Je to taková ochrana proti tomu, aby nezůstalo trvale nastavené jedno pozorovací stanoviště, i když se druhý den může pozorovat jinde.

Popis jednotlivých stanovišť a grafická značka pro displej se nastavuje přes sériovou linku.

Defaultně jsou stanoviště nastavena takto:
název do záznamu | značka při listování na displeji
Poz.Stan.1 | 5tAn.1 | (Stan.1)
Poz.Stan.2 | 5tAn.2 | (Stan.2)
Poz.Stan.3 | 5tAn.3 | (Stan.3)
Poz.Stan.4 | 5tAn.4 | (Stan.4)
Poz.Stan.5 | 5tAn.5 | (Stan.5)

Název je obyčejný textový řetězec s délkou 10 znaků.
Značka pro displej je 5 grafických sedmisegmentových znaků.

Způsob editace přednastavených stanovišť je popsán detailně v kapitole "Popis komunikace přes USB"

Je tak možné nastavit třeba pozorovací stanoviště s názvem
"Roh pole", který bude mít na displeji značku "PoLE.1"

Záznam pak vypadá takto:

## Menu - SPEC (režim 30s)

Původně neveřejná speciální funkce, která v krátkých časových intervalech (30 sekund) zaznamenává stav počasí (teplota, tlak, vlhkost). Tyto záznamy se ukládají do přídavné EEPROM.
Ze záznamů jsem pak tvořil grafy do pozorovacího deníku.


Při aktivaci funkce se do menu přidají ještě další položky, které umožňují nastavit interval ukládání počasí a zkopírování obsahu EEPROM na SD kartu.

Detaily funkce jsou popsány ve zvláštním návodu
"sqm_r30s.doc".

## Menu - Úhel

Pokud SQM obsahuje modul pro měření tíhového zrychlení (akcelerometr), je možné používat SQM i pro měření náklonu.

Pro zprovoznění je nutné provést kalibraci náklonoměru pomocí funkce #Nk. Detaily níže v kapitole "Popis komunikace přes USB".
Kalibraci je možné provést i v terénu přes menu (popis na konci kapitoly).

Po úspěšné kalibraci začne fungovat měření náklonu přes menu (položka "uHEL").

Při volbě položky "uHEL" v menu se začne zobrazovat úhel naklonění krabičky:


Apostrof před číslem má signalizovat stupně.

Pokud je měřená hodnota nestabilní, rozsvítí se tečka u první sedmisegmentovky.
V rozsahu 0° (horizont) až 90° (zenit) by měl být zobrazený úhel poměrně přesný.
Úhel se měří i pod horizontem (záporný úhel) a "za" zenitem (úhel větší než 90°). Tam už ale přesnost není zaručena.
V případě záporného úhlu se zobrazuje znaménko '–' na první segmentovce.


Při podržení tlačítka [dolu] se údaj na displeji zastaví na aktuální hodnotě (funkce Data-Hold). Po jeho uvolnění se začne úhel znova měřit.

Tlačítkem [nahoru] se přepíná mezi měřením úhlu náklonu a dvouosou vodováhou.

Vodováha nezobrazuje hodnoty, ale pomocí grafických symbolů na displeji umožňuje nalézt přesnou vodorovnou nebo svislou pozici.

Pokud je úhel naklonění krabičky menší než 45°, zobrazuje se horizontální vodováha.

Tato vodováha při přesné horizontální pozici v obou osách zobrazuje na displeji "obdélník". Pokud nějaká jeho strana chybí, je nutné tu stranu o trochu zvýšit.


Krabička je ve vodorovné pozici.


Je třeba zvednout levý bližší roh.

Svítící tečky u sedmisegmentovek signalizují nestabilní měření náklonu (například při rychlé změně polohy). Obvykle stačí chvíli počkat, než se načtou a zpracují stabilnější hodnoty.

Pokud je krabička nakloněna nad úhel 45°, zobrazuje se vertikální dvouosá vodováha

V tomto typu vodováhy se na krajních sedmisegmentovkách zobrazují "rohy".
Pokud roh chybí, je nutné krabičku na straně s chybějícím rohem zvýšit. Na prostřední sgmentovce se zobrazuje obdélník.
Pokud je vidět jen spodní část obdélníku, je nutné krabičku nahnout směrem k sobě.
Pokud je vidět jen horní část obdélníku, je nutné nahnout krabičku směrem od sebe.


Krabička míří přesně svisle.


Je třeba zvednout pravou stranu a naklonit krabičku od sebe.

Svítící tečky u sedmisegmentovek signalizují nestabilní měření náklonu (například při rychlé změně polohy). Obvykle stačí chvíli počkat, než se načtou a zpracují stabilnější hodnoty.

Při současném stisku tlačítek [nahoru] a [dolu] se vstoupí do režimu kalibrace náklonoměru. Tento stisk musí trvat alespoň 3 sekundy, během kterých se displej zaplňuje výstražnými pomlčkami.

Po uplynutí potřebné doby stisku se na displeji zobrazí nápis "n-CAL" (kalibrace náklonu).
Po chvíli se nápis na displeji změní na "Hori". Po této výzvě se krabička položí horizontálně a stiskne se tlačítko [OK].

Další nápis na displeji "VErt" vyzve k postavení krabičky do vertikální polohy. Poloha se opět potvrdí tlačítkem [OK].

Po úspěšné kalibraci náklonu se změřené hodnoty automaticky uloží (na displeji problikne nápis "SAVE").

## Menu - Astro

Tato položka menu slouží pro astronomické výpočty planet, Slunce a Měsíce a soumraků. Výpočty východů a západů platí pro ideální horizont.

Po vstupu do menu se vybere požadovaný objekt.
Planety (a Pluto) jsou označeny popisky:

Merkur

Venuše

Mars

Jupiter

Saturn

Uran

Neptun

Pluto


Další popisky:

Měsíc

Slunce

Astronomická noc

Uživatelsky nastavitelný soumrak


Možnost zapnutí / vypnutí astro simulace

U planet, Slunce a Měsíce se zobrazují následující informace:

Čas příštího východu nebo západu zvoleného objektu.
Na první segmentovce se zobrazuje znak "^." pro východ, nebo "u." pro západ. Dále následuje lokální čas "h.mm", ve kterém k události dojde.

Východ objektu v 1:28 místního času.

Západ objektu ve 23:23 místního času.

Po stisku tlačítka nahoru se změní čas z hodin a minut na celkový počet minut, po kterých k události dojde. Proti předchozímu zobrazení nesvítí v čísle žádná desetinná tečka, která by oddělovala hodiny a minuty.

Východ zvoleného objektu za 196 minut.

Západ zvoleného objektu za 68 minut

Další stisk tlačítka nahoru přepne na zobrazení azimutu, na kterém k události dojde. Azimut se počítá od severu (0°) přes východ (90°) ....

Zvolený objekt vyjde na azimutu 55°.

Zvolený objekt zapadne na azimutu 288°.

Následující dvě přepnutí zobrazují informace o aktuálním azimutu a elevaci zvoleného objektu.

Zvolený objekt se nachází na azimutu 13°...

... a na elevaci -18° (pod horizontem).

Dále se zobrazuje vzdálenost planety (nebo Slunce) v astronomických jednotkách. Znak "d." je zvolen jako "distance".

Vzdálenost planety od Země je 5,57 AU.

Pro objekt "Měsíc" je zobrazena vzdálenost v tisících km.

Měsíc je 400 800 km daleko.

Pokud je za znakem "d." zobrazen znak "%" (pro objekty Slunce a Měsíc), je vzdálenost přepočítána na 0% až 100% z rozsahu perihelu a apohelu (nebo perigea a apogea u Měsíce).
Když je Měsíc v perigeu (nejblíž Zemi), zobrazí se 0%. V apogeu (nejdál od Země) se zobrazí 100%.

Slunce (Měsíc) je aktuálně ve 43% vzdálenosti mezi minimální a maximální vzdáleností.

Pro Měsíc, Merkur a Venuši je možné zobrazit ještě stav jejich osvětlení v procentech.

Planety mají rozlišení na desetiny procenta.

Měsíc zobrazuje osvětlení zaokrouhlené na celá procenta.

Objekt Měsíc obsahuje ještě informaci o colongitudu
(na jakém měsíčním poledníku se nachází ranní terminátor).
Tato hodnota je od 0 do 359°.

Z Cologituda je pak ještě přepočítávána pozice viditelného terminátoru. Viditelný terminátor má hodnotu -90 až +90°.
Kladné číslo v zobrazení terminátoru znamená východní délku (od středu směrem k Moři nepokojů), záporné číslo je západní délka (od středu směrem ke kráteru Koperník).

Colongitudo je 332 stupňů

Viditelný terminátor je na 28 stupních východně.

Pro Merkur a Venuši se počítá ještě elongace (aktuální úhlová vzdálenost ve stupních od Slunce).
Na displeji je popisek "Eo.r." když je planeta viditelná ráno, nebo "Eo.V." když je planeta viditelná večer.

Elongace planety je 15° a je viditelná večer.

Elongace planety je 13° a je viditelná ráno.

Elongace se počítá i pro Měsíc, ale jen v tom případě, že se Měsíc nachází poblíž Slunce.
Omezení je hlavně z toho důvodu, že Měsíc může mít elongaci až 180° (při úplňku) a takové číslo už by se nevešlo na displej.
Konkrétně se elongace Měsíce počítá jen do 30% osvětlené části Měsíce (to je 60° úhlové vzdálenosti od Slunce).


Poslední počítanou položkou pro planety je jejich magnituda.

Magnituda planety (Venuše) je -3,92.

Tady pozor na Saturn. Měl jsem problém s počítáním magnitudy prstenců, a proto je jejich magnituda jen na hrubo odhadnutá zjednodušeným výpočtem.
Zjednodušený výpočet se proto od skutečné hodnoty může o pár desetin magnitudy lišit.

Graf rozdílů přesných magnitud z CdC proti zjednodušeným výpočtům pro příštích 50 let

Pro položku "noc" se počítá čas začátku astronomické noci (čas kdy Slunce klesne 18° pod horizont).

Začátek astronomické noci nastane ve 23:23.

Dalším přepnutím se spočte čas konce astronomické noci (čas kdy Slunce vystoupá nad hranici -18° pod horizontem).

Konec astronomické noci nastane ve 2:57.

Je možné zobrazit i dobu trvání astronomické noci v minutách.

Astronomická noc trvá 214 minut

V období kolem letního slunovratu se v našich zeměpisných šířkách může stát, že astronomická noc nenastane (Slunce neklesne dostatečně nízko pod horizont).
V tom případě se místo času začátku nebo konce zobrazí pomlčky a trvání noci je pak nulové.

Když v okamžiku vstupu do položky menu astronomická noc není, provádí se výpočty pro následující noc.
Spočte se, kdy další noc začne.

Když při vstupu do položky astronomická noc už je, provádí se výpočty pro aktuální noc.
Spočte se, kdy tato noc začala.

Položka "SouMr" je velice podobná položce "noc" s tím rozdílem, že hodnotu elevace Slunce pod horizontem je možné uživatelsky nastavit. Nastavení se provádí přes sériovou linku příkazem @N.
Správným nastavením je možné například zjišťovat čas, kdy se objeví první hvězdy.

Všechny astro výpočty jsou závislé na správném nastavení domácích souřadnic a místní časové zóny

Tyto parametry jsou uložené v EEPROM a je možné je upravit pomocí následujících příkazů:

Změnu souřadnic je možné provést přes sériovou linku příkazem
@Gd nn.n pro zeměpisnou délku
@Gs nn.n pro zeměpisnou sirku

nn.n je zeměpisná délka nebo šířka ve stupních (s přesností na 1 desetinné místo).

@Gl nn časový posun proti UT v létě (+2 pro SELČ) - 3. znak je malé L @Gz nn časový posun proti UT v zimě (+1 pro SEČ)

V terénu je možné převzít souřadnice z GPS dlouhým současným stiskem tlačítek [nahoru] a [dolu] při zobrazených souřadnicích v menu GPS.

Nastavené parametry se zobrazují ve výpisu systémových informací (příkaz "i").

Aktualni souradnice pro astro vypocty (delka / sirka): [E] 14.4 / [N] 49.6

Od verze 2026-06-13 byla do "Astro" menu doplněna funkce "Simulace". Při jejím zapnutí je možné nastavit datum, čas a časovou zónu pro požadovaný okamžik simulace. Nastavení se provádí přes menu položkami "dAtuM", "CAS " a "ZonA". Při zapnuté simulaci se úpravami hodnot těchto položek neovlivňuje vnitřní časovač.
Po resetu dojde vždycky k automatickému vypnutí simulace a položky "dAtuM", "CAS " a "ZonA" pak fungují obvyklým způsobem.

Zapnutí simulace

Vypnutí simulace

## Menu - Kompas

Pokud je osazený modul LSM303DLHC, objeví se
v menu položka "CoMPA" (kompas).

Po jejím zvolení se na displeji zobrazí znak "A." za kterým následuje azimut, kterým směřuje čidlo světla (přední část krabičky).

Azimut se v SQM počítá "běžným" způsobem:
(sever = 0°, východ = 90°, jih = 180°, západ = 270°)

Některé starší astronomické příručky uvádějí azimut počítaný od jihu. V tomto systému ale SQM nepracuje.

Před zobrazením dochází ke klouzavému průměrování posledních 5 změřených hodnot azimutu.
Když je ale rozdíl mezi posledními 5 hodnotami větší než 10°, je měření označeno jako nestabilní a k průměrování nedochází.
Zobrazí se poslední změřená hodnota a jako výstraha před nepřesným měřením se rozsvítí na displeji všechny desetinné tečky.
V tom případě stačí chvíli počkat, než se načtou stabilnější hodnoty.

Držením tlačítka [dolu] při zobrazení azimutu se údaj na displeji zmrazí (funkce Data-Hold).

Pro správnou funkci kompasu je nutné provést kalibraci.

Kalibraci je možné spustit dvěma způsoby:
- příkazem přes sériovou linku (#Mk).
- stiskem tlačítka [nahoru] při zobrazeném azimutu.

Aby nedošlo k náhodnému nechtěnému spuštění kalibrace, je nutné držet tlačítko [nahoru] delší dobu (přes 2 sekundy).
Během tohoto držení se displej zaplňuje výstražnými pomlčkami.

Po uplynutí potřebné doby držení tlačítka problikne na displeji nápis "C-CAL". Tím je kalibrace spuštěna.

Pak se začne zobrazovat 10-sekundový odpočet.
Při tomto odpočtu je nutné otáčet krabičkou ve všech směrech a hledat extrémy zemského magnetického pole ve všech osách.
Když extrém není nalezen, probíhá odpočet. Při nalezení extrému se odpočet vrací zpátky na 10 sekund.

Po doběhnutí odpočtu do 0 se vyhodnotí, jestli jsou zjištěné extrémy dostatečné pro kvalitní výpočet azimutu.
Pokud ne, zahlásí SQM chybu "Err-C" (chyba kompasu) a nastaví se defaultní kalibrační hodnoty.
Tyto defaultní hodnoty slouží jen k tomu, aby při výpočtech nedocházelo k matematickým chybám (například dělení nulou), ale na zobrazený azimut se nedá spolehnout.

## Menu - Ra / Dec

Pokud je osazený modul LSM303DLHC, je zpřístupněna položka v menu, která umožňuje zadat rovníkové souřadnice hledaného objektu (rektascenze a deklinace).

Po vstupu do této položky menu se na displeji rozsvítí nápis "rA.". pomocí tlačítek [nahoru] a [dolu] se zadává rektascenze v rozsahu 0.0 až 23,9 h.
Delší držení tlačítek zrychluje změnu zadávaného čísla.

Potvrzení se provede stiskem tlačítka [OK].

Následuje zadávání deklinace. Na displeji svítí nápis "dE." a zadává se číslo v rozsahu -90 až +90°.

Po potvrzení zadaného čísla proběhne přepočet na místní azimut a elevaci. K výpočtu se používá systémový čas a domácí souřadnice.

Na displeji problikne nápis "HLEdA" (hledání). Pak se začne zobrazovat úhlová vzdálenost mezi zadanými souřadnicemi a aktuálním namířením krabičky.

Pokud je tato úhlová vzdálenost menší než 1,5°, začne přístroj pípat.

Při stisku tlačítka [nahoru] se zobrazí vypočtená elevace.
Na první sedmisegmentovce je zobrazený znak ° (').
Pokud na této sedmisegmentovce svítí i desetinná tečka, znamená to nestabilní měření náklonu.

Při stisku tlačítka [dolu] se zobrazí vypočtený azimut.
Na druhé sedmisegmentovce je zobrazený znak "A.".

Stiskem tlačítka [OK] se ukončí režim hledání a provede se návrat do menu.

## Menu - Alarm

Funkce slouží k nastavení až 6 budíků. V nastaveném čase se SQM zapne a alarm se spustí.
Prvních 5 alarmů se nastavuje zadáním času spuštění
ve formátu hh.mm.
Poslední typ alarmu se zadává jako odpočet v minutách
s rozsahem -1 až -999.

Ke spuštění alarmu dojde i při vypnutém hlavním vypínači.
Při aktivaci budíku se pomocí tranzistoru překlene hlavní vypínač a SQM se spustí.
Ke správné funkci ale potřebuje mít na základní desce osazený RTC obvod DS3231 a jeho okolí (spínací FETy a nějaké odpory, které přemostí hlavní vypínač).

Při aktivním alarmu bliká prvních 10 sekund na displeji jen nápis.
Pak se k blikání přidá i pípání.
Pokud nedojde k ukončení libovolným tlačítkem, vypne se alarm po dvou minutách automaticky.

Vypnutím dojde zároveň k vymazání příslušného alarmu z paměti. Pokud existuje více zadaných alarmů se stejným časem, maže se jen jeden z nich. Další z alarmů se stejným časem bude spuštěn za 24 hodin.

Při blikání se střídá nápis "ALArM" a index aktuálně probíhajícího alarmu.

Spuštění i vypínání alarmu je zaznamenáváno do souboru "SYS_LOG.TXT" na SD kartě.
Speciální kód pro logování alarmů je 991. Spuštění má hodnotu 0, vypnutí se loguje jako počet sekund od zapnutí alarmu.
Když se provede automatické vypnutí po dvou minutách zapíše se hodnota 120.
Nižší číslo znamená ruční vypnutí tlačítkem.

Pokud je SQM zapnuté, je čas v DS3231 je pravidelně (1× za hodinu, nebo při každém přenastavení času nebo časové zóny) synchronizován s vnitřním časem hlavního procesoru.
Synchronizace času je logována do souboru "SYS_LOG.TXT" na SD kartě.
V tomto případě se zaznamenává i počet sekund, o které se časy v RTC hlavního procesoru a DS3231 rozcházejí.

Pro logování se používají dva kódy:
kód 989 = DS3231 se zpožďuje (nebo je čas stejný jako v STM32) kód 990 = DS3231 se předchází
Za kódem následuje počet sekund rozdílu časů.
Pokud by se stalo, že je bude rozdíl času vyšší než 999 sekund (například při změně časové zóny), bude místo počtu sekund zobrazena značka "^^^".
Je to z toho důvodu, aby zůstala zachována šířka řádek v celém logovacím souboru na stejném počtu znaků.

Po vstupu do položky "Alarm" dlouhým stiskem [OK] se zobrazí nastavení prvního budíku.
Pokud není aktivní, zobrazí se nápis "b. ---1".
Číslo na konci signalizuje index budíku 1 až 5.

Tlačítky [nahoru] a [dolu] je možné index budíku přepínat.

Když je zvolený index budíku aktivní, zobrazí se místo indexu nastavený čas s tečkou jako oddělovačem hodin a minut (například "b.18.45").

Dlouhý stisk tlačítka [OK] vstoupí do nastavení času konkrétního budíku.

Nastavení času se provádí zadáním hodin a minut, při kterých se má alarm zapnout (čas v místní časové zóně).
Je to podobné, jako při nastavení času (nejdřív se zadávají hodiny v rozsahu 0 až 23, dlouhý stisk [OK] hodnotu potvrdí, pak se zadávají minuty v rozsahu 0 až 59 a opět dlouhý stisk [OK] hodnotu potvrdí). Při pokusu o nastavení 24 hodin se na displeji objeví pomlčky, které signalizují vypnutý budík.
Čas je možné zadat maximálně 23 hodin a 59 minut dopředu.

Poslední (šestou) položkou v seznamu alarmů je odpočtový alarm, který se signalizuje nápisem: "o.----" (když není aktivní).
Aktivní odpočtový alarm se zobrazuje ve tvaru "o.-457" a zadává se jako odpočet v minutách. Jako maximální interval je možno zadat -999 minut (to je něco přes 16 a půl hodiny).
Při zadání hodnoty odpočtu na 0 minut se odpočet zruší. Na displeji se místo 0 zobrazí pomlčky.

Číslo za znaky "o.-" udává, kolik minut zbývá do alarmu a průběžně se aktualizuje.

Když odpočet doběhne do 0, spustí se alarm (i při vypnutém hlavním vypínači). Rozdíl proti prvním 5 alarmům je jen v blikajícím nápisu. Bliká nápis "odPoc" bez indexu.

## Menu - Volty

Tato funkce zobrazí na displeji skutečné napětí připojené baterie ve voltech.

Je to zpřesnění původní funkce blikajících teček na displeji.

Vzorec pro přepočet se nachází na dvou místech:
v souboru "stm411.ino" v bloku #doc#11
a v souboru "menu_dis.ino" v bloku #doc#14
// DZ1=1.8V | R8 / R7+R8
napeti_9V = ((((1.8 / ref_in) * 10 * Vcc * bat_in) / 4096.0) / (8.2 / 108.2)) + 0.5;
Přesnost záleží na skutečných hodnotách odporů R7 a R8.

V posledních verzích programu bylo doplněno měření referenčního napětí (1,8V), napájecího napětí procesoru (3,3V) a měření napětí zálohovací baterie (3V). Přepínání testovaných napětí se provádí tlačítky [nahoru] a [dolu].

První znak na displeji udává aktuální měřené napětí:
"U." ... | napětí hlavní baterie nebo externího zdroje [V].
"P." ... | napětí na procesoru (ideálně 3,30V)
"r." ... | referenční napětí (ideálně 1,80V)
"b." ... | stav zálohovací baterie (v [%] z rozsahu 1,65V až 3,1V.)

Poznámka:
Při napájení SQM přes USB se dělič napětí z odporů R7 a R8 obchází, a proto je zobrazené napětí hlavní baterie "U." někde mezi 14 až 15V.
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

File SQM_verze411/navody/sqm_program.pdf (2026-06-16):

# Měřič kvality oblohy

# (amatérské SQM)

http://sqm.AstroMiK.org


## Návod pro úpravy SW

SW: | STM32 | 2026-06-16 (STM32F4x1)
| ATmega328 | 2026-05-17..int

16.6.2026

Strana 1/39

## OBSAH

## Úvod

Tento návod obsahuje detailní informace o programu, jeho možných úpravách a přizpůsobení.

## Organizace vnitřní EEPROM

Uvnitř SQM se nachází paměť, do které se ukládají jednotlivé záznamy. Tato paměť je trvalá a pamatuje si zapsané údaje i při vypnutí napájení.

Pro ukládání záznamů slouží oblast od buňky s adresou 700 až do konce paměti (adresa 131071).

Na začátku paměti jsou uložené systémové parametry a kalibrační tabulky.

Adresy v EEPROM jsou nadefinované na začátku programu v souboru "stm411.ino" v bloku #doc#10:

#define eeaddr_RTC_set | 0UL

#define eeaddr_RTC_korekce | 4UL

#define eeaddr_leto_zima | 8UL

#define eeaddr_oddelovace | 9UL

#define eeaddr_automat | 10UL

#define eeaddr_prumerovani | 11UL

#define eeaddr_modbus_LED | 12UL

#define eeaddr_LED | 13UL

#define eeaddr_SLAVE_baud | 14UL

#define eeaddr_CRC_tset_lock | 15UL

#define eeaddr_stab | 16UL

#define eeaddr_pocet_cidel | 17UL

#define eeaddr_10kB_znacka | 18UL

#define eeaddr_uroven_EEPROM | 19UL

#define eeaddr_teplotni_kalibrace | 20UL

#define eeaddr_TS_stanoviste | 48UL

#define eeaddr_svetelna_kalibrace | 50UL

#define eeaddr_TS_aktual | 470UL

#define eeaddr_kompas_offset | 471UL

#define eeaddr_perif_bity | 472UL

#define eeaddr_beep_bity | 474UL

#define eeaddr_elevace_soumrak | 476UL

#define eeaddr_GPS_track_id | 477UL

#define eeaddr_GPS_track_interval | 479UL

#define eeaddr_AUTOkom | 480UL

#define eeaddr_CALIB_znacka | 481UL

#define eeaddr_eeaddr_MOD_autoupdate482UL

#define eeaddr_bortle | 483UL

#define eeaddr_servis | 484UL

#define eeaddr_GEO_lat | 485UL

#define eeaddr_GEO_lon | 487UL

#define eeaddr_zima_hod | 489UL

#define eeaddr_leto_hod | 490UL

#define eeaddr_menu_bity | 491UL

#define eeaddr_posledni_den | 495UL

#define eeaddr_AfD | 499UL

#define eeaddr_stanoviste | 500UL

#define eeaddr_txt_zony | 575UL

#define eeaddr_luxmetr | 583UL

#define eeaddr_AFD_styl | 589UL

#define eeaddr_eeaddr_autokalibrator590UL

#define eeaddr_rezerva_2 | 591UL

#define eeaddr_test_write | 599UL

#define eeaddr_kompas | 600UL

#define eeaddr_naklon_horiz | 612UL

#define eeaddr_naklon_vert | 618UL

#define eeaddr_alarmy | 624UL

#define eeaddr_TEST_alarm | 636UL

#define eeaddr_DSO_setup | 637UL

#define eeaddr_DSO_prumery | 639UL

#define eeaddr_DSO_ohniska | 645UL

#define eeaddr_DSO_okulary | 651UL

#define eeaddr_DSO_normal_MSA | 656UL

#define eeaddr_rezerva_3 | 657UL

#define eeaddr_MIN_EEPROM | 700UL

Konkrétně tedy vypadá obsazení paměti takto:

adresa | popis
0 až 3 | čas posledního seřízení RTC v sekundách od
1.1.1970
4 až 7 | za jak dlouho se má přidávat nebo ubírat
autokalibrační sekunda k vnitřnímu času
(detailně popsáno v kapitole " Vnitřní hodiny (RTC)")
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

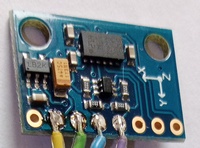
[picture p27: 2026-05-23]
SQM_verze411/webconfig/lsm303_iko.jpg

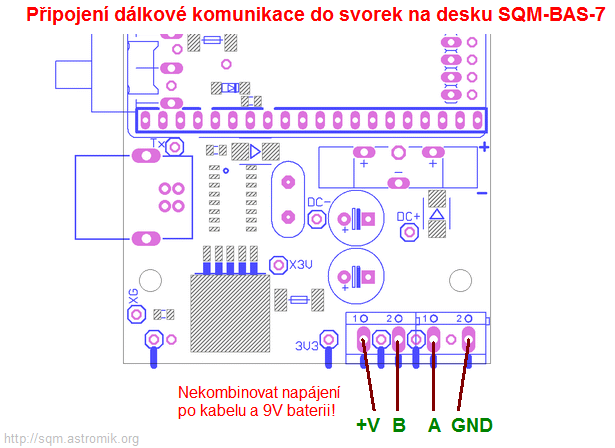
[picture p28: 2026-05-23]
SQM_verze411/webconfig/propoj_485_bas.gif

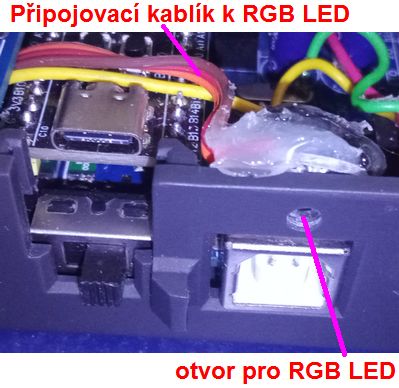
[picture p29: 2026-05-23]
SQM_verze411/webconfig/fot_rgb_krabicka.jpg

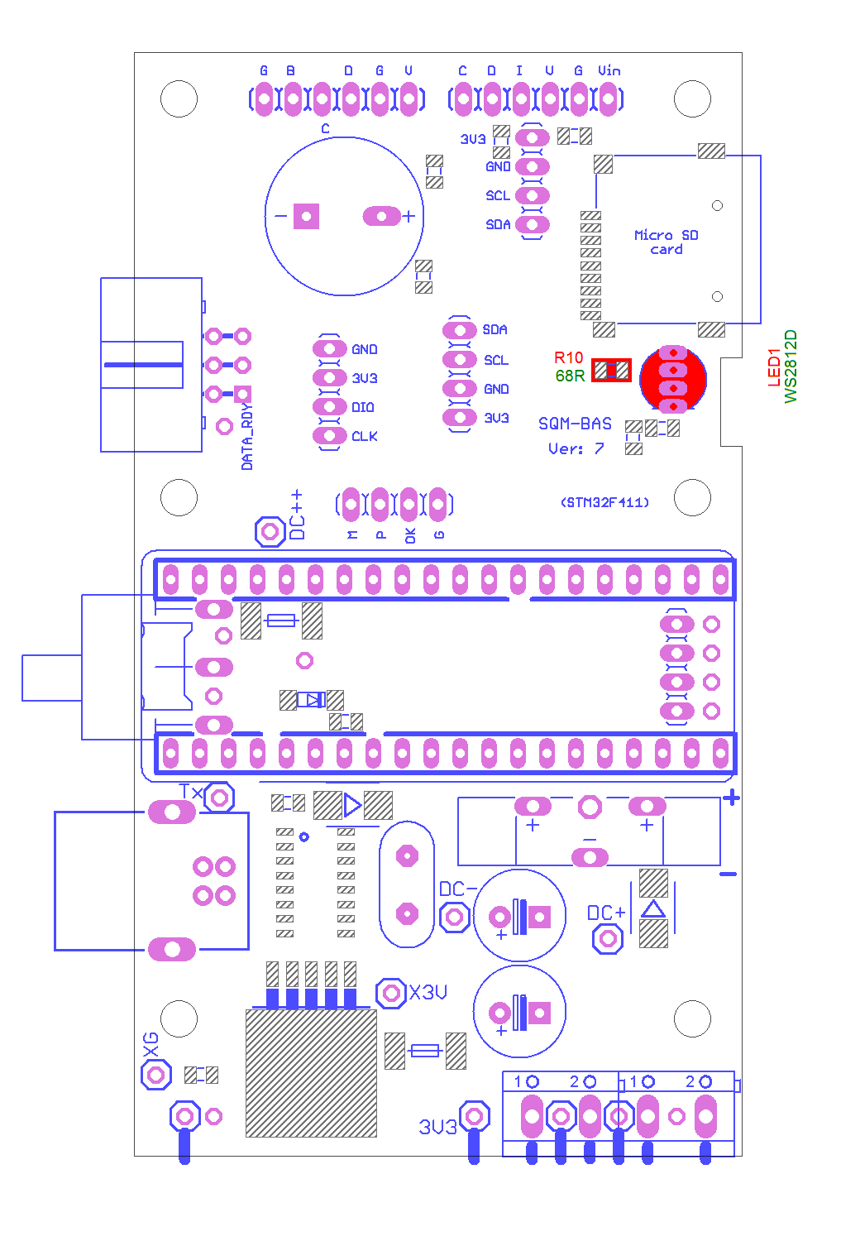
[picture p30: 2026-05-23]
SQM_verze411/webconfig/led_top.gif

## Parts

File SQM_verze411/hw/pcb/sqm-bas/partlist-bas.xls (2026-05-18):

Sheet: List1
Mechanika
 | krabička
4 | sloupky pod displej | https://www.laskarduino.cz/distancni-sloupek-f-f-m3-17mm--mosaz/
4 | distanční sloupky pro sešroubování krabičky
1 | čočka pro čidlo světla
3 | Tlačítka na krabičku

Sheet: varianty osazení
Osazení součástek pro desku SQM-BAS-7
 | SQM je připraveno pro dvě základní verze použití:
 | 1) ruční přístroj s displejem
 | 2) pevně nainstalovaný přístroj
 | Součástky se na desku SQM-BAS-7 osazují podle zamýšleného způsobu použití.
 |  | Například u pevně nainstalovené verze je zbytečné osazovat displej nebo GPS modul.
 |  | U ruční verze je zase zbytečná komunikace RS485 nebo signalizační LED.
 | Níže je popsané doporučení pro osazení obou variant.
 | Nepovinná rozšíření je pak možné libovolně kombinovat s jedinou výjimkou:
 |  | Při osazení rozšiřující desky pro GPS není možné zároveň osadit napájecí a komunikační svorkovnici pro RS485.
 |  | Komunikační signály A a B zůstávají ale dostupné na desce SQM-GPS-6 jako pájecí body (dírky).
 |  | Stejně tak i napájení je možné připojit do dírek přímo na desce SQM-GPS-6
Povinný minimální základ pro obě verze
 |  |  | jméno | hodnota | pouzdro | popis | odkaz | funkce
 |  |  | PCB | SQM-BAS-7 |  |  | http://sqm.astromik.org | plošný spoj
 |  |  | MOD1 | STM32F411CEU | BLACK411_PILL | procesorová deska WeAct | https://www.aliexpress.com/item/1005005953179540.html | modul BlackPill s procesorem deska STM (místo verze 411 je možné použít i verzi 401)
 |  |  | MOD2 | TSL2591 |  | modul pro měření jasu | https://www.aliexpress.com/item/1005006864126085.html | modul pro měření jasu
 |  |  | JP7-F |  | 1X04 / 8,5 / 2,54 | jednořadá dutinková lišta | https://www.tme.eu/cz/details/zl262-20sg/konektory-hrebinky/connfly/ds1023-1-20s21/ | dutinková lišta pro připojení modulu BlackPill
 |  |  | JP10-F |  | 1x20 / 8,5 / 2,54 | jednořadá dutinková lišta | https://www.tme.eu/cz/details/zl262-20sg/konektory-hrebinky/connfly/ds1023-1-20s21/ | dutinková lišta pro připojení modulu BlackPill
 |  |  | JP11-F |  | 1x20 / 8,5 / 2,54 | jednořadá dutinková lišta | https://www.tme.eu/cz/details/zl262-20sg/konektory-hrebinky/connfly/ds1023-1-20s21/ | dutinková lišta pro připojení modulu BlackPill
 |  |  | SW1 | SS-12D06L5 | SLIDE_SW | posuvný přepínač, 2 polohy / 90° | https://www.laskarduino.cz/posuvny-prepinac-3a-250vac-ss-12d06l5/ | hlavní vypínač
 |  |  | TR3 | SMBJ33A-13-F | SMBJ | Jednosměrný transil 36,7V | https://www.tme.eu/cz/details/smbj33a-13-f/transil-diody-jednosmerne-smd/diodes-incorporated/ | ochranný transil na vstupním napájení
 |  |  | USB1 | USBPTH | USB-B-PTH | USB-B zásuvka do pl. spoje | https://www.tme.eu/cz/details/usbb-g/konektory-usb-a-ieee1394/connfly/ds1099-wn0/ | USB konektor pro připojení k PC
 |  |  | F1 | 500mA | FUSE1812 | PolyFuse | https://www.tme.eu/cz/details/0zcg0050ff2c/polymerove-pojistky-smd/bel-fuse/ | vratná pojistka pro napájecí zdroj
 |  |  | F2 | 500mA | FUSE1812 | PolyFuse | https://www.tme.eu/cz/details/0zcg0050ff2c/polymerove-pojistky-smd/bel-fuse/ | vratná pojitka pro ochranu USB napájení
 |  |  | IC2 | AP1501S | TO263-5 | StepDown regulátor 3,3V | https://www.tme.eu/cz/details/ap1501-33k5g-13/stabilizator-napeti-obvody-dc-dc/diodes-incorporated/ | pro napájecí DC-DC převodník
 |  |  | IC3 | CH340G | SOIC16 | Převodník UART - USB | https://www.laskarduino.cz/prevodnik-usb-uart-ch340g--sop-16/ | pro USB komunikaci s PC
 |  |  | IC4 | M24M01-RMN6TP | SO8 | I2C EEPROM - 128k x 8b | https://www.tme.eu/cz/details/m24m01-rmn6tp/pameti-eeprom-seriove/stmicroelectronics/ | hlavní EEPROM (128kB)
 |  |  | D3 | B340A-13-F | SMB | SCHOTTKY-DIODE_SMD | https://www.tme.eu/cz/details/b340a-13-f/diody-schottky-smd/diodes-incorporated/ | pro napájecí DC-DC převodník
 |  |  | D4 | B340A-13-F | SMB | SCHOTTKY-DIODE_SMD | https://www.tme.eu/cz/details/b340a-13-f/diody-schottky-smd/diodes-incorporated/ | zabránění přenosu napětí do USB
 |  |  | D5 | B340A-13-F | SMB | SCHOTTKY-DIODE_SMD | https://www.tme.eu/cz/details/b340a-13-f/diody-schottky-smd/diodes-incorporated/ | zabránění přenosu napětí do USB
 |  |  | C5 | 100n | 0805 | C-KERAMIK_SMD_0805 |  | kondenzátor na napájecích pinech hlavní EEPROM
 |  |  | C6 | 22p | 0805 | C-KERAMIK_SMD_0805 |  | kondenzátor u krystalu USB převodníku
 |  |  | C7 | 22p | 0805 | C-KERAMIK_SMD_0805 |  | kondenzátor u krystalu USB převodníku
 |  |  | C8 | 100n | 0805 | C-KERAMIK_SMD_0805 |  | kondenzátor u USB převodníku
 |  |  | L1 | 33mH | SMD_INDUCTOR | SMD_INDUCTOR | https://www.tme.eu/cz/details/hpi1040-330/vykonne-tlumivky-smd/ferrocore/ | tlumivka pro napájecí DC-DC převodník
 |  |  | D2 | B340A-13-F | SMB | SCHOTTKY-DIODE_SMD | https://www.tme.eu/cz/details/b340a-13-f/diody-schottky-smd/diodes-incorporated/ | ochrana proti přepólování baterie
 |  |  | C9 | 10u | 0805 | C-KERAMIK_SMD_0805 |  | kondenzátor na napájení u modulu měření světla
 |  |  | C1 | 100u/35V | C-EL_3,5 | C-ELEKTROLYT_3,5 |  | elektrolyt na vstupu DC/DC převodníku (4 až 30V)
 |  |  | C2 | 100u/16V | C-EL_3,5 | C-ELEKTROLYT_3,5 |  | elektrolyt na výstupu DC/DC převodníku (3,3V)
 |  |  | C3 | 10u | 0805 | C-KERAMIK_SMD_0805 |  | USB napájení
 |  |  | Q1 | 12MHz | HC-49U | krystal | https://www.laskarduino.cz/krystalovy-rezonator-12mhz--yic-12-00m-hc49-s/ | krystal pro USB převodník CH340G
 |  |  |  |  | FIX-QW-1 | izolační podložka pod krystal | https://www.tme.eu/cz/details/fix-qw-1/distancni-sloupky-plastove/fix-fasten/ | podložka pod krystal sice není povinná, ale doporučuji ji osadit
 |  |  | R12 | 10k | 0805 | R_SMD_0805 |  | Pull-Down pro signál Data-Ready
 |  |  | R13 | 10k | 0805 | R_SMD_0805 |  | Pull-Down pro spouštění DC-DC převodníku
 |  | Povinné pro ruční verzi s displejem
 |  |  | MOD5 | SQM-DIS-3 |  | deska displeje | http://sqm.astromik.org | deska s pěti 7-segmentovými zobrazovacími jednotkami (samostatná dokumentace)
 |  |  | JP3-F |  | 1X04 / 8,5 / 2,54 | jednořadá dutinková lišta | https://www.tme.eu/cz/details/zl262-20sg/konektory-hrebinky/connfly/ds1023-1-20s21/ | dutinková lišta pro připojení desky SQM-DIS-3 (řízení displeje)
 |  |  | JP4-F |  | 1X04 / 8,5 / 2,54 | jednořadá dutinková lišta | https://www.tme.eu/cz/details/zl262-20sg/konektory-hrebinky/connfly/ds1023-1-20s21/ | dutinková lišta pro připojení desky SQM-DIS-3 (tlačítka)
Z následujících variant zálohování RTC je nutné vybrat jen jednu!
doporučeno pro
ruční verzi | pevnou verzi
 |  | Pro verzi s 3V zálohovací baterií místo superkapacitoru
 |  | Baterie udrží vnitřní hodiny v chodu delší dobu i při vypnutém napájení. Jednou za čas (za rok) je ale nutná výměna.
X |  |  | BAT1 | CR2032-VERT | CR2032-VERT | držák baterie 2032 | https://www.ebay.com/itm/5PCS-Black-Plastic-CR2032-Cell-Button-Lithium-Battery-Holder-Sockets-Case-3V/173619359432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 | vertikální držák pro 3V zálohovací baterii (pro RTC)
X |  |  |  | CR2032 |  |  |  | knoflíková baterie 3V
 |  | Alternativa pro verzi se superkapacitorem místo 3V zálohovací baterie
 |  | Superkapacitor je vhodnější pro vykrývání krátkodobých (několikahodinových) výpadků napájení, ale při dostupném hlavním napájení pak pracuje trvale bez nutnosti výměny.
 | X |  | SUPCAP | 1F / 5,5V | Ø19x20,5 vert | Superkapacitor | https://www.tme.eu/cz/details/bcev-5.5v-1.0f/superkondenzatory/bigcap/bce005r5v105fs/ | alternativní superkapacitor místo vertikálního držáku zálohovací baterie
 | X |  | R11 | 1k | 0805 | R_SMD_0805 |  | odpor pro nabíjení superkapacitoru jako alternativa k zálohovací 3V baterii
 | X |  | D6 | B340A-13-F | SMB | SCHOTTKY-DIODE_SMD | https://www.tme.eu/cz/details/b340a-13-f/diody-schottky-smd/diodes-incorporated/ | nabíjení alternativního superkapacitoru
 | X |  | D7 | B340A-13-F | SMB | SCHOTTKY-DIODE_SMD | https://www.tme.eu/cz/details/b340a-13-f/diody-schottky-smd/diodes-incorporated/ | vybíjení alternativního superkapacitoru
Nepovinná rozšíření
doporučeno pro
ruční verzi | pevnou verzi
 |  | Rozšíření o SD kartu
 |  | Na SD kartu se ukládají záznamy v čitelném textovém formátu (CSV) a je tak zajištěn jejich jednoduchý přenos do PC k dalšímu zpracování.
 |  | Mimo to se na SD kartu mohou ukládat i další informace - například o změnách nastavení parametrů, časové odchylky při seřizování času ...
 |  | Když se toto rozšíření nepoužije, zakázat ho i v programu v bloku #doc#02 ...... bool osazeno_SD_card = false;
X | X |  | MICRO_SD1 | MCSP-Q1-ASG-T/R | MICRO_SD |  | https://www.vpcentrum.eu/konektor-pro-karty-sd-micro-push-push-smt-gold-flash-1 | držák mikro SD karty pro záznamy
X | X |  |  |  |  |  |  | mikro SD karta (16G / FAT32)
X | X |  | C4 | 100n | 0805 | C-KERAMIK_SMD_0805 |  | kondenzátor na napájecích pinech SD karty
 |  | Rozšíření o měření teploty, tlaku a vlhkosti
 |  | Když se toto rozšíření nepoužije, zakázat ho i v programu v bloku #doc#02 ...... bool osazeno_BME280 = false;
X | X |  | MOD3 | BME280 / 3,3V |  |  | https://www.aliexpress.com/item/1005006330566170.html | modul pro měření teplty, tlaku a vlhkosti
X | X |  | C10 | 10u | 0805 | C-KERAMIK_SMD_0805 |  | kondenzátor na napájení u modulu měření teploty, tlaku a vlhkosti
 |  | Rozšíření o akustickou signalizaci
 |  | Osazenou signalizaci je možné později vypnout jednoduchým přenastavením parametrů.
X | X |  | T1 | BSS138 (N-FET) | SOT23 |  | https://www.tme.eu/cz/details/bss138-tp/tranzistory-s-kanalem-n-smd/micro-commercial-components/ | N-FET pro ovládání pískáku
X | X |  | REP1 | BZEN1205 | KPE242 |  | https://www.tme.eu/cz/details/ld-bzen-1205/elektromag-signalizatory-bez-generatoru/loudity/ | pasivní bzučák (reproduktorek) pro zvukovou signalizaci
X | X |  | R14 | 10k | 0805 | R_SMD_0805 |  | Pull-Down pro pískák
 |  | Rozšíření o náklonoměr a kompas
 |  | Pro pevně nainstalovanou verzi je zbytečný (pořád stejný azimut a náklon)
 |  | Když se toto rozšíření nepoužije, zakázat ho i v programu v bloku #doc#02 ...... bool osazeno_LSM303 = false;
X |  |  | MOD4 | LSM303DLHC |  | GY-511 | https://www.aliexpress.com/item/32255613600.html | modul pro měření náklonu a magnetického pole
 |  | Rozšíření o režim "r30s"
 |  | Rychlý záznam teploty, tlaku, vlhkosti a osvětlení v [lx] do extra paměti
 |  | Když se toto rozšíření nepoužije, zakázat ho i v programu v bloku #doc#02 ...... bool osazeno_r30s = false;
X |  |  | IC5 | 24LC512 | SO8 | I2C EEPROM - 64k x 8b | https://www.tme.eu/cz/details/24lc512-i_sn/pameti-eeprom-seriove/microchip-technology/ | 64kB EEPROM pro režim "r30s"
X |  |  | C11 | 100n | 0805 | C-KERAMIK_SMD_0805 |  | kondenzátor na napájecích pinech EEPROM pro "r30s"
 |  | Rozšíření o možnost probouzení SQM i při vypnutém hlavním vypínači (budík)
 |  | V pevně nainstalované verzi nemá toto rozšíření smysl
 |  | Když se toto rozšíření nepoužije, zakázat ho i v programu v bloku #doc#02 ...... bool osazeno_DS3231 = false;
X |  |  | IC6 | DS3231(M) / SO8 | SO8 |  | https://www.aliexpress.com/item/1005007298381468.html | RTC obvod pro probouzení zařízení i při vypnutém hlavním vypínači
X |  |  | R15 | 100k | 0805 | R_SMD_0805 |  | Pull-Up pro /INT výstup RTC obvodu DS3231
X |  |  | R16 | 33k | 0805 | R_SMD_0805 |  | omezovací dělič napětí pro probouzení pomocí DS3231
X |  |  | R17 | 33k | 0805 | R_SMD_0805 |  | omezovací dělič napětí pro probouzení pomocí DS3231
X |  |  | T2 | 2N7002-13-F (N-FET) | SOT23 | spínací N-FET | https://www.tme.eu/cz/details/2n7002-dio/tranzistory-s-kanalem-n-smd/diotec-semiconductor/2n7002/ | /INT výstup RTC DS3231
X |  |  | T3 | PMV250EPEA (P-FET) | SOT23 | spínací P-FET | https://www.tme.eu/cz/details/pmv250epear/tranzistory-s-kanalem-p-smd/nexperia/ | přemostění hlavního vypínače (UDS alespoň 40V, ID alespoň 1A)
X |  |  | E - E' | drátová propojka |  |  |  | ovládání GATE T3
 |  | Konektor pro možnost připojení přídavných periférií
 |  | Pro pevnou verzi se předpokládá připojení periférií a čidel na kablík přímo do dírek pro konektor
X |  |  | EXT | IDC6 | 09185067323 HARTING | Konerktor 2x3 piny se zámkem 90° | https://www.tme.eu/cz/details/09185067323/konektory-idc/harting/ | konektor pro připojení vnějších periférií
 |  | Rozšíření pro měření napětí zdroje
 |  | Pevně umístěná verze je napájená po kabelu, takže se nepředpokládá, že by bylo třeba měřit napájecí napětí
 |  | Když se toto rozšíření nepoužije, zakázat ho i v programu v bloku #doc#02 ...... bool osazeno_uref = false;
X |  |  | DZ1 | BZV55C | SOD-80 | Zenerova dioda 1,8V 0,5W | https://www.tme.eu/cz/details/tzs4678-gs08/zenerovy-diody-smd/vishay/ | pevná reference pro testování napájecího napětí
X |  |  | D1 | 1N4148 | SOD-80 | univerzální dioda (50V / 50mA) | https://www.tme.eu/cz/details/ll4148-gs08/univerzalni-diody-smd/vishay/ | pro měření napětí zdroje
X |  |  | R6 | 27k | 0805 | R_SMD_0805 |  | pro měření napětí zdroje
X |  |  | R7 | 100k | 0805 | R_SMD_0805 |  | pro měření napětí zdroje
X |  |  | R8 | 8k2 | 0805 | R_SMD_0805 |  | pro měření napětí zdroje
X |  |  | R9 | 27k | 0805 | R_SMD_0805 |  | pro pevnou referenci 1,8V pro testování napájecího napětí
 |  | Rozšíření pro záznam GPS souřadnic a automatické seřízení času podle GPS signálu
 |  | U pevně umístěné verze se nepředpokládá, že by bylo nutné zaznamenávat souřadnice. Seřízení času je možné přes komunikaci RS485.
 |  | Při tomto rozšíření není možné osadit svorkovnice K1 a K2 (pro RS485). Signály A a B pro RS485 jsou pak v případě potřeby dostupné na desce SQM-GPS-6.
 |  | Když se toto rozšíření nepoužije, zakázat ho i v programu v bloku #doc#02 ...... bool osazeno_gps = false;
X |  |  | MOD6 | SQM-GPS-6 |  |  | http://sqm.astromik.org | Rozšiřující deska s vlastním procesorem a modulem NEO-6M (samostatná dokumentace)
X |  |  | C - C' | drátová propojka |  |  |  | připojení signálu SCL na rozšiřující desku SQM-GPS-6
X |  |  | D - D' | drátová propojka |  |  |  | připojení signálu SDA na rozšiřující desku SQM-GPS-6
X |  |  | R - R' | drátová propojka |  |  |  | připojení signálu DataReady na rozšiřující desku SQM-GPS-6
 |  | Rozšíření o komunikaci RS485
 |  | U pevně umístěné verze je předpoklad, že bude komunikovat dálkově, ale v případě, že se budou záznamy ukládat třeba na kartu, je komunikace i pro pevnou verzi zbytečná
 | X |  | IC1 | MAX3485 | SO08 | Převodník pro RS485 | https://www.tme.eu/cz/details/max3485eesa+/integr-obvody-interface-rs232-422-485/analog-devices-maxim-integrated/ | převodník pro komunikaci přes RS485 (3V logické úrovně)
 | X |  | K1 *1 | ARK500/2 | ARK500/2 | šroubovací svorkovnice 2 piny / 90° | https://www.tme.eu/cz/details/tb-5.0-p-2p/svorkovnice-do-plosnych-spoju/ninigi/ | alternativní svorkovnice pro napájení a komunikaci - pokud nebude osazena deska SQM-GPS-6
 | X |  | K2 *1 | ARK500/2 | ARK500/2 | šroubovací svorkovnice 2 piny / 90° | https://www.tme.eu/cz/details/tb-5.0-p-2p/svorkovnice-do-plosnych-spoju/ninigi/ | alternativní svorkovnice pro napájení a komunikaci - pokud nebude osazena deska SQM-GPS-6
 | X |  | R1 | 10R | 1206 | R_SMD_1206 |  | ochranný odpor pro linku RS485
 | X |  | R2 | 10R | 1206 | R_SMD_1206 |  | ochranný odpor pro linku RS485
 | X |  | R3 | 100R | 0805 | R_SMD_0805 |  | odpor pro zakončení sběrnice RS485
 | X |  | R4 | 22k | 0805 | R_SMD_0805 |  | Pull-Up pro sběrnici RS485 (signál A)
 | X |  | R5 | 22k | 0805 | R_SMD_0805 |  | Pull-Down pro sběrnici RS485 (signál B)
 | X |  | TR1 | SM6T15CA | SMBJ | Obousměrný transil 15V | https://www.tme.eu/cz/details/sm6t15ca/transil-diody-obousmerne-smd/stmicroelectronics/ | ochranný transil na lince RS485 (signál A)
 | X |  | TR2 | SM6T15CA | SMBJ | Obousměrný transil 15V | https://www.tme.eu/cz/details/sm6t15ca/transil-diody-obousmerne-smd/stmicroelectronics/ | ochranný transil na lince RS485 (signál B)
 |  |  | pozn. *1 | Při kombinaci rozšíření GPS a RS485 se nedají osadit svorkovnice.
 |  |  |  |  | Komunikační signály A a B ale zůstávají dostupné v pájecích bodech (dírkách) na desce SQM-GPS-6
 |  | Rozšíření o RGB signalizační LED
 |  | U ruční verze se provádí signalizace na displeji. Pro pevně nainstalovanou verzi je to jediný způsob, jak provozní stavy signalizovat.
 |  | Osazenou LED signalizaci je možné později vypnout jednoduchým přenastavením parametrů.
 | X |  | LED1 | WS2812D | LED_5-RGB | Programovatelná RGB LED | https://www.tme.eu/cz/details/ws2812d-f5/diody-led-tht-kulate/worldsemi/ | NeoPixelová RGB LED
 | X |  | R10 | 68R | 0805 | R_SMD_0805 |  | sériový odpor pro NeoPixelovou LED (požadováno podle datasheetu)
 |  | Ostatní doporučené součástky, které nejsou osazeny přímo na desce
X |  |  | CLIP-9V | BAT.CL.SN-1 |  |  | https://www.tme.eu/cz/details/bat.cl.sn-1/baterie-pouzdra-i-drzaky/ | klip pro připojení 9V baterie
X | X |  | TS_button | PB6133FBL-3 | DPDT ON - (ON) | libovolné dvojité tlačítko do panelu | https://www.tme.eu/cz/details/pb6133fbl-3/klavesnicove-spinace/highly-electric/ | dvojtlačítko pro záznam časové značky nebo pro vstup do servisních režimů - může být i OFF / (ON)
X |  |  | DC JACK | PC-G2.5 | 5,5 / 2,5 | DC napájecí konektor do panelu | https://www.tme.eu/cz/details/pc-g2.5/konektory-dc/ | napájecí konektor do panelu
 |  | Jen pro servis
 |  |  | PIN_TX |  | 1X01 |  |  | kolík pro možnost přímého odposlechu dat z GPS modulu NEO-6M na USB lince v PC
 |  |  | R19 | (1k8) | 0805 |  |  | prostor pro případný Pull-Up na SDA - neosazovat
 |  |  | R20 | (1k8) | 0805 |  |  | prostor pro případný Pull-Up na SCL - neosazovat

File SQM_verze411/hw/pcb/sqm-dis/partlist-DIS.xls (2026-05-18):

Osazení součástek pro desku SQM-DIS-3
 | jméno | hodnota | pouzdro | popis | odkaz | funkce
 | PCB | SQM-DIS-3 |  | plošný spoj (displejová část) | http://sqm.astromik.org | plošný spoj
 | IC1 | TM1637-SMD | SOIC127P1045X280-20N | ovladač pro sedmisegmentový displej | https://pajenicko.cz/komponenty/sedmisegmentovy-led-displej-se-4-znaky-radicem-tm1637 | vypájeno z nějakého levného displejového modulu, protože jsem ho jinde nemohl sehnat
 | DIS10000x | KW1-391ASA | HDSP-E | 7-seg. zobrazovací jednotka (červená, spol. anoda) | https://www.tme.eu/cz/details/kw1-391asa/jednomistne-led-displeje/luckylight/ | zobrazovací jednotka pozice 10000
 | DIS1000x | KW1-391ASA | HDSP-E | 7-seg. zobrazovací jednotka (červená, spol. anoda) | https://www.tme.eu/cz/details/kw1-391asa/jednomistne-led-displeje/luckylight/ | zobrazovací jednotka pozice 1000
 | DIS100x | KW1-391ASA | HDSP-E | 7-seg. zobrazovací jednotka (červená, spol. anoda) | https://www.tme.eu/cz/details/kw1-391asa/jednomistne-led-displeje/luckylight/ | zobrazovací jednotka pozice 100
 | DIS10x | KW1-391ASA | HDSP-E | 7-seg. zobrazovací jednotka (červená, spol. anoda) | https://www.tme.eu/cz/details/kw1-391asa/jednomistne-led-displeje/luckylight/ | zobrazovací jednotka pozice 10
 | DIS1x | KW1-391ASA | HDSP-E | 7-seg. zobrazovací jednotka (červená, spol. anoda) | https://www.tme.eu/cz/details/kw1-391asa/jednomistne-led-displeje/luckylight/ | zobrazovací jednotka pozice 1
 | R1 | 10k | R_SMD_0805 |  |  | Pull-Up pro DIO pin komunikace s displejem
 | R2 | 10k | R_SMD_0805 |  |  | Pull-Up pro CLK pin komunikace s displejem
 | C1 | 100u / 10V | elektrolyt / tantal - rozteč 2,5mm |  |  | kondenzátor na napájení
 | C2 | 100n | SMD 0805 |  |  | kondenzátor na napájení
 | C3 | 100n | SMD 0805 |  |  | kondenzátor na napájení
 | C4 | 100p | SMD 0805 |  |  | pro komunikační pin DIO
 | C5 | 100p | SMD 0805 |  |  | pro komunikační pin CLK
 | JP1-M | 1x4 | SL 5 172 4G | Jednořadá delší kolíková lišta - 4 piny | https://www.tme.eu/cz/details/sl5.172.4g/konektory-hrebinky/fischer-elektronik/sl-5-172-4g/ | propojení desky DIS a BAS (komunikační signály)
 | JP2-M | 1x4 | SL 5 172 4G | Jednořadá delší kolíková lišta - 4 piny | https://www.tme.eu/cz/details/sl5.172.4g/konektory-hrebinky/fischer-elektronik/sl-5-172-4g/ | propojení desky DIS a BAS (signály tlačítek)

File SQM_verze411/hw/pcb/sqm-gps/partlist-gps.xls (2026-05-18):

Osazení součástek pro desku SQM-GPS-6
 | jméno | hodnota | pouzdro | popis | odkaz | funkce
 | PCB | SQM-GPS-6 |  |  | http://sqm.astromik.org | plošný spoj
 | MOD1 | NEO-6M |  | modul GPS s anténou | https://www.aliexpress.com/item/1005006038060521.html | modul pro příjem GPS
 | U1 | ATMEGA328P-AU | QFP80P900X900X120-32N | procesor pro zpracování GPS dat | https://www.tme.eu/cz/details/atmega328p-au/rodina-avr-8-bitu/microchip-technology/ | procesor pro zpracování GPS dat
 | T1 | BSS138 | SOT23 |  | https://www.tme.eu/cz/details/bss138lt1g/tranzistory-s-kanalem-n-smd/onsemi/ | odpojování I2C sběrnice
 | T2 | BSS138 | SOT23 |  | https://www.tme.eu/cz/details/bss138lt1g/tranzistory-s-kanalem-n-smd/onsemi/ | odpojování I2C sběrnice
 | LED1 | (L-7104LID) | 3mm | nějaká méně svítivá červená LED | https://www.tme.eu/cz/details/l-7104lid/led-diody-tht-3mm/kingbright-electronic/ | signalizace přepínání přijatých NMEA zpráv
 | LED2 | (L-7104LID) | 3mm | nějaká méně svítivá červená LED | https://www.tme.eu/cz/details/l-7104lid/led-diody-tht-3mm/kingbright-electronic/ | signalizace nepřítomnosti časové značky v GPS signálu
 | LED3 | (L-7104LID) | 3mm | nějaká méně svítivá červená LED | https://www.tme.eu/cz/details/l-7104lid/led-diody-tht-3mm/kingbright-electronic/ | signalizace nepřítomnosti polohových souřadnic v GPS signálu
 | Q1 | 4MHZ | HC-49U | krystal (max. výška 4mm) | https://www.tme.eu/cz/details/4.00m-hc49-s/krystalove-rezonatory-tht/yic/ | krystal pro procesor ATmega (kvůli sníženému napájení podtaktováno na 4MHz)
 |  | FIX-QW-1 | FIX-QW-1 | izolační podložka pod krystal | https://www.tme.eu/cz/details/fix-qw-1/distancni-sloupky-plastove/fix-fasten/ | podložka pod krystal sice není povinná, ale doporučuji ji osadit
 | C1 | 10u | 1206 |  |  | kondenzátor na napájení procesoru
 | C2 | 100n | 0805 |  |  | kondenzátor na napájení procesoru
 | C3 | 18p | 0805 |  |  | kondenzátor ke krystalu
 | C4 | 18p | 0805 |  |  | kondenzátor ke krystalu
 | C5 | 100n | 0805 |  |  | kondenzátor na vstupu referenčního napětí (nepoužívá se, ale je vyžadován podle datasheetu)
 | R1 | 1k5 | 0805 |  |  | sériový odpor k LED1
 | R2 | 1k5 | 0805 |  |  | sériový odpor k LED2
 | R3 | 1k5 | 0805 |  |  | sériový odpor k LED3
 | R4 | 47k | 0805 |  |  | Pull-Up pro resetovací pin procesoru
 | R5 | 47k | 0805 |  |  | Pull-Down pro signál DATA_READY
 | R6 | 10k | 0805 |  |  | Pull-Down pro odpojování I2C směrnice při vypnutí GPS části
 | SW1 | SS-12D06L5 | SLIDE_SW | posuvný přepínač, 2 polohy / 90° | https://www.laskarduino.cz/posuvny-prepinac-3a-250vac-ss-12d06l5/ | hlavní vypínač pro GPS část
 | JPx - M |  | 10x1 (90°) (rozdělit na 9+1) | jednořadá kolíková lišta 90° | https://www.tme.eu/cz/details/zl211-40kg/konektory-hrebinky/connfly/ds1022-1-40rdf11-b/ | kolíková lišta pro propojení na desku SQM-BAS-7
 | JPy - M |  | 6x1 (rozdělit na 3+2+1) | provizorní programovací kolíky | https://www.tme.eu/cz/details/zl211-40kg/konektory-hrebinky/connfly/ds1022-1-40rdf11-b/ | přímé nebo 90° piny se po naprogramování procesoru odstraní
 | GPS_OUT |  | 1X1 (90°) | nepovinný kolík 90° pro odposlech GPS | https://www.tme.eu/cz/details/zl211-40kg/konektory-hrebinky/connfly/ds1022-1-40rdf11-b/ | nepovinný pin pro servisní odposlech GPS dat

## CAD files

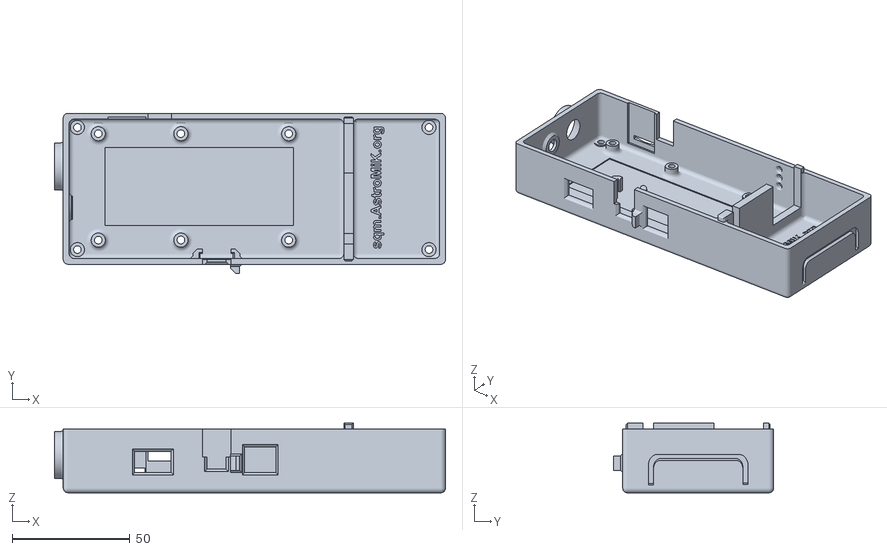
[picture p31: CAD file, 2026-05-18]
SQM_verze411/hw/krabicka/sqm-bot.stl
165.7 x 68.0 x 29.5

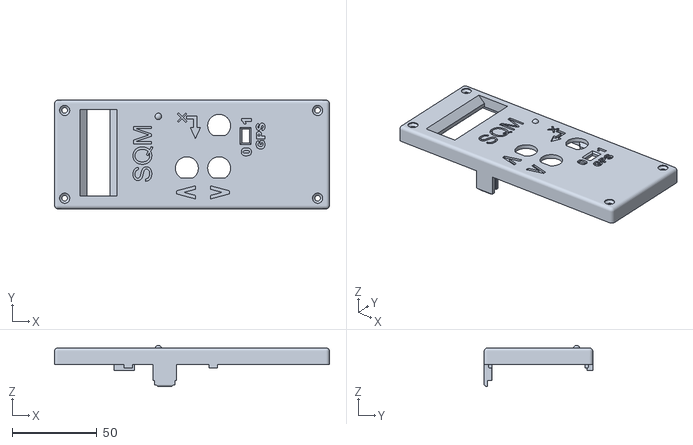
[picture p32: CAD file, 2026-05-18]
SQM_verze411/hw/krabicka/sqm-top.stl
162.0 x 64.0 x 24.3

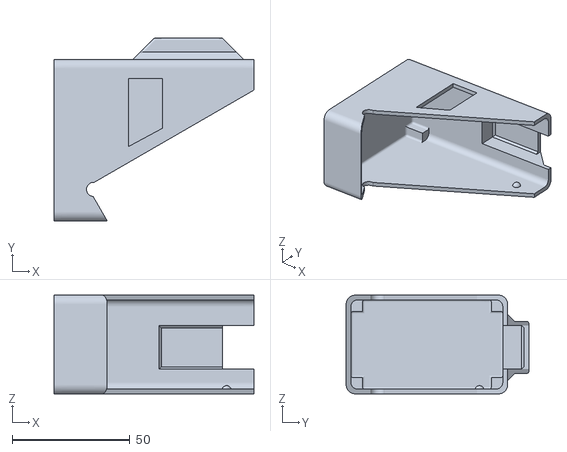
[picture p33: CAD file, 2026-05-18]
SQM_verze411/hw/krabicka/sqm-cov.stl
85.0 x 77.7 x 42.0

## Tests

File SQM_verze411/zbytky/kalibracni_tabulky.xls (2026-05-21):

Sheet: SVĚTLO
 | Kalibrační tabulka světla
 | Datum poslední kalibrace:
 | Referenční SQM:
 | ID kalibrovaného SQM: |  |  |  |  |  |  |  |  | seřazeno pro graf
 | položka | změřená | správná | poznámka | ignoruj nuly | shoda |  |  |  | pořadi | seřazené X | odpovídající Y
 |  | bez korekcí přímo z čidla | k zobrazení
 | 1 |  |  |  | 101 | 1 | 01 | 00000 | 00000 | 1 | 0 | 0
 | 2 |  |  |  | 102 | 1 | 02 | 00000 | 00000 | 2 | 24 | 24
 | 3 |  |  |  | 103 | 1 | 03 | 00000 | 00000 | 3 | #NUM! | #NUM!
 | 4 |  |  |  | 104 | 1 | 04 | 00000 | 00000 | 4 | #NUM! | #NUM!
 | 5 |  |  |  | 105 | 1 | 05 | 00000 | 00000 | 5 | #NUM! | #NUM!
 | 6 |  |  |  | 106 | 1 | 06 | 00000 | 00000 | 6 | #NUM! | #NUM!
 | 7 |  |  |  | 107 | 1 | 07 | 00000 | 00000 | 7 | #NUM! | #NUM!
 | 8 |  |  |  | 108 | 1 | 08 | 00000 | 00000 | 8 | #NUM! | #NUM!
 | 9 |  |  |  | 109 | 1 | 09 | 00000 | 00000 | 9 | #NUM! | #NUM!
 | 10 |  |  |  | 110 | 1 | 10 | 00000 | 00000 | 10 | #NUM! | #NUM!
 | 11 |  |  |  | 111 | 1 | 11 | 00000 | 00000 | 11 | #NUM! | #NUM!
 | 12 |  |  |  | 112 | 1 | 12 | 00000 | 00000 | 12 | #NUM! | #NUM!
 | 13 |  |  |  | 113 | 1 | 13 | 00000 | 00000 | 13 | #NUM! | #NUM!
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

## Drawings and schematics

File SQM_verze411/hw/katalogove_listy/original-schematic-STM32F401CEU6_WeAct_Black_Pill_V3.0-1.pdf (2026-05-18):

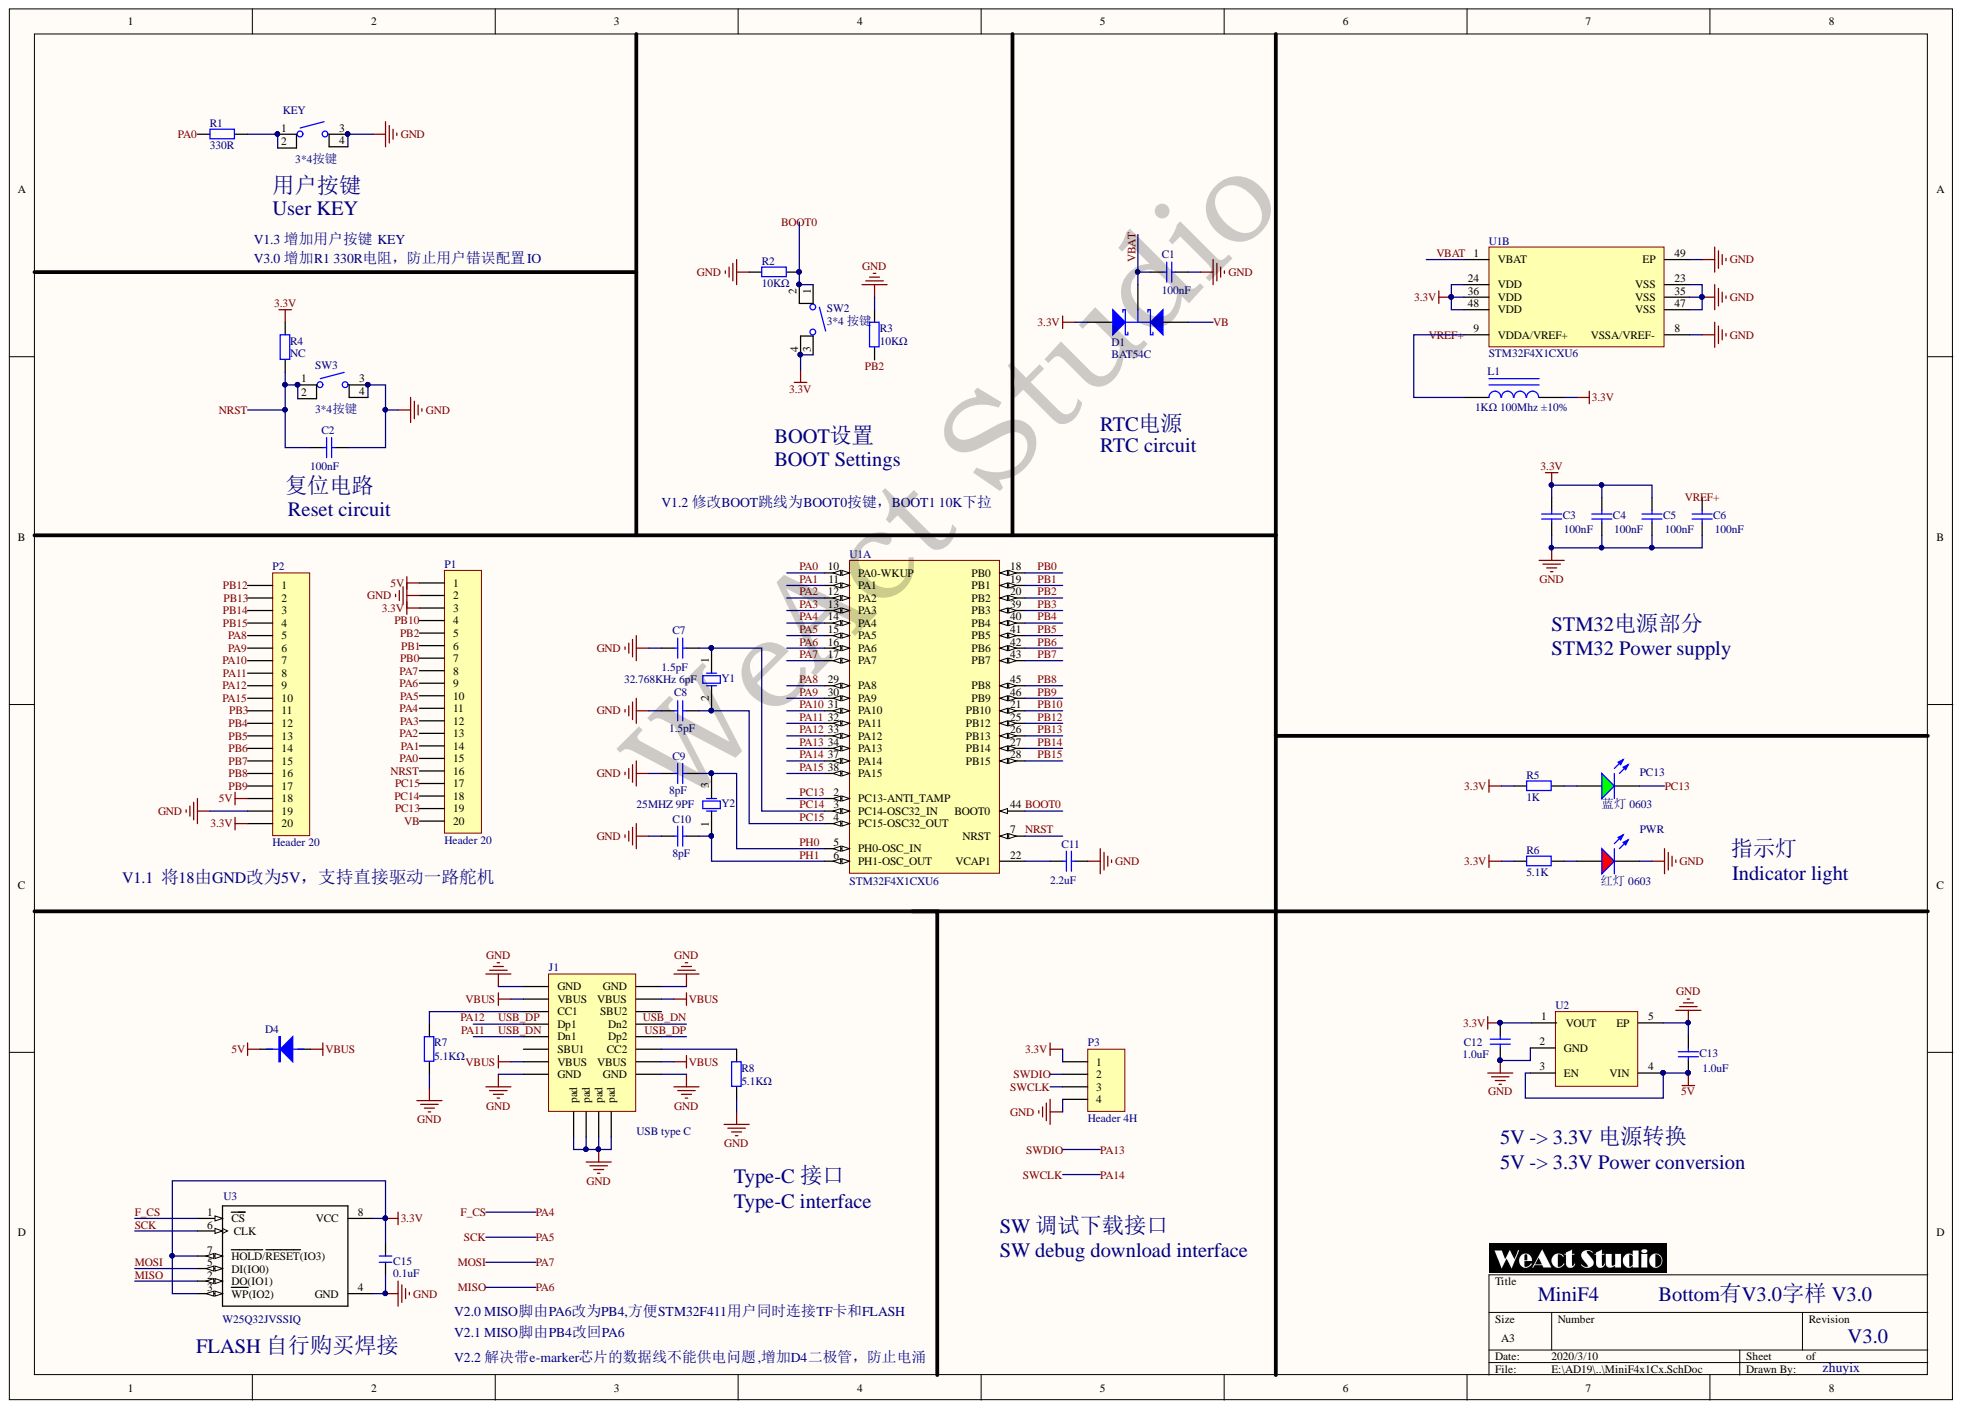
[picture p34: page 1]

PH1-OSC_OUT 6

SW 调试下载接口
SW debug download interface

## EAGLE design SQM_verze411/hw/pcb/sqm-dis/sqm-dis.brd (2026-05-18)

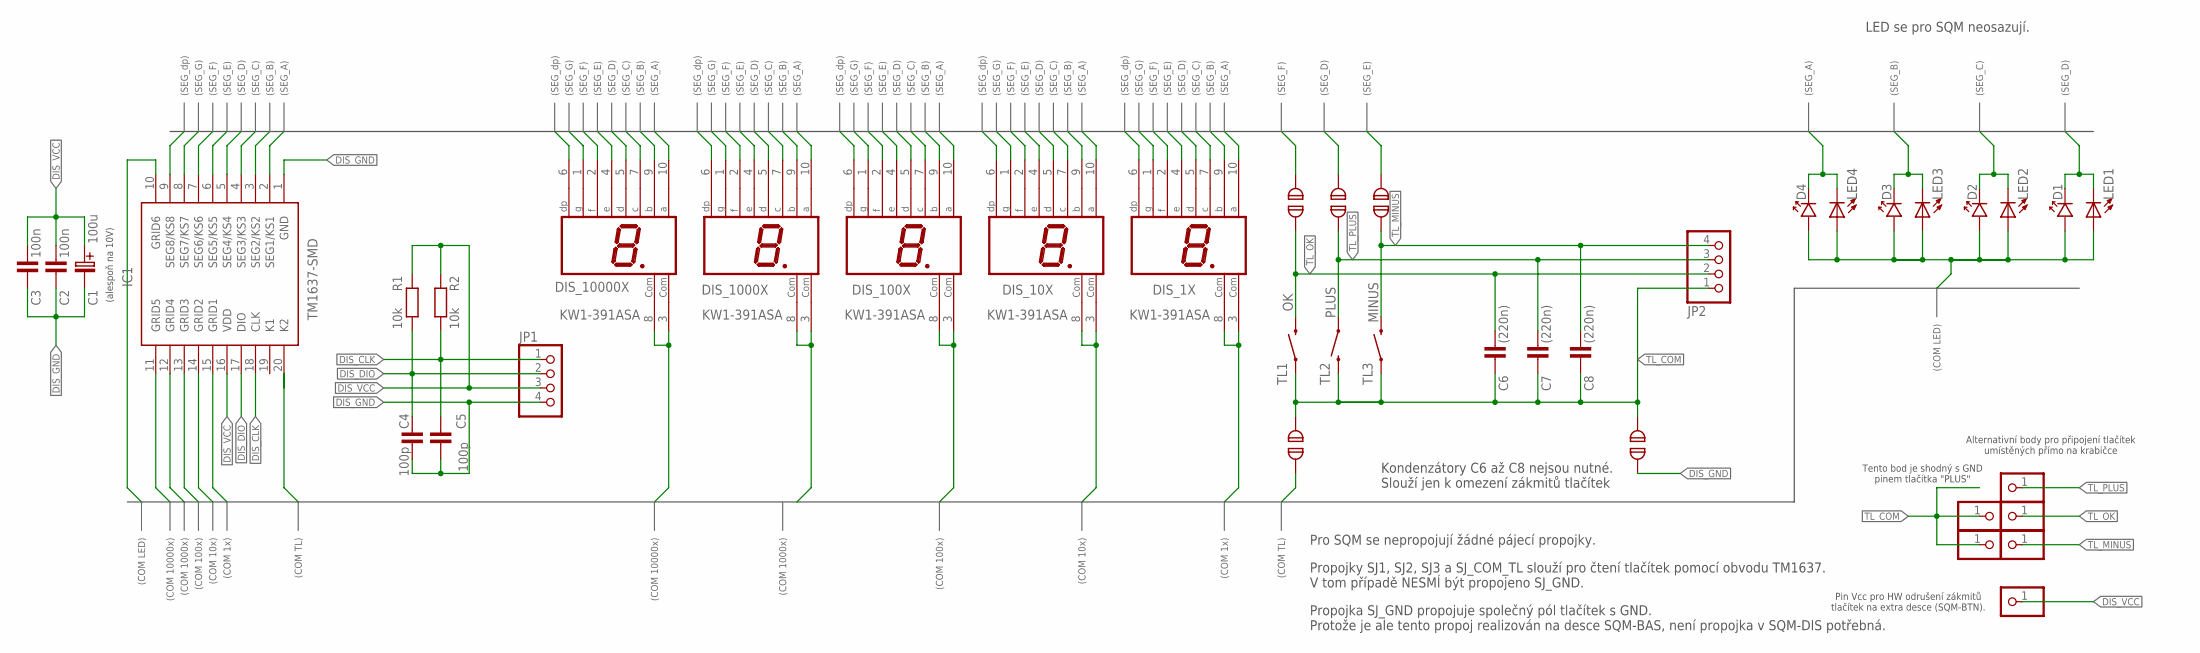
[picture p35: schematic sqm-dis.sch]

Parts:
C1: 100u; C-EL_2,5
C2, C3: 100n; 0805
C4, C5: 100p; 0805
C6, C7, C8: (220n); 0805
D1, D2, D3, D4: LED_3
DIS_1X, DIS_10X, DIS_100X, DIS_1000X, DIS_10000X: KW1-391ASA; HDSP-E
IC1: TM1637-SMD; SOIC127P1045X280-20N
JP1, JP2: PINHD-1X4; 1X04
JP3, JP4, JP5, JP6, JP7, JP8: PINHD-1X1; 1X01
LED1, LED2, LED3, LED4: LEDCHIP-LED0805; CHIP-LED0805
R1, R2: 10k; 0805
SJ1, SJ2, SJ3: SJ; SJ_2S-NO
SJ_COM_TL: SJ; SJ_2S-NO
SJ_GND: SJ; SJ_2S-NO
TL1: OK; TACTILE_SWITCH_PTH_6.0MM
TL2: PLUS; TACTILE_SWITCH_PTH_6.0MM
TL3: MINUS; TACTILE_SWITCH_PTH_6.0MM

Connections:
COM_BUS0: DIS_1X.3 (COM), DIS_1X.8 (COM), IC1.15 (GRID1)
COM_BUS1: DIS_10X.3 (COM), DIS_10X.8 (COM), IC1.14 (GRID2)
COM_BUS2: DIS_100X.3 (COM), DIS_100X.8 (COM), IC1.13 (GRID3)
COM_BUS3: DIS_1000X.3 (COM), DIS_1000X.8 (COM), IC1.12 (GRID4)
COM_BUS4: DIS_10000X.3 (COM), DIS_10000X.8 (COM), IC1.11 (GRID5)
COM_BUS5: IC1.20 (K2), SJ_COM_TL.1
COM_BUS6: D1.A, D2.A, D3.A, D4.A, IC1.10 (GRID6), LED1.A, LED2.A, LED3.A, LED4.A
DIS_CLK: C5.2, IC1.18 (CLK), JP1.1, R2.1
DIS_DIO: C4.2, IC1.17 (DIO), JP1.2, R1.1
DIS_GND: C1.C- (C_EL-), C2.1, C3.1, C4.1, C5.1, IC1.1 (GND), JP1.4, SJ_GND.1
DIS_VCC: C1.C+ (C_EL+), C2.2, C3.2, IC1.16 (VDD), JP1.3, JP3.1, R1.2, R2.2
SEG_BUS0: D4.K, DIS_1X.10 (A), DIS_10X.10 (A), DIS_100X.10 (A), DIS_1000X.10 (A), DIS_10000X.10 (A), IC1.2 (SEG1/KS1), LED4.C
SEG_BUS1: D3.K, DIS_1X.9 (B), DIS_10X.9 (B), DIS_100X.9 (B), DIS_1000X.9 (B), DIS_10000X.9 (B), IC1.3 (SEG2/KS2), LED3.C
SEG_BUS2: D2.K, DIS_1X.7 (C), DIS_10X.7 (C), DIS_100X.7 (C), DIS_1000X.7 (C), DIS_10000X.7 (C), IC1.4 (SEG3/KS3), LED2.C
SEG_BUS3: D1.K, DIS_1X.5 (D), DIS_10X.5 (D), DIS_100X.5 (D), DIS_1000X.5 (D), DIS_10000X.5 (D), IC1.5 (SEG4/KS4), LED1.C, SJ2.2
SEG_BUS4: DIS_1X.4 (E), DIS_10X.4 (E), DIS_100X.4 (E), DIS_1000X.4 (E), DIS_10000X.4 (E), IC1.6 (SEG5/KS5), SJ3.2
SEG_BUS5: DIS_1X.2 (F), DIS_10X.2 (F), DIS_100X.2 (F), DIS_1000X.2 (F), DIS_10000X.2 (F), IC1.7 (SEG6/KS6), SJ1.2
SEG_BUS6: DIS_1X.1 (G), DIS_10X.1 (G), DIS_100X.1 (G), DIS_1000X.1 (G), DIS_10000X.1 (G), IC1.8 (SEG7/KS7)
SEG_BUS7: DIS_1X.6 (DP), DIS_10X.6 (DP), DIS_100X.6 (DP), DIS_1000X.6 (DP), DIS_10000X.6 (DP), IC1.9 (SEG8/KS8)
TL_COM: C6.1, C7.1, C8.1, JP2.1, JP7.1, JP8.1, SJ_COM_TL.2, SJ_GND.2, TL1.1, TL2.3 (2), TL3.1
TL_MINUS: C8.2, JP2.4, JP6.1, SJ3.1, TL3.3 (2)
TL_OK: C6.2, JP2.2, JP4.1, SJ1.1, TL1.3 (2)
TL_PLUS: C7.2, JP2.3, JP5.1, SJ2.1, TL2.1

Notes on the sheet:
(SEG_A)
(SEG_B)
(SEG_C)
(SEG_D)
(SEG_E)
(SEG_F)
(SEG_G)
(SEG_dp)
(COM 10000x)
(COM 1000x)
(COM 100x)
(COM 10x)
(COM 1x)
(COM TL)
(COM LED)
Alternativní body pro připojení tlačítek umístěných přímo na krabičce
Tento bod je shodný s GND pinem tlačítka "PLUS"
(alespoň na 10V)
Pro SQM se nepropojují žádné pájecí propojky.
Propojky SJ1, SJ2, SJ3 a SJ_COM_TL slouží pro čtení tlačítek pomocí obvodu TM1637. V tom případě NESMÍ být propojeno SJ_GND.
Propojka SJ_GND propojuje společný pól tlačítek s GND. Protože je ale tento propoj realizován na desce SQM-BAS, není propojka v SQM-DIS potřebná.
Kondenzátory C6 až C8 nejsou nutné. Slouží jen k omezení zákmitů tlačítek
LED se pro SQM neosazují.
Pin Vcc pro HW odrušení zákmitů tlačítek na extra desce (SQM-BTN).

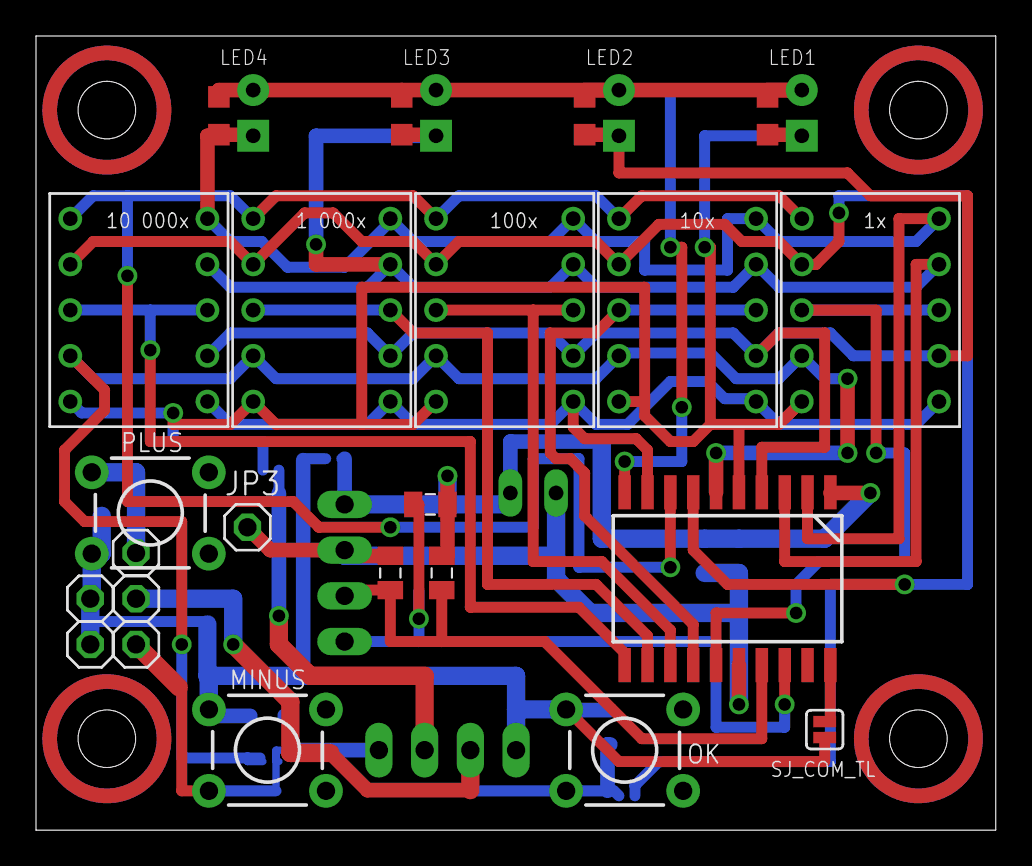
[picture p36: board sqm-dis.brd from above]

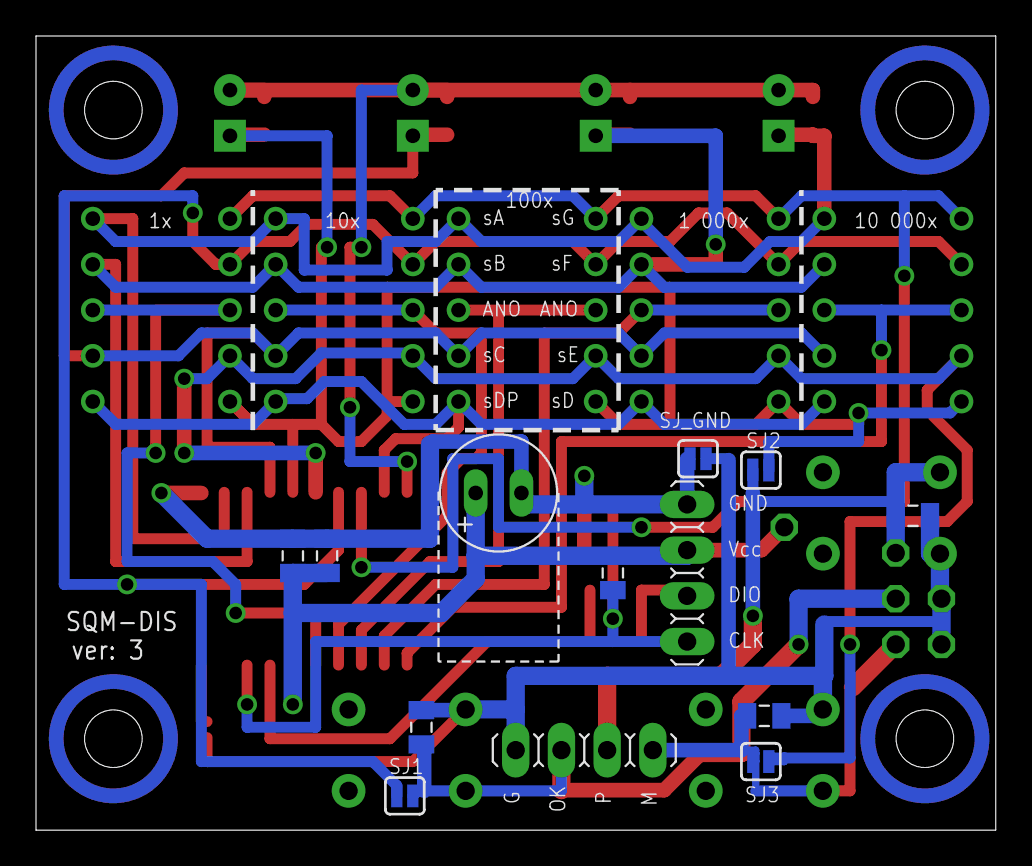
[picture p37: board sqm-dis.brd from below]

Board: 2 copper layers, 53.3 x 44.1 mm, 40 parts (13 on the bottom side), 23 nets.

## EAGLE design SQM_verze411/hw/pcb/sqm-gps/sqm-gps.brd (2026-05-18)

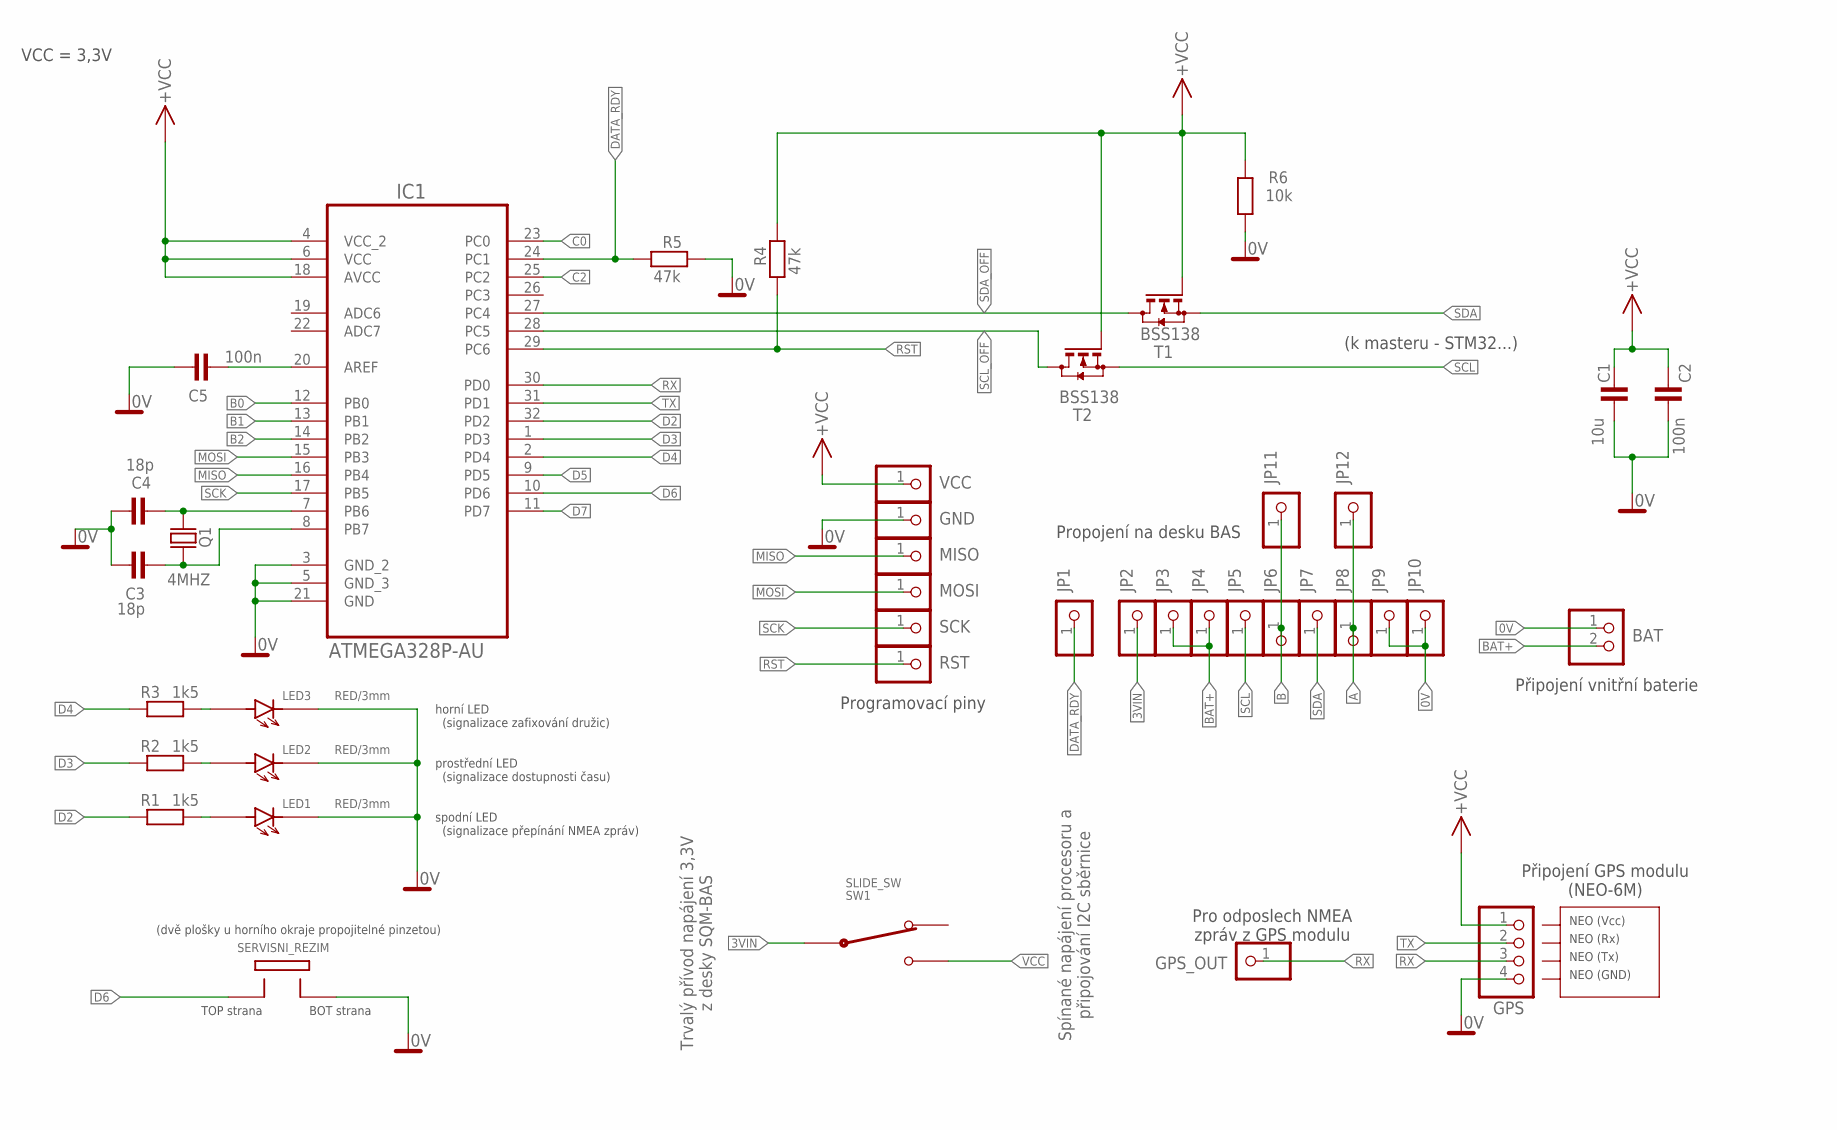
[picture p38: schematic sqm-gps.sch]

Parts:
BAT: PINHD-1X2; 1X02
C1: 10u; 1206
C2, C5: 100n; 0805
C3, C4: 18p; 0805
GND: PINHD-1X1; 1X01
GPS: PINHD-1X4; 1X04
GPS_OUT: PINHD-1X1; 1X01
IC1: ATMEGA328P-AU; QFP80P900X900X120-32N
JP1, JP2, JP3, JP4, JP5, JP6, JP7, JP8, JP9, JP10, JP11, JP12: PINHD-1X1; 1X01
LED1, LED2, LED3: RED/3mm; LED3MM_BOK
MISO: PINHD-1X1; 1X01
MOSI: PINHD-1X1; 1X01
Q1: 4MHZ; HC-49U
R1, R2, R3: 1k5; 0805
R4, R5: 47k; 0805
R6: 10k; 0805
RST: PINHD-1X1; 1X01
SCK: PINHD-1X1; 1X01
SERVISNI_REZIM: TOP_BOT_PIN
SW1: SLIDE_SW
T1, T2: BSS138; SOT23
VCC: PINHD-1X1; 1X01

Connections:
0V: BAT.1, C1.2, C2.1, C3.2, C4.1, C5.2, GND.1, GPS.4, IC1.3 (GND_2), IC1.5 (GND_3), IC1.21 (GND), JP9.1, JP10.1, LED1.K, LED2.K, LED3.K, R5.2, R6.1, SERVISNI_REZIM.P2
3VIN: JP2.1, SW1.PIN_COM
A: JP8.1, JP12.1
AREF: C5.1, IC1.20 (AREF)
B: JP6.1, JP11.1
B0: IC1.12 (PB0)
B1: IC1.13 (PB1)
B2: IC1.14 (PB2)
B6: C4.2, IC1.7 (PB6), Q1.2
B7: C3.1, IC1.8 (PB7), Q1.1
BAT+: BAT.2, JP3.1, JP4.1
C0: IC1.23 (PC0)
C2: IC1.25 (PC2)
D2: IC1.32 (PD2), R1.1
D3: IC1.1 (PD3), R2.1
D4: IC1.2 (PD4), R3.1
D5: IC1.9 (PD5)
D6: IC1.10 (PD6), SERVISNI_REZIM.P1
D7: IC1.11 (PD7)
DATA_RDY: IC1.24 (PC1), JP1.1, R5.1
LED1_A1: LED1.A, R1.2
LED2_A1: LED2.A, R2.2
LED3_A1: LED3.A, R3.2
MISO: IC1.16 (PB4), MISO.1
MOSI: IC1.15 (PB3), MOSI.1
RST: IC1.29 (PC6), R4.1, RST.1
RX: GPS.3, GPS_OUT.1, IC1.30 (PD0)
SCK: IC1.17 (PB5), SCK.1
SCL: JP5.1, T2.2 (S)
SCL_OFF: IC1.28 (PC5), T2.3 (D)
SDA: JP7.1, T1.2 (S)
SDA_OFF: IC1.27 (PC4), T1.3 (D)
TX: GPS.2, IC1.31 (PD1)
VCC: C1.1, C2.2, GPS.1, IC1.4 (VCC_2), IC1.6 (VCC), IC1.18 (AVCC), R4.2, R6.2, SW1.PIN_2, T1.1 (G), T2.1 (G), VCC.1

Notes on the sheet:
Propojení na desku BAS
Připojení vnitřní baterie
Programovací piny
Připojení GPS modulu (NEO-6M)
Trvalý přívod napájení 3,3V z desky SQM-BAS
Spínané napájení procesoru a připojování I2C sběrnice
(k masteru - STM32...)
spodní LED (signalizace přepínání NMEA zpráv)
prostřední LED (signalizace dostupnosti času)
horní LED (signalizace zafixování družic)
TOP strana
BOT strana
VCC = 3,3V
(dvě plošky u horního okraje propojitelné pinzetou)
NEO (Rx)
NEO (Tx)
NEO (GND)
NEO (Vcc)
Pro odposlech NMEA zpráv z GPS modulu

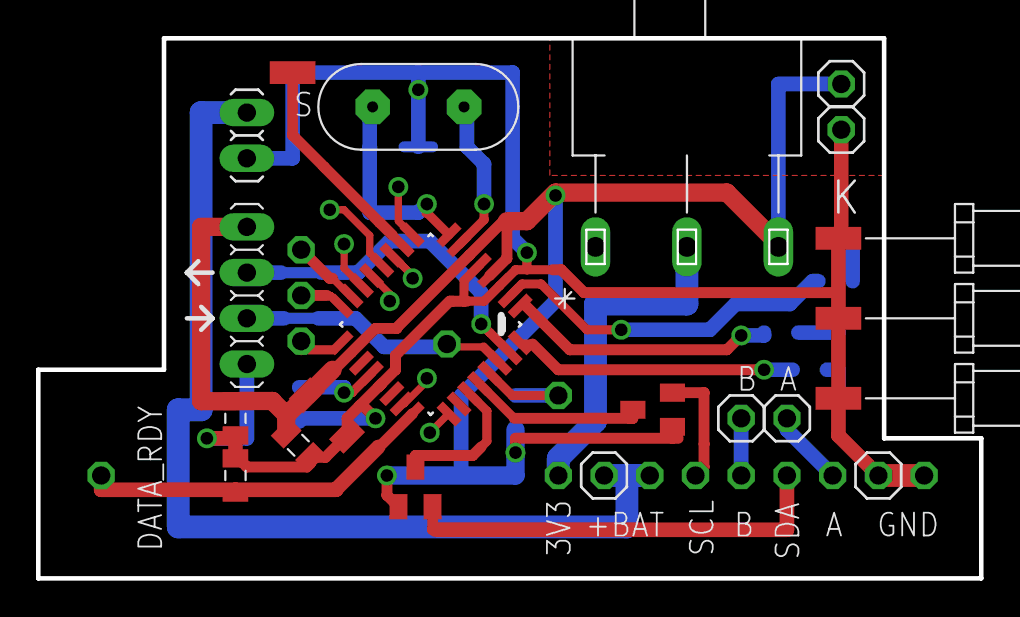
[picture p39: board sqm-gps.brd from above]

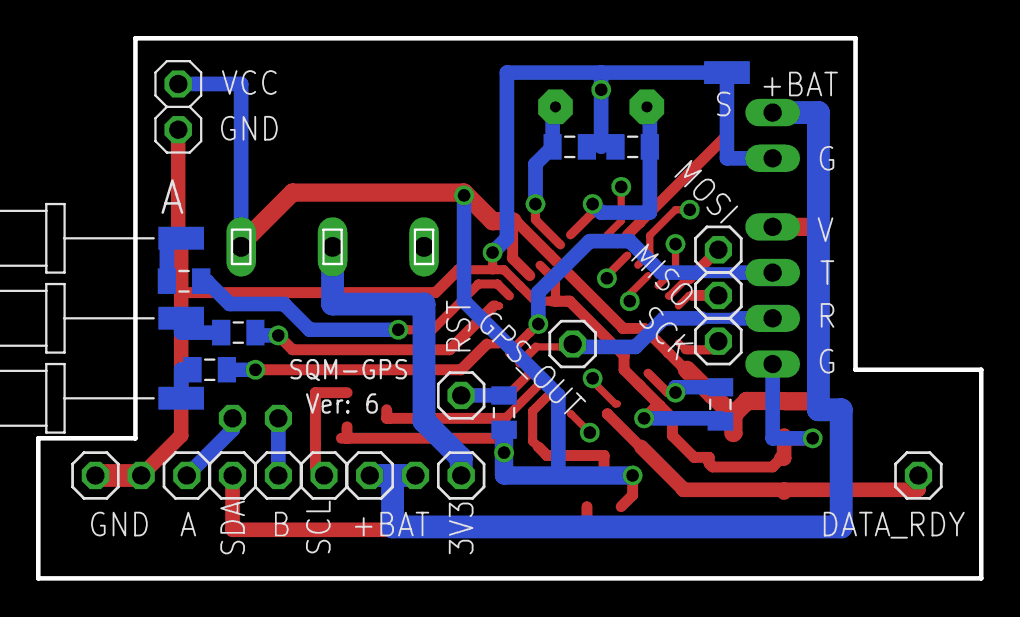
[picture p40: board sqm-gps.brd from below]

Board: 2 copper layers, 52.4 x 30.0 mm, 41 parts (20 on the bottom side), 27 nets.

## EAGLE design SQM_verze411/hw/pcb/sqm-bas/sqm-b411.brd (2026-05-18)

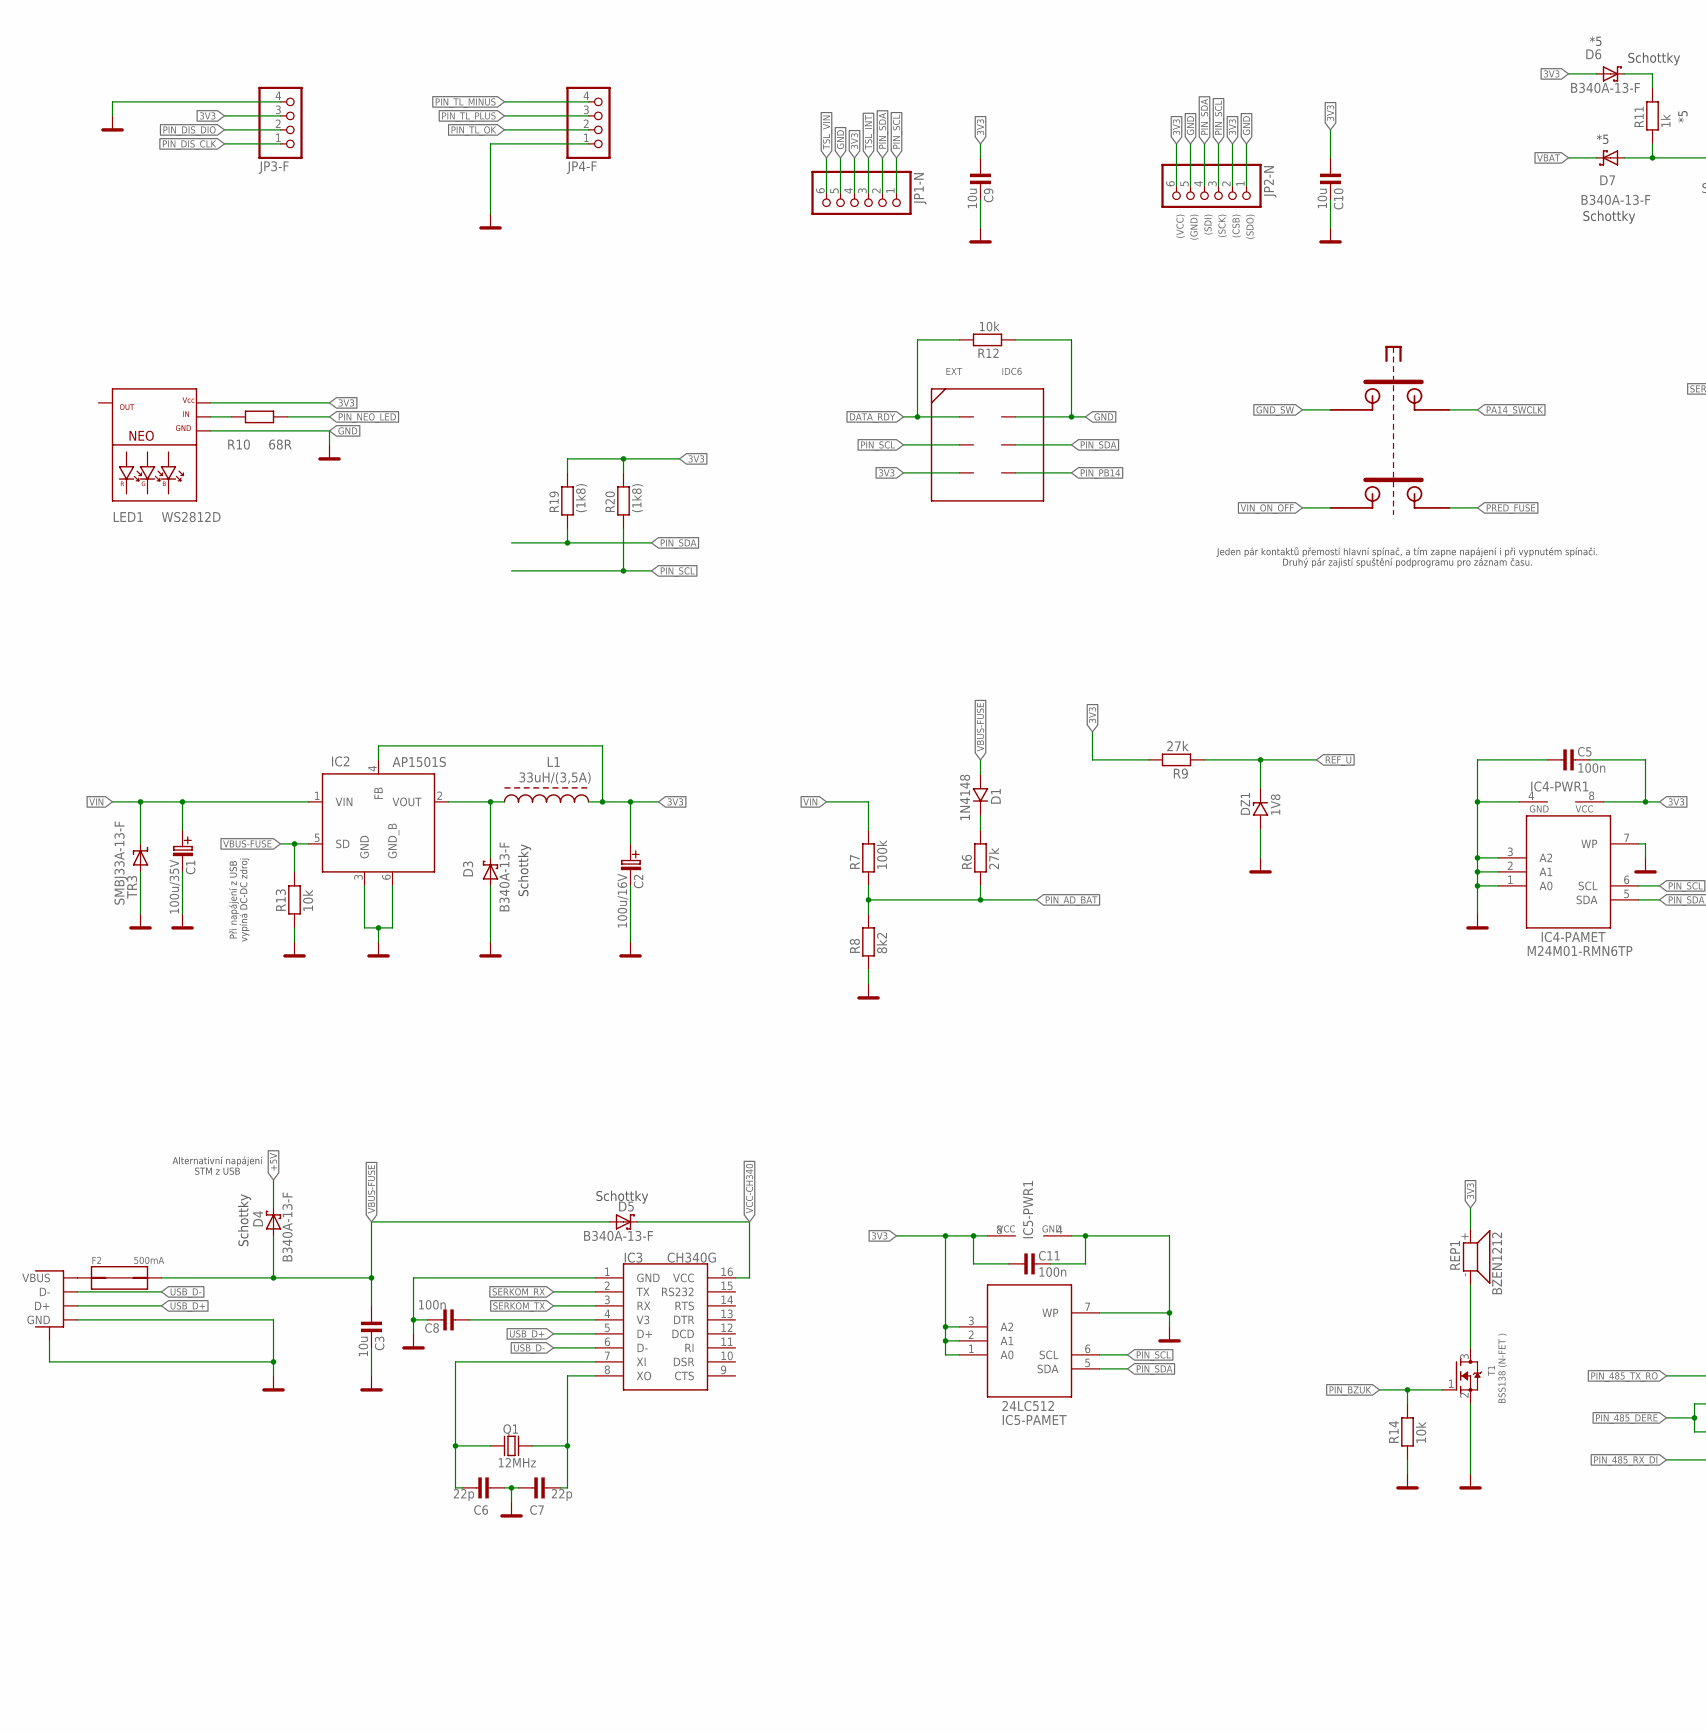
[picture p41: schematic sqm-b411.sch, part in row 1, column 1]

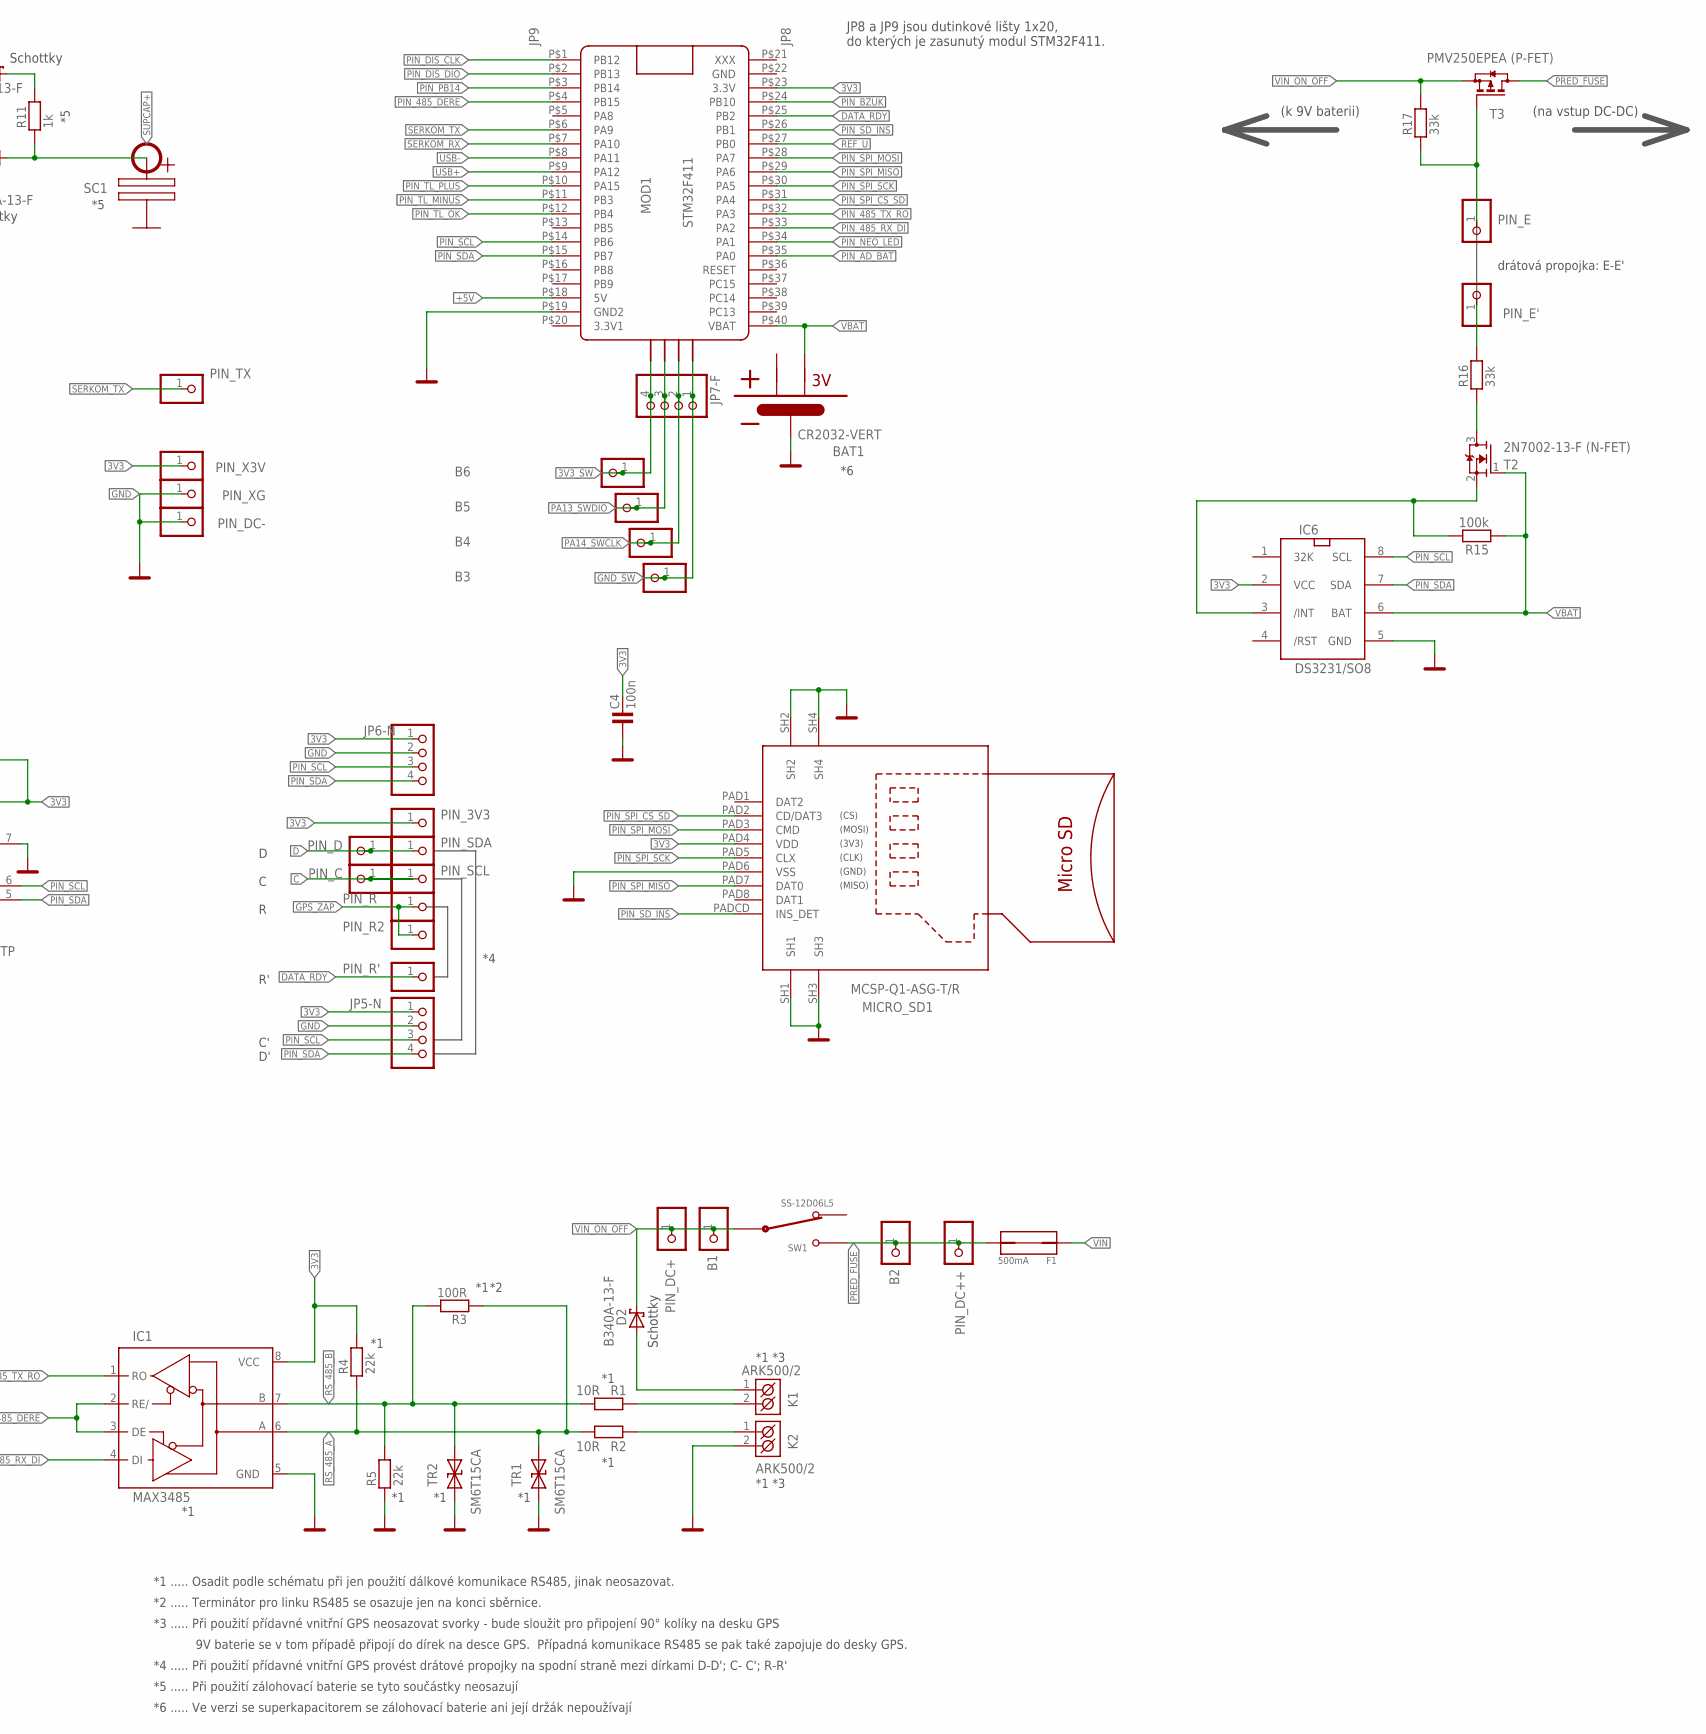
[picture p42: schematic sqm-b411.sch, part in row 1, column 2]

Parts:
B1, B2, B3, B4, B5, B6: PINHD-1X1; 1X01
BAT1: CR2032-VERT
C1: 100u/35V; C-EL_3,5
C2: 100u/16V; C-EL_3,5
C3, C9, C10: 10u; 0805
C4, C5, C8, C11: 100n; 0805
C6, C7: 22p; 0805
D1: 1N4148; SOD-80
D2, D3, D4, D5, D6, D7: B340A-13-F; SMB
DZ1: 1V8; SOD-80
EXT: IDC6
F1, F2: 500mA; FUSE1812
IC1: MAX3485; SO08
IC2: AP1501S; TO263-5
IC3: CH340G; SOIC16
IC4: M24M01-RMN6TP; SO8
IC5: 24LC512; SO8
IC6: DS3231/SO8; SO8
JP1-N, JP2-N: PINHD-1X6; 1X06
JP3-F, JP4-F, JP5-N, JP6-N, JP7-F: PINHD-1X4; 1X04
K1, K2: ARK500/2
L1: 33uH/(3,5A); SMD_INDUCTOR
LED1: WS2812D; LED_5-RGB
MICRO_SD1: MCSP-Q1-ASG-T/R; MICRO_SD
MOD1: STM32F411; BLACK411_PILL
PIN_3V3: PINHD-1X1; 1X01
PIN_C: PINHD-1X1; 1X01
PIN_D: PINHD-1X1; 1X01
PIN_DC+: PINHD-1X1; 1X01
PIN_DC++: PINHD-1X1; 1X01
PIN_DC-: PINHD-1X1; 1X01
PIN_E: PINHD-1X1; 1X01
PIN_E': PINHD-1X1; 1X01
PIN_R, PIN_R2: PINHD-1X1; 1X01
PIN_R': PINHD-1X1; 1X01
PIN_SCL: PINHD-1X1; 1X01
PIN_SDA: PINHD-1X1; 1X01
PIN_TX: PINHD-1X1; 1X01
PIN_X3V: PINHD-1X1; 1X01
PIN_XG: PINHD-1X1; 1X01
Q1: 12MHz; HC-49U
R1, R2: 10R; 1206
R3: 100R; 0805
R4, R5: 22k; 0805
R6, R9: 27k; 0805
R7, R15: 100k; 0805
R8: 8k2; 0805
R10: 68R; 0805
R11: 1k; 0805
R12, R13, R14: 10k; 0805
R16, R17: 33k; 0805
R19, R20: (1k8); 0805
REP1: BZEN1212; KPE242
SUPCAP-DIRA: DIRA
SW1: SS-12D06L5; SLIDE_SW
T1: BSS138 (N-FET ); SOT23
T2: 2N7002-13-F (N-FET); SOT23
T3: PMV250EPEA (P-FET); SOT23
TR1, TR2: SM6T15CA; SMBJ
TR3: SMBJ33A-13-F; SMBJ
USB1: USBPTH; USB-B-PTH

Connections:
3V3: C2.C+ (C_EL+), C4.2, C5.2, C9.1, C10.1, C11.1, D6.A, EXT.P5 (PIN5), IC1.8 (VCC), IC2.4 (FB), IC4.8 (VCC), IC5.1 (A0), IC5.2 (A1), IC5.3 (A2), IC5.8 (VCC), IC6.2 (VCC), JP1-N.4, JP2-N.2, JP2-N.6, JP3-F.3, JP5-N.1, JP6-N.1, L1.P$2, LED1.V (VCC), MICRO_SD1.PAD4 (VDD), MOD1.P$23 (3.3V), PIN_3V3.1, PIN_X3V.1, R4.2, R9.2, R19.2, R20.2, REP1.+
3V3_SW: B6.1, JP7-F.4
+5V: D4.C, MOD1.P$18 (5V)
BZUK_DRAIN: REP1.-, T1.3 (D)
C: PIN_C.1, PIN_SCL.1
CH340-V3: C8.1, IC3.4 (V3)
CHARGE: D6.C, R11.2
D: PIN_D.1, PIN_SDA.1
D2-R6: D1.K, R6.2
DATA_RDY: EXT.P1 (PIN1), MOD1.P$25 (PB2), PIN_R'.1, R12.2
DCDC-SW: D3.C, IC2.2 (VOUT), L1.P$1
E: PIN_E.1, R17.1, T3.1 (G)
E'': PIN_E'.1, R16.2
GND: BAT1.MINUS, C1.C- (C_EL-), C2.C- (C_EL-), C3.2, C4.1, C5.1, C6.1, C7.2, C8.2, C9.2, C10.2, C11.2, D3.A, DZ1.A, EXT.P2 (PIN2), IC1.5 (GND), IC2.3 (GND), IC2.6 (GND_B), IC3.1 (GND), IC4.1 (A0), IC4.2 (A1), IC4.3 (A2), IC4.4 (GND), IC4.7 (WP), IC5.4 (GND), IC5.7 (WP), IC6.5 (GND), JP1-N.5, JP2-N.1, JP2-N.5, JP3-F.4, JP4-F.1, JP5-N.2, JP6-N.2, K2.2 (K2), LED1.G (GND), MICRO_SD1.PAD6 (VSS), MICRO_SD1.SH1, MICRO_SD1.SH2, MICRO_SD1.SH3, MICRO_SD1.SH4, MOD1.P$19 (GND2), PIN_DC-.1, PIN_XG.1, R5.1, R8.1, R12.1, R13.1, R14.1, T1.2 (S), TR1.A, TR2.A, TR3.A, USB1.GND, USB1.P$2 (SHIELD)
GND_SW: B3.1, JP7-F.1
GPS_ZAP: PIN_R.1, PIN_R2.1
LED_RK: LED1.I (IN), R10.1
PA13_SWDIO: B5.1, JP7-F.3
PA14_SWCLK: B4.1, JP7-F.2
PIN_485_DERE: IC1.2 (RE/), IC1.3 (DE), MOD1.P$4 (PB15)
PIN_485_RX_DI: IC1.4 (DI), MOD1.P$33 (PA2)
PIN_485_TX_RO: IC1.1 (RO), MOD1.P$32 (PA3)
PIN_AD_BAT: MOD1.P$35 (PA0), R6.1, R7.1, R8.2
PIN_BZUK: MOD1.P$24 (PB10), R14.2, T1.1 (G)
PIN_DIS_CLK: JP3-F.1, MOD1.P$1 (PB12)
PIN_DIS_DIO: JP3-F.2, MOD1.P$2 (PB13)
PIN_NEO_LED: MOD1.P$34 (PA1), R10.2
PIN_PB14: EXT.P6 (PIN6), MOD1.P$3 (PB14)
PIN_SCL: EXT.P3 (PIN3), IC4.6 (SCL), IC5.6 (SCL), IC6.8 (SCL), JP1-N.1, JP2-N.3, JP5-N.3, JP6-N.3, MOD1.P$14 (PB6), R20.1
PIN_SDA: EXT.P4 (PIN4), IC4.5 (SDA), IC5.5 (SDA), IC6.7 (SDA), JP1-N.2, JP2-N.4, JP5-N.4, JP6-N.4, MOD1.P$15 (PB7), R19.1
PIN_SD_INS: MICRO_SD1.PADCD (INS_DET), MOD1.P$26 (PB1)
PIN_SPI_CS_SD: MICRO_SD1.PAD2 (CD/DAT3), MOD1.P$31 (PA4)
PIN_SPI_MISO: MICRO_SD1.PAD7 (DAT0), MOD1.P$29 (PA6)
PIN_SPI_MOSI: MICRO_SD1.PAD3 (CMD), MOD1.P$28 (PA7)
PIN_SPI_SCK: MICRO_SD1.PAD5 (CLX), MOD1.P$30 (PA5)
PIN_TL_MINUS: JP4-F.4, MOD1.P$11 (PB3)
PIN_TL_OK: JP4-F.2, MOD1.P$12 (PB4)
PIN_TL_PLUS: JP4-F.3, MOD1.P$10 (PA15)
PRED_FUSE: B2.1, F1.P$1, PIN_DC++.1, SW1.PIN_2, T3.3 (D)
REF_U: DZ1.K, MOD1.P$27 (PB0), R9.1
RS485-A-IN: K2.1 (K1), R2.1
RS485-B-IN: K1.2 (K2), R1.1
RS_485_A: IC1.6 (A), R2.2, R3.1, R4.1, TR1.C
RS_485_B: IC1.7 (B), R1.2, R3.2, R5.2, TR2.C
RTC_INT: IC6.3 (/INT), R15.2, T2.2 (S)
SERKOM_RX: IC3.2 (TX), MOD1.P$7 (PA10)
SERKOM_TX: IC3.3 (RX), MOD1.P$6 (PA9), PIN_TX.1
SUPCAP+: D7.A, R11.1, SUPCAP-DIRA.P$1
T2_DRAIN: R16.1, T2.3 (D)
TSL_INT: JP1-N.3
TSL_VIN: JP1-N.6
UBAT: D2.A, K1.1 (K1)
USB+: MOD1.P$9 (PA12)
USB-: MOD1.P$8 (PA11)
USB_D+: IC3.5 (D+), USB1.D+
USB_D-: IC3.6 (D-), USB1.D-
V-USB-IN: F2.P$2, USB1.VBUS
VBAT: BAT1.PLUS2, D7.C, IC6.6 (BAT), MOD1.P$40 (VBAT), R15.1, T2.1 (G)
VBUS-FUSE: C3.1, D1.A, D4.A, D5.A, F2.P$1, IC2.5 (SD), R13.2
VCC-CH340: D5.C, IC3.16 (VCC)
VIN: C1.C+ (C_EL+), F1.P$2, IC2.1 (VIN), R7.2, TR3.C
VIN_ON_OFF: B1.1, D2.C, PIN_DC+.1, R17.2, SW1.PIN_COM, T3.2 (S)
XI: C6.2, IC3.7 (XI), Q1.1
XO: C7.1, IC3.8 (XO), Q1.2
XXX: MOD1.P$21 (XXX)

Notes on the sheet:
(SDO)
(CSB)
(SCK)
(SDI)
(GND)
(VCC)
Schottky
Alternativní napájení STM z USB
Při napájení z USB vypíná DC-DC zdroj
SC1
Jeden pár kontaktů přemostí hlavní spínač, a tím zapne napájení i při vypnutém spínači. Druhý pár zajistí spuštění podprogramu pro záznam času.
*1 *3
*1 ..... Osadit podle schématu při jen použití dálkové komunikace RS485, jinak neosazovat.
*3 ..... Při použití přídavné vnitřní GPS neosazovat svorky - bude sloužit pro připojení 90° kolíky na desku GPS
*4 ..... Při použití přídavné vnitřní GPS provést drátové propojky na spodní straně mezi dírkami D-D'; C- C'; R-R'
drátová propojka: E-E'
*2 ..... Terminátor pro linku RS485 se osazuje jen na konci sběrnice.
9V baterie se v tom případě připojí do dírek na desce GPS. Případná komunikace RS485 se pak také zapojuje do desky GPS.
JP8
JP9
JP8 a JP9 jsou dutinkové lišty 1x20, do kterých je zasunutý modul STM32F411.
*5 ..... Při použití zálohovací baterie se tyto součástky neosazují
*6 ..... Ve verzi se superkapacitorem se zálohovací baterie ani její držák nepoužívají
(k 9V baterii)
(na vstup DC-DC)

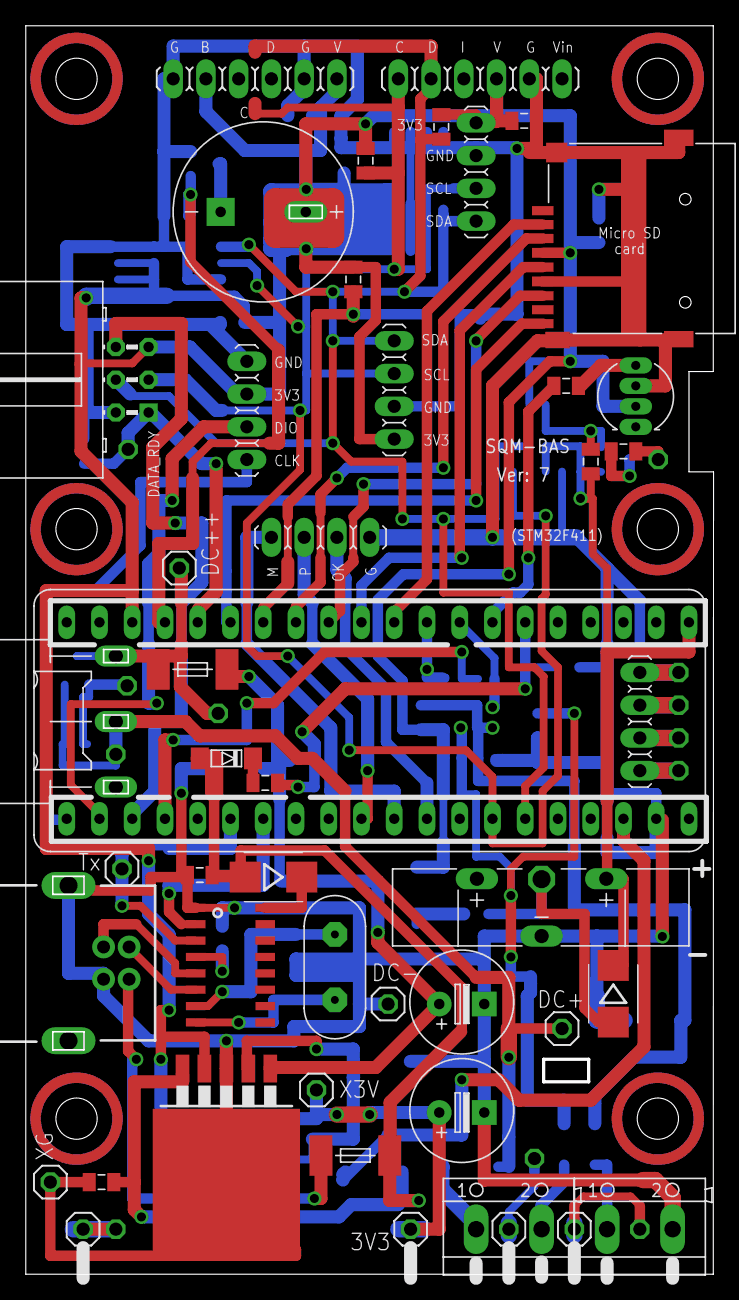
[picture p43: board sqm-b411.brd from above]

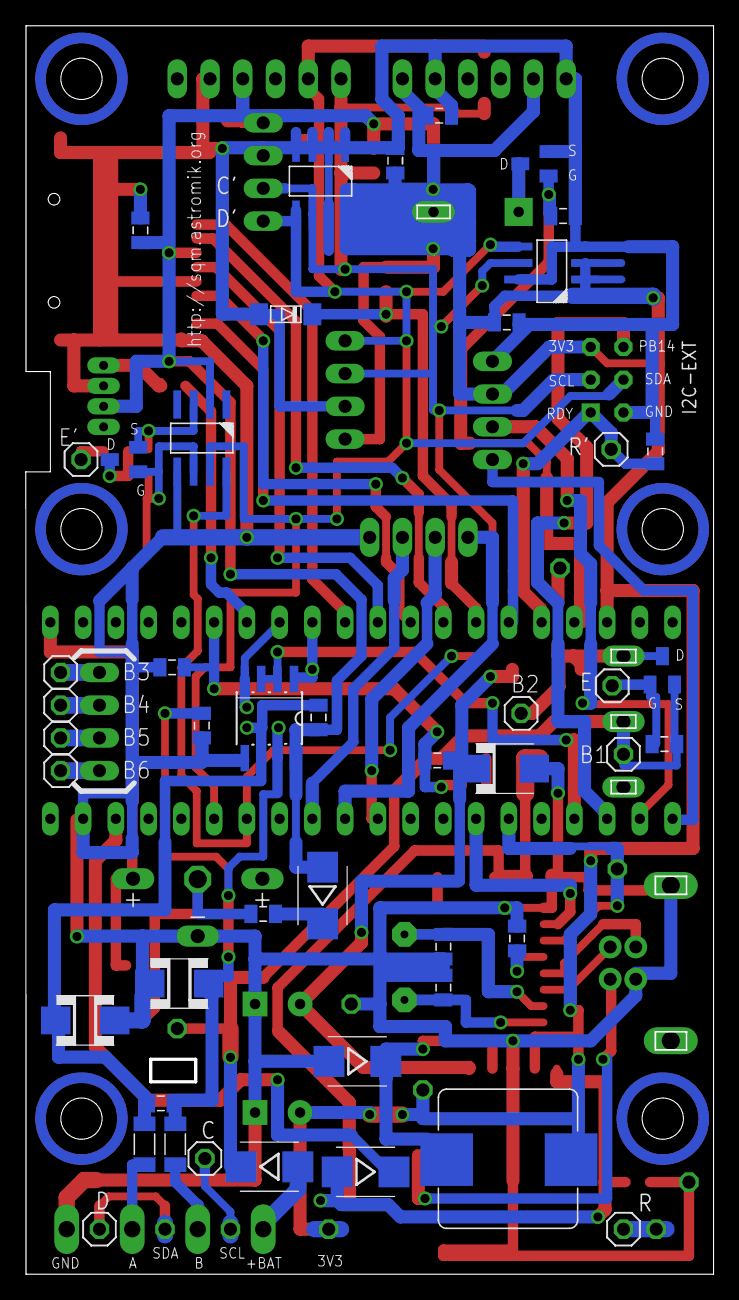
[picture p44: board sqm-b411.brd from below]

Board: 2 copper layers, 53.3 x 96.8 mm, 94 parts (46 on the bottom side), 60 nets.

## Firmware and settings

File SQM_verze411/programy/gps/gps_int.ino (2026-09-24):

// Rozsirujici deska k SQM (SQM-GPS-5 nebo 6) pro zpracovani GPS signalu
//=========================================================================
//  https://sqm.astromik.org
// ----------------------------------


char verzeSW[] = "2026-09-19..INT";                        // 15 znaku popisu verze SW
//  POZOR!
//       V Arduino IDE nastavit hardware (soubor boards.txt) na 4MHz krystal
//       Po nahrani prelozeneho programu pak upravit FUSE:
//                                                       LowFuse   : 0xDC
//                                                       HighFuse  : 0xDE
//                                                       ExtendFuse: 0xF7

// Strucny popis programu
//
// Poloha se zjistuje z GPS modulu (NEO-6M,  ATGM336H ...) pres seriovou linku (Tx, Rx).
// Zpracovavaji se zpravy (vety) GxRMC, GxGGA a GxGSA.
// Druha strana komunikace probiha pres I2C s hlavni SQM deskou.
// Pomoci I2C komunikace je mozne stahnout data (aktualni i zprumerovane souradnice, cas a dalsi informace o GPS modulu).
// Take je mozne pres I2C ovladat LED - docasne vsechny zhasnout (funkce 20) a pak obnovit do puvodniho stavu (funkce 21),
//   nebo provest HOT restart GPS modulu (funkce 22). Funkce 23 byla doplnena pro otestovani vyprseni 4-sekundoveho watchdogu (WDT).
//
// Pri sepnuti servisniho pinu behem zapnuti napajeni se nastavi GPS modul na prijem zprav GxRMC, GxGGA a GxGSA (ostatni zpravy se vypnou).
//   Nastavi se i rychlost odesilani NMEA zprav na 1 sekundu.
//   Do EEPROM se ulozi i typ prijimaciho modulu ve zkracene (15-znakove) verzi. Napriklad "UBX-G60xx000400"
// Pri beznem provozu se spojenim servisniho pinu na GND rozblikaji vsechny LED frekvenci 1Hz (strida 50%)
//   Po 5 sekundach spojeni dochazi k prepinani faze blikani LED1. Nektere GPS moduly odesilaji NMEA zpravy v obracenem poradi a to zpusobuje, 
//     ze LED1 blika s vyrazne delsim rozsvicenym stavem. Po prepnuti faze se pak usetri trochu energie a snizi celkove vyzarovani svetla z SQM.
//     Prepnuti faze je signalizovano rychlym zablikanim LED1.
// 3 signalizacni LEDky informuji o stavu GPS modulu:
//   LED1 - prepina se podle prave zpracovavane vety -  blikani je spravny stav, modul NEO-6M vysila 
//   LED2 - stav prijmu datumu a casu (cas neni k dispozici - sviti / cas je k dispozici - zhasnuto)
//   LED3 - dostupnost souradnic 
//                     sviti = souradnice jeste nejsou k dispozici, neni zafixovano ani na jeden satelit
//                     blika = je zafixovano alespon na 1 satelit, ale jeste nejsou souradnice, nebo pocet prijatych souradnic nestaci na prumerovani (mene nez 10)
//                     nesviti = vsechno je v poradku, souradnice jsou k dispozici (pocet OK souradnic je 10 a vice) 
//   Spravny stav je tedy takovy, ze blika LED1 a ostatni LED jsou zhasnute.
//   V pripade, ze blika LED1 a LED2 je zhasnuta, dojde pri mereni jasu automaticky k serizeni casu v RTC na hlavni desce SQM-BAS. 

// Data se do SQM odesilaji pomoci 39 8-bitovych registru 
// priklad exportnich dat:
//  0 ---  8        prumer LAT (pro severni polokouli zvetseny o 90 stupnu)
//  1 ---  79
//  2 --- 192
//  3 --- 172

//  4 ---  11       prumer LON (pro vychodni polokouli zvetseny o 180 stupnu)
//  5 --- 149
//  6 --- 204
//  7 --- 147

//  8 --- 100       OK cnt (pocet bezchybnych zafixovanych dat v rade)

//  9 ---  21       YY     (datum a cas z GPS - v GMT zone)
// 10 ---   1       MM
// 11 ---   1       DD
// 12 ---  11       HH
// 13 ---  49       NN
// 14 ---  22       SS

// 15 ---   1       Nadmorska vyska zvysena o 500m
// 16 --- 241

// 17 ---  58       10x PDoP (Position Dilution of Precision) ... mensi cislo = vetsi presnost
// 18 ---  23       10x HDoP (Horizontal Dilution of Precision) ... mensi cislo = vetsi presnost
// 19 ---  83       10x VDoP (Vertical Dilution of Precision) ... mensi cislo = vetsi presnost
// 20 ---  50       rychlost 0 az 130 km/h v logaritmicke stupnici (nizke rychlosti maji vetsi rozliseni, vysoke rychlosti jsou ulozene nepresne)
// 21 ---   6       status bajt:
//                      bity 0 az 3 .... pocet satelitu
//                      bit 4 = '0' pole klouzaku jeste neni zaplneno
//                      bit 4 = '1' pole klouzaku zaplneno, muzou se stahovat data
//                      bit 5 = '0' cas se do RTC nezapise (v GPS nejsou casove znacky)
//                      bit 5 = '1' pri stazeni dat se do RTC ulozi cas z GPS (pokud bude k dispozci)
//                      bity 6 a 7  kvalita (spolehlivost) souradnic
//                                  "00" ....  OK    data se zapisuji do GPX souboru a pocitaji se z nich statistiky
//                                  "01" .... WAR    data se do GPX souboru zapisuji, ale oznacuji se znackou varovani a nepocitaji se do statistik
//                                  "10" .... BAD    data se do GPX souboru nezapisuji
//                                  "11" .... OFF    filtrovani je vypnute, vsechny zaznamy se zapisuji jako v predchozich verzich programu
//
// 22 ---  8        aktualni (posledni) LAT bez prumerovani (pro severni polokouli zvetseny o 90 stupnu)
// 23 ---  79
// 24 --- 192
// 25 --- 172
// 26 ---  11       aktualni (posledni) LON bez prumerovani (pro vychodni polokouli zvetseny o 180 stupnu)
// 27 --- 149
// 28 --- 204
// 29 --- 147
// 30 ---   1       aktualni (posledni) nadmorska vyska zvysena o 500m
// 31 --- 241
//
//

//   Servisni data v EXPORT_pole[] - jen pro vyvoj filtru pro rozpoznavani ztraty fixu v pripade potreby stahovat prikazem 11
// 32 ---  typ fixu (1=nofix, 2=2D fix, 3=3D fix)
// 33 ---  100x Speed over Ground prevedene na [m/s] MSB
// 34 ---                                            LSB
//
// 35 ---  100x rychlost podle souradnic v [m/s] MSB
// 36 ---                                        LSB
//
// 37 ---  rozdil nadmorskych vysek v po sobe jdoucich zpravach [m]
//
// 38 ---  bitova znacka ktera udava, ktery filtr kvality souradnic byl aktivovany
//
// 39 --- skutecny pocet satelitu (ve status registru je pocet omezeny jen na 4 bity, tady je skutecny pocet)
//
//   Na zvlastni pozadavek odeslany pres I2C sbernici (prikazy 50 az 55, 60 az 65 a 90 az 95) je mozne si vyzadat i kompletni
//           obsah poslednich NMEA vet GxRMC, GxGGA a GxGSA. Vety se zpatky do SQM odesilaji po 15 znacich.
//   Pri pozadavku s kodem 70 se vrati 15-znakovy text s verzi programu (yyyy-mm-dd..INT)
//   Pri pozadavku s kodem 80 se vrati 15-znakovy text s HW verzi prijimaci desky
//   Pozadavek s kodem 200 vypina experimentalni funkci pro filtrovani nestabilnich souradnic
//   Pozadavek s kodem 201 experimentalni funkci pro filtrovani nestabilnich souradnic zase zapne (defaultne zapnuta)
//   Debugovaci pozadavek 11 vypise informace o filtrovani souradnic pred ztratou fixu
//======================================================================================================================


#define F_CPU 4000000UL

#include <Wire.h>                                          // knihovna pro I2C komunikaci
#include <EEPROM.h>                                        // knihovna pro vnitrni EEPROM
#include <avr/wdt.h>                                       // knihovna pro watchdog


#define pin_LED1            2
#define pin_LED2            3
#define pin_LED3            4

#define pin_setup           6                              // pri prizemneni behem resetu se do GPS modulu odesle prikaz pro povoleni GxGGA, GxRMC a GxGSA vety a toto nastaveni se ulozi do vnitrni EEPROM GPS modulu
                                                           // pri prizemneni za chodu se meni strida blikanio spodni LED1

#define pin_dta_rdy        A1                              // signalizace pro SQM, ze je modul GPS zapnuty

#define I2C_ADDR_GPS     0x17                              // I2C adresa pridavneho modulu pro GPS

// do retezce 'veta' se budou zapisovat vsechna prijata data z GPS
char veta[]     = "                                                                                            @\0";

//                 $GPRMC,110109.00,A,4926.67723,N,01421.99214,E,0.521,,311220,,,A*72
char veta_RMC[] = "                                                                                            @\0";

//                 $GPGGA,103515.00,4926.65079,N,01421.99995,E,1,05,4.92,499.9,M,44.3,M,,0000*5C
char veta_GGA[] = "                                                                                            @\0";

//                 $GNGSA,A,3,65,67,80,81,82,88,66,08,09,10,11,12,1.2,0.7,1.0*20
char veta_GSA[] = "                                                                                            @\0";


//   POZOR! Nektere prijimace, ktere kombinuji prijem vice druzicovych systemu (GPS, GLONASS, BEIDOU), misto "GPRMC" a "GPGGA" vraci retezce "GNRMC" a "GNGGA"
//                Treti znak ve zprave je tedy nutne pri zpracovani zprav ignorovat


char rozlozeny_pole[18][28];                               // vety se sem do toho pole rozkladaji na jednotlive polozky (puvodne byly ve vete oddelene carkami)

byte    ukazatel_klouzaku;
long    klouzak_LAT[10];                                   // pole pro prumerovani zjistenych souradnic (znamenkove)
long    klouzak_LON[10];
float   klouzak_ALT[10];
boolean pripraveno = false;                                // az bude zaznamenany alespon 1 blok klouzaku (10 vzorku), tak se da pocitat prumer 

byte volatile prikaz_I2C;                                  // z SQM (MASTER) se da do modulu (SLAVE) poslat prikaz:
                                                           //   0 = bez prikazu (predchozi prikaz byl vykonan)
                                                           //  10 = zadost o zpacovana data
                                                           //  20 = zhasnout docasne vsechny LED (pri mereni jasu)
                                                           //  21 = obnovit puvodni svit LED
                                                           // 50 az 55 = stahnout 15 bajtu dlouhy blok textu ze zpravy GxRMC (dohromady az 90 znaku)
                                                           // 60 az 65 = stahnout 15 bajtu dlouhy blok textu ze zpravy GxGGA (dohromady az 90 znaku)
                                                           // 70       = stahnout 15 bajtu dlouhy blok textu s verzi programu
                                                           // 80       = stahnout 15 bajtu dlouhy blok textu s verzi HW prijimace NEO
                                                           // 90 az 95 = stahnout 15 bajtu dlouhy blok textu ze zpravy GxGSA (dohromady az 90 znaku)
                                                           

boolean  stav_LED_1;                                       // kvuli zhasinani a obnovovavni LED pre I2C prikaz se musi zapamatovat aktualni stav LED
boolean  stav_LED_2;
boolean  stav_LED_3;

boolean  pamet_LED_1;                                      // kvuli zhasinani a obnovovavni LED pre I2C prikaz se musi zapamatovat stav LED pred zhasnutim
boolean  pamet_LED_2;
boolean  pamet_LED_3;

boolean ignoruj_vetu;                                      // kdyz se prijme veta, o kterou nemam zajem

byte OK_byte;                                              // pocitadlo nepretrzitych prijatych dat


byte CRC_end;                                              // na ktere pozici ve vete se objevila '*' (pouzito pro vypocet CRC)
byte ukazatel;
byte EXPORT_pole[40];                                      // sem se ukladaji zpracovana data z GPS a odsud se pak preposilaji pres I2C

char rd;

byte aktivace_dta_rdy = 0;                                 // "pin_dta_rdy" se prepina do HIGH az kdyz se podari alespon 1x nacist z modulu GPS obe NMEA vety (GGA i RMC)

unsigned long starttime;
char typ_vety;                                             // aktualni typ prijate vety ('M' , 'G' nebo 'S')
char ocekavana_veta = 'M';                                 // zacina se s prijmem vety GxRMC


byte veta1[]     = { 'G', 'G', 'A'};                       // prvni povolena veta je GxGGA
byte veta2[]     = { 'R', 'M', 'C'};                       // druha povolena veta je GxRMC
byte veta3[]     = { 'G', 'S', 'A'};                       // treti povolena veta je GxGSA

byte prijate_CRC [] = { 'A', 'B'};                         // posledni dva znaky za hvezdickou z kazde vety se ukladaji sem a pak se porovnavaji s vypoctenym CRC

char EW_polokoule[10] ;                                    // reseni problemu s prumerovanim delky podel 180. poledniku (Tichy ocean) 
                                                           //  V tech mistech se muze stridave prijimat zemepisna delka +180 a -180 stupnu. To se neda zprumerovat


byte statusy_LED;                                          // promenna, do ktere se prubezne uklada pozadovany stav 3 LED (bit0=LED1; bit1=LED2; bit2 = LED3; 
                                                           //                                                              bit5=blikani LED3 nadrazene nad bit2 )
boolean zhasnuto;                                          // pri docasnem zhasnuti blokuje dalsi rozsveceni LED

boolean blik3;                                             // pouzito pro blikani 3. LED

byte faze_LED1;                                            // protoze neni mozne urcit poradi zprav GGA, RMC a GSA. Muze spodni LED blikat s velkou stridou 
                                                           //  zmenou teto promenne je mozne v servisnim nastaveni zvolit takovy rezim blikani, ktery rozsviti LED jen kratce
unsigned long cas_prvniho_cyklu;                           // pro podprogram na zmenu faze LED1 (5-sekundovy odpocet drzeni servisniho pinu v LOW)
boolean prvni_cyklus;

byte pocet_satelitu;


float PDoP_f;
float HDoP_f;
float VDoP_f;

float Pfloat_f;
float Hfloat_f;
float Vfloat_f;

float Pfloat;
float Hfloat;
float Vfloat;


// pro analyzu signalu mezi nasledujicimi zpravami
uint16_t  predchozi_geoalt;                                // nadmorska vyska v predchozi zprave pro vypocet vyskoveho skoku pri filtrovani souradnic
uint16_t  aktual_geoalt;                                   // posledni zjistena nadmorska vyska

int32_t   predchozi_LAT;                                   // aktualni a predchozi souradnice pro urceni nerealnych skoku pri ztrate signalu (prevedeno na miliontiny stupne)
int32_t   predchozi_LON;
int32_t   aktualni_LAT;
int32_t   aktualni_LON;
float     speed_lat_lon;                                   // vypoctena rychlost na zaklade vzdalenosti mezi souradnicemi ze sousednich zprav a casu prechozich souradnic
uint32_t  aktualni_cas_rych;                               // cas ziskani aktualnich souradnic (rozdil aktualniho casu a casu poslednich souradnic urcuje rychlost skoku)
uint32_t  predchozi_cas_rych;                              // cas ziskani predchozich souradnic (rozdil aktualniho casu a casu poslednich souradnic urcuje rychlost skoku)
bool      pocitej_rychlost = false;                        // po ztrate fixu se vzdalenost nepocita, protoze by dochazelo k deleni nulou

uint8_t typ_fixu;
uint8_t predchozi_typ_fixu;

float SoG;                                                 // Speed over Ground ze zpravy RMC (v uzlech)

uint8_t filtr_ON_OFF;                                      // moznost ovladat fitrovani souradnic pri ztrate signalu


unsigned long blik500;                                     // casovani 500ms pro servisni blikani vsech LED
boolean stav500;                                           // pro prepinani stavu LED pri servisnim blikani
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
void loop(void)
  {
    wdt_reset();                                                                                 // v kazde smycce se resetuje WDT (nesmi se prekrocit 4 sekundy)
    
    ignoruj_vetu = false;
    if(prikaz_I2C == 0)
      {
        if (Serial.available())                                                                  // kdyz se neco objevi na seriove lince z GPS modulu
          {
            CRC_end = 1;
    
            while( rd != '$')   rd = Serial.read();                                              // cekani na zacatek vety
            ukazatel = 0;
            veta[ukazatel] = rd;                                                                 // '$' je vzdycky na zacatku
            starttime = millis();
            while (rd != '\r' and (millis() - starttime) < 700 and ukazatel < 90)                // kdyz uz je znamy zacatek vety, musi se zbytek vety stahnout do 0.7 sekundy nebo do 90 znaku
              {
                if (Serial.available())
                  {
                    rd = Serial.read();
                    if (rd == '*') CRC_end = ukazatel;                                           // znacka, do ktereho znaku se bude pocitat CRC
                    ukazatel++;
                    veta[ukazatel] = rd;                                                         // vsechny prijate znaky se zapisuji do znakoveho pole 'veta[]'
                  }
              }

           // tady v tom miste je poli 'veta[]' nactena cela veta z NEO modulu (nezavisle na typu - treba tam muze byt veta GxVTG)

           ignoruj_vetu = true;
           if (veta[3] == veta1[0] and veta[4] == veta1[1] and veta[5] == veta1[2])              // jedna se o povolenou vetu GxGGA
             {
               ignoruj_vetu = false;                                                             // veta se tedy bude zpracovavat
               typ_vety = 'G';                                                                   //    a jeste znacka, ze je to veta GGA
             }

           if (veta[3] == veta2[0] and veta[4] == veta2[1] and veta[5] == veta2[2])              // jedna se o povolenou vetu GxRMC
             {
               ignoruj_vetu = false;                                                             // veta se tedy bude zpracovavat
               typ_vety = 'M';                                                                   //    a jeste znacka, ze je to veta RMC
             }   

           if (veta[3] ==  veta3[0] and veta[4] == veta3[1] and veta[5] == veta3[2])              // jedna se o povolenou vetu GxGSA
             {
               ignoruj_vetu = false;                                                             // veta se tedy bude zpracovavat
               typ_vety = 'S';                                                                   //    a jeste znacka, ze je to veta GSA
             }   

    
            if (ignoruj_vetu == false)                                                           // kdyz je nactena nejaka povolena veta, tak se zpracuje
              {

                byte blok = 0;                                                                   // rozlozeni vety na jednotlive bloky mezi carkami
                byte pozice = 0;
                byte rad = 0;
                char znak = ' ';
                while (znak != '\r' and pozice < 90 )
                  {
                    znak = veta[pozice];
                    if (typ_vety == 'G') veta_GGA[pozice] = znak;
                    if (typ_vety == 'M') veta_RMC[pozice] = znak;
                    if (typ_vety == 'S') veta_GSA[pozice] = znak;
                    
                    if (znak == ',' or znak == '*')
                      {
                        rozlozeny_pole[blok][rad] = '\0';
                        blok ++;
                        rad = 0;
                      }
                    else
                      {
                        rozlozeny_pole[blok][rad] = znak;
                        rad ++;                
                      }
                    pozice ++;
                  }            


                while (pozice < 90)                                                              // kompletni smazani aktualne zpracovavane vety pred jejim naplnenim novymi daty
                  {
                     if (typ_vety == 'G')   veta_GGA[pozice] = ' ';
                     if (typ_vety == 'M')   veta_RMC[pozice] = ' ';
                     if (typ_vety == 'S')   veta_GSA[pozice] = ' ';
                     pozice ++;
                  }

                switch (typ_vety)
                  {
                    case 'G':
                       if (ocekavana_veta == 'G')  zpracuj_vetu_GxGGA();
                       break;
                    case 'M':
                       if (ocekavana_veta == 'M')  zpracuj_vetu_GxRMC();
                       break;
                    case 'S':
                       if (ocekavana_veta == 'S')  zpracuj_vetu_GxGSA();
                       break;
                  }

                wdt_reset();
    
                byte i;
                for (i = 0 ; i < 90 ; i ++)                                                      // po zpracovani prislusne vety se pole veta[] smaze
                  {
                    veta[i] = ' ';
                  }
                veta[i+1] = '\0';
              }
          }

      }

    if (aktivace_dta_rdy == 0b11)                                                                // Na prijem se testuji jen vety GGA a RMC a obe vety byly alespon 1x prijaty
      {                                                                                          //    Veta GSA s aktivaci pinu neovlivnuje - i kdyby nedorazila, tak se vystup aktivuje
        digitalWrite(pin_dta_rdy, HIGH);                                                         // "pin_dta_rdy" se prepne na HIGH
      }

    obsluha_LED();


  }
//======================================================================================================================
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

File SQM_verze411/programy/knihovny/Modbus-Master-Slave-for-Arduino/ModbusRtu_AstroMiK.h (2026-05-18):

/**
 * @file 	ModbusRtu.h
 * @version     1.21 (doplneni "AstroMiK")
 * @date        2016.02.21
 *     2023.12.18  !!MIK-1!!- doplneni knihovny o zjisteni kodu posledni pozadovane funkce "getLastFunction()"
       2024.01.06  !!MIK-2!!- rozsireni bufferu z 64 bajtu na 90 bajtu

 * @author 	Samuel Marco i Armengol
 * @contact     sammarcoarmengol@gmail.com
 * @contribution Helium6072
 * @contribution gabrielsan
 *
 * @description
 *  Arduino library for communicating with Modbus devices
 *  over RS232/USB/485 via RTU protocol.
 *
 *  Further information:
 *  http://modbus.org/
 *  http://modbus.org/docs/Modbus_over_serial_line_V1_02.pdf
 *
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
 * @defgroup setup Modbus Object Instantiation/Initialization
 * @defgroup loop Modbus Object Management
 * @defgroup buffer Modbus Buffer Management
 * @defgroup discrete Modbus Function Codes for Discrete Coils/Inputs
 * @defgroup register Modbus Function Codes for Holding/Input Registers
 *
 */

#include <inttypes.h>
#include "Arduino.h"


/**
 * @struct modbus_t
 * @brief
 * Master query structure:
 * This includes all the necessary fields to make the Master generate a Modbus query.
 * A Master may keep several of these structures and send them cyclically or
 * use them according to program needs.
 */
typedef struct
{
    uint8_t u8id;          /*!< Slave address between 1 and 247. 0 means broadcast */
    uint8_t u8fct;         /*!< Function code: 1, 2, 3, 4, 5, 6, 15 or 16 */
    uint16_t u16RegAdd;    /*!< Address of the first register to access at slave/s */
    uint16_t u16CoilsNo;   /*!< Number of coils or registers to access */
    uint16_t *au16reg;     /*!< Pointer to memory image in master */
}
modbus_t;

enum
{
    RESPONSE_SIZE = 6,
    EXCEPTION_SIZE = 3,
    CHECKSUM_SIZE = 2
};

/**
 * @enum MESSAGE
 * @brief
 * Indexes to telegram frame positions
 */
enum MESSAGE
{
    ID                             = 0, //!< ID field
    FUNC, //!< Function code position
    ADD_HI, //!< Address high byte
    ADD_LO, //!< Address low byte
    NB_HI, //!< Number of coils or registers high byte
    NB_LO, //!< Number of coils or registers low byte
    BYTE_CNT  //!< byte counter
};

/**
 * @enum MB_FC
 * @brief
 * Modbus function codes summary.
 * These are the implement function codes either for Master or for Slave.
 *
 * @see also fctsupported
 * @see also modbus_t
 */
enum MB_FC
{
    MB_FC_NONE                     = 0,   /*!< null operator */
    MB_FC_READ_COILS               = 1,	/*!< FCT=1 -> read coils or digital outputs */
    MB_FC_READ_DISCRETE_INPUT      = 2,	/*!< FCT=2 -> read digital inputs */
    MB_FC_READ_REGISTERS           = 3,	/*!< FCT=3 -> read registers or analog outputs */
    MB_FC_READ_INPUT_REGISTER      = 4,	/*!< FCT=4 -> read analog inputs */
    MB_FC_WRITE_COIL               = 5,	/*!< FCT=5 -> write single coil or output */
    MB_FC_WRITE_REGISTER           = 6,	/*!< FCT=6 -> write single register */
    MB_FC_WRITE_MULTIPLE_COILS     = 15,	/*!< FCT=15 -> write multiple coils or outputs */
    MB_FC_WRITE_MULTIPLE_REGISTERS = 16	/*!< FCT=16 -> write multiple registers */
};

enum COM_STATES
{
    COM_IDLE                     = 0,
    COM_WAITING                  = 1

};

enum ERR_LIST
{
    ERR_NOT_MASTER                = -1,
    ERR_POLLING                   = -2,
    ERR_BUFF_OVERFLOW             = -3,
    ERR_BAD_CRC                   = -4,
    ERR_EXCEPTION                 = -5
};

enum
{
    NO_REPLY = 255,
    EXC_FUNC_CODE = 1,
    EXC_ADDR_RANGE = 2,
    EXC_REGS_QUANT = 3,
    EXC_EXECUTE = 4
};

const unsigned char fctsupported[] =
{
    MB_FC_READ_COILS,
    MB_FC_READ_DISCRETE_INPUT,
    MB_FC_READ_REGISTERS,
    MB_FC_READ_INPUT_REGISTER,
    MB_FC_WRITE_COIL,
    MB_FC_WRITE_REGISTER,
    MB_FC_WRITE_MULTIPLE_COILS,
    MB_FC_WRITE_MULTIPLE_REGISTERS
};

#define T35  5
//#define  MAX_BUFFER  64	//!< maximum size for the communication buffer in bytes        !!MIK-2!!
#define  MAX_BUFFER  90	//!< maximum size for the communication buffer in bytes          !!MIK-2!!

/**
 * @class Modbus
 * @brief
 * Arduino class library for communicating with Modbus devices over
 * USB/RS232/485 (via RTU protocol).
 */
class Modbus
{
private:
    Stream *port; //!< Pointer to Stream class object (Either HardwareSerial or SoftwareSerial)
    uint8_t u8id; //!< 0=master, 1..247=slave number
    uint8_t u8txenpin; //!< flow control pin: 0=USB or RS-232 mode, >1=RS-485 mode
    uint8_t u8state;
    uint8_t u8lastError;
    uint8_t au8Buffer[MAX_BUFFER];
    uint8_t u8BufferSize;
    uint8_t u8lastRec;
    uint16_t *au16regs;
    uint16_t u16InCnt, u16OutCnt, u16errCnt;
    uint16_t u16timeOut;
    uint32_t u32time, u32timeOut, u32overTime;
    uint8_t u8regsize;
    uint8_t lastFunction;

    void sendTxBuffer();
    int8_t getRxBuffer();
    uint16_t calcCRC(uint8_t u8length);
    uint8_t validateAnswer();
    uint8_t validateRequest();
    void get_FC1();
    void get_FC3();
    int8_t process_FC1( uint16_t *regs, uint8_t u8size );
    int8_t process_FC3( uint16_t *regs, uint8_t u8size );
    int8_t process_FC5( uint16_t *regs, uint8_t u8size );
    int8_t process_FC6( uint16_t *regs, uint8_t u8size );
    int8_t process_FC15( uint16_t *regs, uint8_t u8size );
    int8_t process_FC16( uint16_t *regs, uint8_t u8size );
    void buildException( uint8_t u8exception ); // build exception message
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

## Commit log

2026-05-21 Doplnění kalibračních tabulek
    Do složky "zbytky" doplněny zapomenuté kalibrační tabulky.
    [kalibracni_tabulky.xls]
2026-05-22 Doplnění "HELP" souborů
    Doplnění balíku souborů s detailními nápovědami k funkcím na SD kartu do složky "\HELP"
    [seznam_napoved.xls]
2026-05-24 Přesun části kódu do jiného repozitáře
    Části kódu pro kalibrátor (otočný podstavec pro měření směrových charakteristik SQM) byly přesunuty do zatím neveřejného repozitáře, protože ještě nejsou dodělané.
    [kalib103_v2b.brd, kalib103_v2b.sch, kalibrator_partlist.xls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]
2026-05-24 Přesun složky HELP
    Složka HELP s detailními popisy funkcí, která má být umístěna na SD kartě byla v rámci repozitáře přesunuta z původní složky "programy\sd\" do složky "navody\sd\".
    [seznam_napoved.xls]
2026-05-24 Úpravy v podkladech SQM-BAS
    Vyhozena složka s objednávkou u JLCPCB. Doplněn gerberovský ZIP.
    [sqm-b411-7.brd, sqm-b411-7.sch]
2026-06-13 Doplnění funkce "Astro Simulace"
    V menu "Astro" je možné zapnout položku "Simulace", která umožní astronomické výpočty pro zadané datum a čas. Tento datum a čas se zadává v menu "dAtuM", "CAS " a "ZonA". Při zapnuté simulaci nemá přenastavení těchto hodnot vliv na vnitřní časovač. Po resetu se simulace automaticky vypíná a výpočty probíhají obvyklým způsobem pro aktuální datum a čas.
    [astro.ino, displej.ino, ds3231.ino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]
2026-06-13 Doplnění BIN souborů pro STM32CubeProgrammer
    Poslední verze programu 2026-06-13 pro procesory STM32F401 a STM32F411, které je možné nahrát i bez Arduino IDE přímo do procesorové desky přes USB nebo STlink programem STM32CubeProgrammer.
2026-08-14 Oprava určování stability azimutu kolem severu
    Snad už poslední verze pro zpracování azimutu. Minulá verze špatně určovala rozsah mezi minimálním a maximálním azimutem při přechodu 0°. Při porovnání s maximálním povoleným rozptylem azimutů pak vycházel rozptyl větší, než je povolený. Ve výsledku pak byla ukládána poslední hodnota zvětšená o 500 a k žádnému průměrování nedocházelo. Tuto poslední verzi jsem nechal zkontrolovat dvěma AI a oba mi potvrdili, že už by to mělo být správně.
    [kompas.ino]
2026-09-24 Oprava počtu satelitů u GNSS
    Oprava pro: https://github.com/astromik/SQM/issues/15#issue-5511296583
    [gps_int.ino]

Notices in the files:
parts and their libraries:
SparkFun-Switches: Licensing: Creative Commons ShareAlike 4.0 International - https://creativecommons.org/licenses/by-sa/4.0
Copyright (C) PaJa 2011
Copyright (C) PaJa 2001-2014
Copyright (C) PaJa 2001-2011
